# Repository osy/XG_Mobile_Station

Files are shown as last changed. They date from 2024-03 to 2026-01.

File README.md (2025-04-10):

XG Mobile Dock
==============
This open source hardware allows you to connect any PCIe card to an ASUS ROG device with the XG Mobile connector.

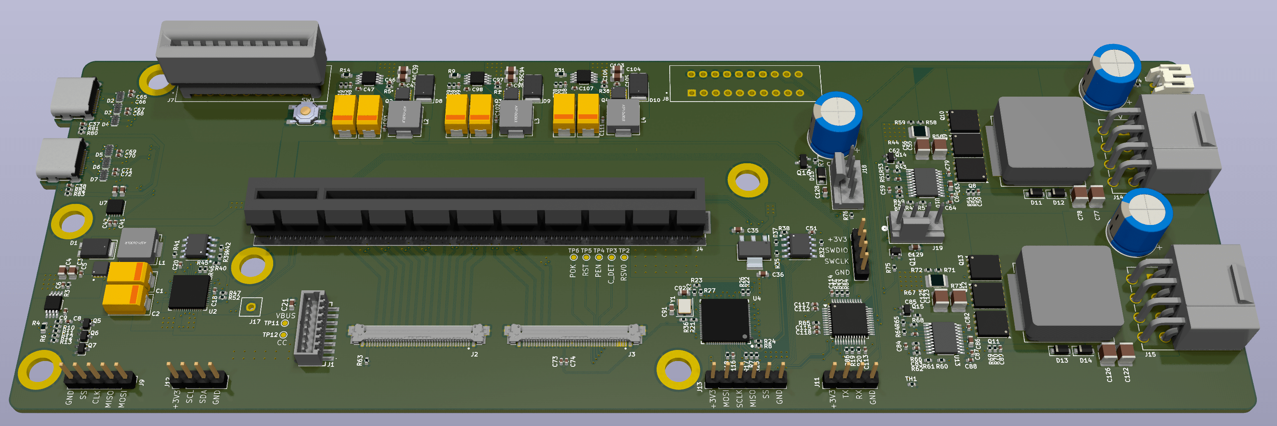
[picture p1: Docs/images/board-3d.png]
Board 3D model


The standard variant is a drop-in replacement PCB for the [XG Station Pro Thunderbolt 3 eGPU dock][1]. It contains a built in USB 3.1 Gen 2 hub and a USB PD charger.

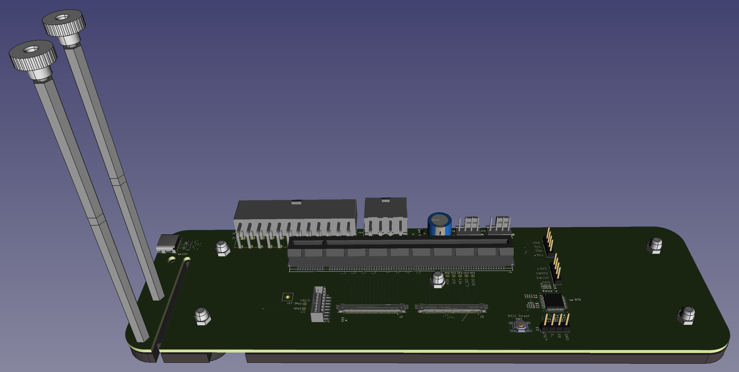
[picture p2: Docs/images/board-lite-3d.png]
Board 3D model


The lite variant is a standalone board that is compatible in dimensions with the [ADT-UT3G][6]. It requires a standard ATX power supply and passes through the USB to an external port.

## Features
* Up to PCIe 4.0 x8 support for 2021/2022/2023 ROG Flow
* Up to PCIe 4.0 x4 support for 2023 ROG Ally
* MCU handling cable detection and LEDs
* 65W USB PD charger (standard variant)
* 2 USB-C ports connected to a USB 3.1 Gen 2 hub (standard variant)
* 300W DC-DC power supply (standard variant)

## Getting Started
1. [Build the PCB](Docs/Build_Guide.md)
2. [Flash the board](#flashing-firmware)
3. [Install the software](#install-xgmactivator)

### Flashing Firmware
Lite boards only need to flash STM32 while the standard board requires writing two SPI flash as well.

#### STM32 MCU
1. Download `XG_Mobile_Dock_MCU.bin` from the latest release or [build your own](Docs/Build_Guide.md#mcu).
2. Download and install [ST32CubeProgrammer][2].
3. Connect your ST-LINK v2 to your computer. Note if you are using a cheap clone from Amazon or Aliexpress, the pin numbers printed on the device may be incorrect.
4. Connect the SWDIO, SWCLK, and GND pins to J10 on the board to the ST-LINK v2. Do not connect +3V3. If you are using an official ST-LINK, you will need a jumper wire from VAPP (pin 1) to VDD (pin 19).
5. Ensure the board is powered on so it can be programmed.
6. Open ST32CubeProgrammer and go to the "Erasing & programming" page (second icon on the left sidebar).
7. Browse and select the firmware file.
8. Check "Run after programming"
9. Click "Connect" on the right sidebar and then "Start Programming" on the left.

#### SPI Flash for TI USB PD
We will be using a Raspberry Pi, although most other SBC can also work as well as dedicated SPI flashers.

1. [Enable the SPI interface on the Raspberry Pi.][3]
2. Connect GND (Ground), SS (SPI0 CE0), CLK (SPI0 SCLK), MISO (SPI0 MISO), and MOSI (SPI0 MOSI) on J9 [to the Raspberry Pi][4].
3. Open a shell to the Raspberry Pi and install Flashrom: `sudo apt-get install flashrom`
4. Download `XG_Mobile_Dock_Charger.bin` from the latest release or [build your own](Docs/Build_Guide.md#ti-pd-controller).
5. Flash the firmware: `sudo flashrom -p linux_spi:dev=/dev/spidev0.0,spispeed=1000 -w XG_Mobile_Dock_Charger.bin`

#### SPI Flash for VIA USB Hub
We will be using a Raspberry Pi, although most other SBC can also work as well as dedicated SPI flashers.

1. [Enable the SPI interface on the Raspberry Pi.][3]
2. Connect GND (Ground), SS (SPI0 CE0), CLK (SPI0 SCLK), MISO (SPI0 MISO), and MOSI (SPI0 MOSI) on J13 [to the Raspberry Pi][4]. Note the order of the pins is different from J9.
3. Open a shell to the Raspberry Pi and install Flashrom if it is not already installed: `sudo apt-get install flashrom`
4. Download `VL822_Q7_9043_Phantom_20220616.bin` from the latest release.
5. Flash the firmware: `sudo flashrom -p linux_spi:dev=/dev/spidev0.0,spispeed=1000 -w VL822_Q7_9043_Phantom_20220616.bin`

### Install XGMDriver
XGMDriver tricks ARMORY CRATE software into identifying the custom dock as an official XG Mobile device. Once installed, it should work even if ARMORY CRATE software is updated. You can check out the [source code here](XGMDriver).

1. Download `XGMDriverSetup.exe` from the latest release.
2. Run the installer making sure to correctly select AMD or NVIDIA depending on the vendor of the GPU you are installing.
3. If you need to swap between AMD and NVIDIA, uninstall from Control Panel or by running the installer again. Then you can re-install and select the right option.

## Troubleshooting

### Error 43 or no video output on NVIDIA GPUs
This is a well known issue with NVIDIA eGPUs. Once the eGPU is installed along with the correct drivers, you will need to install [this script][5].

### PCIe is only getting 3.0 speeds after hot plugging
You need to restart your device. For some reason, hot plugging results in 3.0 speeds.

### Unable to get 4.0 speeds
If you observe any of the following:
* GPU-Z changes between 4.0 and lower versions *when under load*
* You observe a lot of stuttering or < 10 FPS in 1% lows
* Windows behaves extremely slowly (moving the mouse cursor will take > 1 sec to respond)
* Event viewer for System shows multiple times: "WHEA-Logger Event ID:17 - A corrected hardware error has occurred"

Then the device is having trouble sustaining PCIe 4.0 speeds. This can be caused by any combination of the following issues:

1. The board was not manufactured properly with impedance matching or the high speed connectors were not properly soldered. Verify that the boards were manufactured with the correct specifications and test multiple boards.
2. The GPU is malfunctioning or is not mounted correctly. Make sure you can obtain PCIe 4.0 speeds on a desktop PC.
3. The XGM cable is not connected to the board correctly. Make sure the two 40P connectors are tight and the metal bar is locked over the connector to prevent unintentional loosening. Make sure the shielding screw is tightly screwed to the screw terminal next to the connector. Make sure the cable isn't twisted or bent any more than it needs to be. If the XGM cable came coiled up, try to carefully straighten it.
4. The XGM cable is not manufactured correctly. The official XGM device only supports PCIe 3.0 speeds so the cable is only rated for PCIe 3.0. We found that some cables are easier to get 4.0 speeds working than other cables so there is some manufacturing variance.

You can run FurMark for a long duration and observe the GPU load to check that it is able to maintain 4.0 speeds. If the GPU is constantly trying to switch speeds, you will observe large FPS drops and large dips in the GPU usage percentage. You can also use CUDA-Z to check the access speeds while under load.

If you cannot maintain PCIe 4.0 speeds, you can always do a hot-unplug and hot-plug to force it to run in PCIe 3.0 mode.

### No popup when XGM is connected
Sometimes, the device will not be detected and you can flip the lock switch off and on again to force the software to re-detect the device.

### "It appears that your XG Mobile is not properly connected..."
If you get a pop-up saying XG Mobile is not properly connected, make sure [XGMDriver](#install-xgmdriver) is installed. If this is still an issue with XGMDriver installed, there is likely a connection issue with the cable.

### ASUS Driver install popup on reboot
Re-install XGMDriver to inhibit the ASUS driver popup.

### Lite: USB is not detected
The lite board does not have USB orientation detection. Try flipping the USB-C cable upside down and try again.

## References
Knowledge base for all things XGM gathered from reverse engineering the hardware and software.

* [XGM connector information](Docs/Connector.md)
* [XGM software interfaces](Docs/Software.md)
* [MCU command interface](Docs/MCU.md)
* [PCB design diary](Docs/Diary.md)
* [Reversed ACPI tables](Docs/ACPI_Annotated.asl)
* [Reversed BIOS detection](Docs/BIOS_Detect.c)

## Related Projects

* [Modified Lite design with redrivers for improved performance (not yet working)](https://github.com/Alecu100/XG_Mobile_Station/tree/flow_v2)

[1]: https://www.asus.com/motherboards-components/external-graphics-docks/all-series/xg-station-pro/
[2]: https://www.st.com/en/development-tools/stm32cubeprog.html
[3]: https://www.raspberrypi-spy.co.uk/2014/08/enabling-the-spi-interface-on-the-raspberry-pi/
[4]: https://pinout.xyz
[5]: https://egpu.io/nvidia-error43-fixer
[6]: https://www.adt.link/product/UT3G.html

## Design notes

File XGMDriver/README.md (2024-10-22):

XGM Driver
==========
This UMDF driver provides a virtual HID device that will interface with ARMORY CRATE SE to trigger the activation pop-up.

See [Software.md](../Docs/Software.md) for more details.

## Building

1. Install [Visual Studio 2022 Community Edition and WDK][1].
2. Install [NSIS][2].
3. Run `build.bat`. If prompted to enter a password to protect the generated private key, press "None".

[1]: https://learn.microsoft.com/en-us/windows-hardware/drivers/download-the-wdk
[2]: https://nsis.sourceforge.io/Download

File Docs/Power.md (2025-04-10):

The XG Mobile Station adopts the 20P slot which mates with a daughter card that hosts a special connector that is found on the XG Station Pro's power supply. You may want to replace this card in order to use a higher wattage or smaller sized power supply or to build a custom enclosure for the XG Mobile Station without needing to source the special power supply and daughter card.

## XG Mobile Power

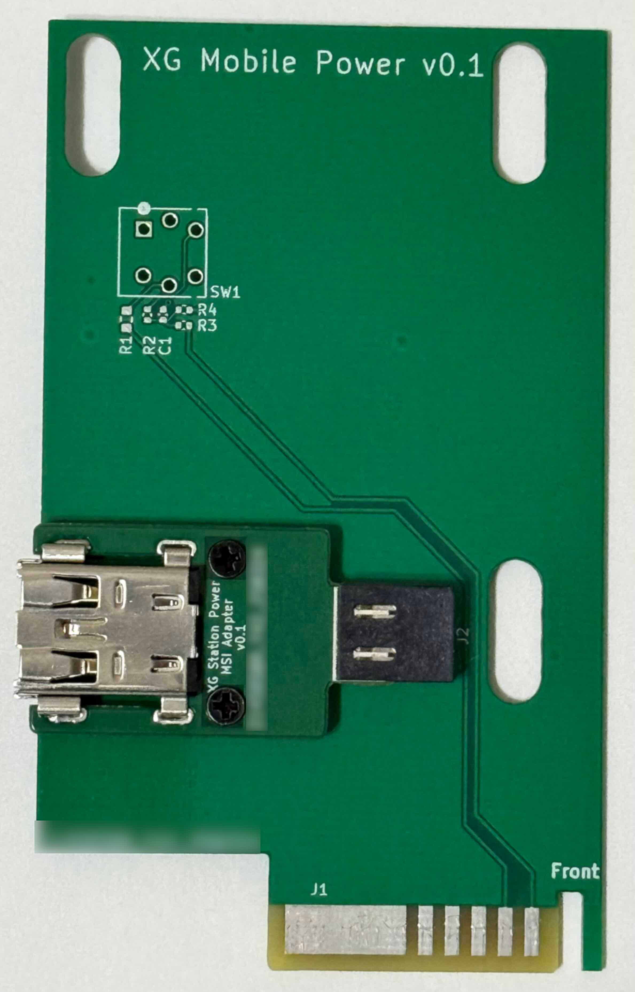
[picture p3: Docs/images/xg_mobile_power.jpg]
XG Mobile Power


The custom power adapter card is built to support the MSI 8P connector, which is used on some high-end MSI laptops. Why choose another proprietary port? The first reason is that there are no "standard" DC power connector that supports 20V at > 16A. The closest is the 7.4mmx5mm barrel jack, but standard parts for this port (PJ-096H) cannot handle more than 8A. Laptop manufactures that uses this port for higher wattages use a proprietary part that does not solder directly to the PCB but instead adapts it to a custom connector. The second reason is that at the time of writing, the highest wattage AC-DC 20V power supply you can easily buy at online retailers is 400W and it uses the MSI 8P connector.

### Parts Needed

* XG Mobile Power board: go to [releases](https://github.com/osy/XG_Mobile_Station/releases) and download `GERBER-XG_Station_Power.zip`. Upload it to a JLCPCB or another manufacturer and purchase it with the default settings.
* XG Mobile Power MSI addon board: go to [releases](https://github.com/osy/XG_Mobile_Station/releases) and download `GERBER-XG_Station_Power_MSI.zip`. Upload it to a JLCPCB or another manufacturer and purchase it with the default settings.
* MSI 8P port: You can find this part on AliExpress with a title such as "MSI GP76 GP66 Charging Port USB Square Connector" for about $1 USD a piece ([example listing](https://www.aliexpress.us/item/3256806058519484.html))
* M2x8 screws
* M2 spacers: They should be 2.3mm thickness or you can stack two 1mm thick spacers ([example listing](https://www.aliexpress.us/item/2251832835568550.html)) with one 0.3mm spacer ([example listing](https://www.aliexpress.us/item/2255799988145316.html))
* M2 brass nut: The length should be at least 2mm ([example listing](https://www.aliexpress.us/item/3256804349544912.html)) 
* [TE 2351970-1 power assembly](https://www.te.com/en/product-2351970-1.html)

### Assembly

Once you have the boards, first solder the MSI 8P connector to the smaller board and the TE 2351970-1 connector to the larger board. Then place the spacer between the two boards and run the screw into the assembly. Thread it into the brass nut on underside of the board.

For XG Mobile Station, you do not need the power button (SW1) and can leave it unpopulated. If you want to use this in the original Thunderbolt 3 enclosure, you need to transfer the switch and the passives under it over from the original board to the custom board.

### 7.4mm Adapter

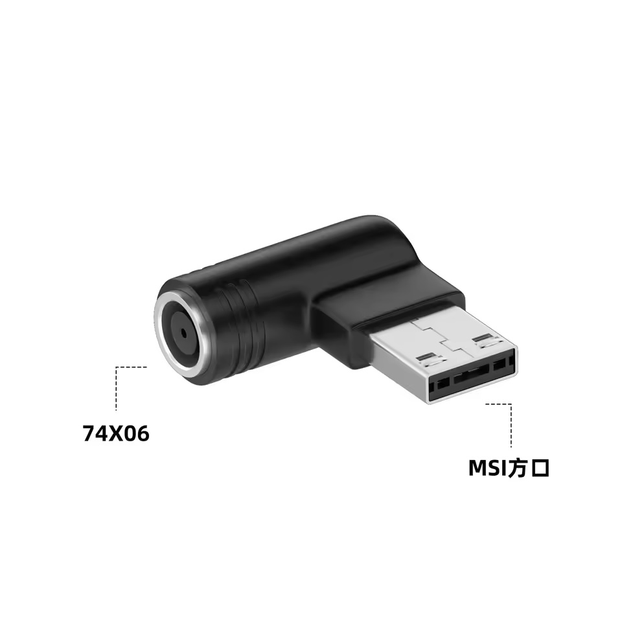
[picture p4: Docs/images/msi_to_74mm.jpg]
7.4mm adapter


You can also purchase a MSI 8P to 7.4mm barrel jack adapter on AliExpress for around $5 USD ([example listing](https://www.aliexpress.us/item/3256807588959754.html)) and this will allow you to use the more common 7.4mm barrel connector. Note that you should avoid the variant which has a cable with two ends because there is no guarantee that the adapter will be able to handle the high current load.

## USB Charging

If you use a higher wattage power supply, you may wish to flash the 100W charging profile found in [releases](https://github.com/osy/XG_Mobile_Station/releases) (titled `XG_Mobile_Dock_Charger_100W.bin`). The default profile will be limited to 65W.

## Example Supplies

Here is a sample selection of high wattage supplies that you can buy on online retailers which are compatible with the XG Mobile Station. Note that any 20V supply will work but a graphics card with 2x 8-pin connectors can draw up to 300W and the USB charger can draw up to 65/100W (depending on the firmware) so you must pick a supply that can handle the load.

| Vendor | Model | Wattage | Connector | Adapter | Notes |
|---|---|---|---|---|---|
| ASUS | ADP-330AB  | 330W | XG Station Pro | Stock | |
| MSI | ADP-400CB  | 400W | MSI 8P | Custom | |
| MSI | ADP-330GB  | 330W | MSI 8P | Custom | |
| Dell | ADP-330AB  | 330W | 7.4mmx5mm Barrel | Custom + MSI-7.4mm Adapter | Same supply as stock, but different connector |
| Dell | LA360PM230 | 360W | 7.4mmx5mm Barrel | Custom + MSI-7.4mm Adapter | GaN based, small size |

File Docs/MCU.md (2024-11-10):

On the real XG Mobile, the MCU is an ITE chip which is a similar design to the Embedded Controller on the Ally. It is responsible for the following:

1. Toggling the [connector signals](Connector.md).
2. Communicating with the host's EC over I2C.
3. Communicating with the [Windows](Software.md#externalgpuconfighelper2dll) over USB HID.

In order to save costs and reduce complexity, our MCU is a STM32 which implements 1 and 2 but not 3. Since the main reason to communicate with Windows is to control fans (not available here) and to pass in serial and model information (can be done with software), we do not implement 3 which requires a USB PHY on the MCU.

## I2C
The I2C/SMBus pins from the connector is hooked up to the host's EC. The MCU communicates with the EC through this I2C bus (in addition to the status pins). The importance of the I2C bus is that upon reboot, a successful handshake must take place or the host will throw a splash image indicating the XG Mobile has been disconnected (see [the code](BIOS_Detect.c) for more details).

These are the commands supported by the real XG Mobile MCU:

| Command (Byte 0) | Byte 1 | Byte 2 | Remaining | Direction | Description |
|---|---|---|---|---|---|
| 0xA0 | Register Number | Length | Data | Host to Device | Write Register  |
| 0xA1 | - | - | 0xD2, 0xDA, 0xDB, or 0xDC | Device to Host | Get event? |
| 0xA2 | - | - | 0x01 or 0x02 | Device to Host | Session status? |
| 0xA3 | - | - | 0x01 | Device to Host | Heartbeat? |

These are the registers:

### Connect Sequence (Boot)

1. Host send: `A0 07 01 01`
2. Host send: `A0 01 01 00`
3. Host send: `A0 0A 01 04`
4. MCU asserts IRQ
5. Host send: `A1`, MCU respond: `DC`, deasserts IRQ
6. Host send: `A2`, MCU respond: `02`
7. Host send: `A0 08 01 01`
8. Host send: `A0 08 01 01`
9. Host send: `A0 09 01 00`
10. Host send: `A0 09 01 01`
11. Host send: `A0 09 01 01`
12. Host send: `A3`, MCU respond: `01` (repeat ad infinitum every second)

### Connect Sequence (XGM Disconnected on Boot)

1. Host send: `A0 07 01 01`
2. Host send: `A0 01 01 00`
3. Host send: `A0 0A 01 01`
4. MCU asserts IRQ
5. Host send: `A1`, MCU respond: `DC`, deasserts IRQ
6. Host send: `A2`, MCU respond: `02`

Press A to continue

1. Host send: `A0 08 01 01`
2. MCU asserts PWROK
3. Host de-asserts RST
4. Host send: `A0 09 01 00`
5. Host send: `A0 09 01 01`
6. Host send: `A0 09 01 01`
7. Host send: `A0 0A 01 02` (only sometimes?)
8. Host send: `A3`, MCU respond: `01` (repeat ad infinitum every second)

### Connect Sequence (Windows)

1. Host send: `A0 07 01 01`
2. Host send: `A0 01 01 00`
3. MCU asserts IRQ
4. Host send: `A1`, MCU respond: `DC`, deasserts IRQ
5. Host send: `A2`, MCU respond: `02`
6. Host send: `A0 0A 01 04`

XGM connect popup appears, user must click connect

1. Host send: `A0 08 01 01`
2. MCU asserts PWROK
3. Host de-asserts RST
4. Host send: `A0 09 01 01`
5. Host send: `A3`, MCU respond: `01` (repeat ad infinitum every second)

### Disconnect Sequence (Windows)

1. Host send: `A0 08 01 00`
2. Host stops sending `A3` after 2 more seconds

### Reconnect Sequence (Windows)

1. Host send: `A0 08 01 01`
2. Host send: `A3`, MCU respond: `01` (repeat ad infinitum every second)

### Shutdown Sequence (Windows)

1. Host send: `A0 0D 01 01`
2. Host send: `A0 09 01 00`
3. Host send: `A0 09 01 00`
4. Host send: `A0 01 01 05`
5. MCU asserts IRQ
6. Host send: `A1`, MCU respond: `DC`, deasserts IRQ
7. Host send: `A2`, MCU respond: `01`

## Embedded Controller
This information was gained by sniffing the I2C bus with a logic analyzer and also by reverse engineering the EC firmware. The EC for the ROG Ally can be found [here][1] and the MCU firmware for the 2021 XG Mobile can be found [here][2]. The ROG Ally has two chips a main controller and a secondary controller. Along with the XG Mobile's MCU, all three chips are different variants of ITE's embedded controller.

For reverse engineering the firmware, Google's [Chromebook EC firmware][3] is a good source of reference because it contains support code for a different model of ITE chip that uses the same ISA and has a similar memory layout. For disassembly, you need to build Ghidra with [NDS32 support][4].

[1]: https://dlcdnets.asus.com/pub/ASUS/GamingNB/RC71L/ROGMCUFWUpdateTool_OneKey_v3.8.0.011.zip
[2]: https://dlcdnets.asus.com/pub/ASUS/GamingNB/GC31S/ROGGC31FWUpdateTool_OneKey_V1.1.0.2.exe.zip
[3]: https://chromium.googlesource.com/chromiumos/platform/ec/+/HEAD/chip/it83xx/
[4]: https://github.com/NationalSecurityAgency/ghidra/pull/1778

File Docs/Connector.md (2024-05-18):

These are notes written up about the XG Mobile connector which is found on the Asus ROG Ally as well as some ROG Flow models. The goal is to build a custom eGPU enclosure that is compatible with the XG Mobile connector.

## XG Mobile Cable
The XG Mobile Cable comes with ROG XG Mobile and can be purchased from a [parts store][2] for $129 USD. It has a male XG Mobile Connector on one end and three cables on the other end: two 40-pin FPC cables and a 8-pin connector. The cable carries a USB-C connection, PCIe x8 signal pairs, PCIe clock, an SMBus/I2C connection, and some sideband signals for power detection and hot-plug support.

### XG Mobile Connector
The pinout can be obtained from the [GV301QC schematic][1] (page 69).
| Pin | Name | Pin | Name |
|-----|---|-----|---|
| C1  | PCIENB_TXP0_C  | D1  | PCIENB_TXP5_C |
| C2  | PCIENB_TXN0_C  | D2  | PCIENB_TXN5_C |
| C3  | GND12 | D3  | GND21 |
| C4  | PCIENB_RXP0_C  | D4  | PCIENB_RXP5_C |
| C5  | PCIENB_RXN0_C  | D5  | PCIENB_RXN5_C |
| C6  | GND11 | D6  | GND20 |
| C7  | PCIENB_TXP1_C  | D7  | PCIENB_TXP6_C |
| C8  | PCIENB_TXN1_C  | D8  | PCIENB_TXN6_C |
| C9  | GND10 | D9  | GND19 |
| C10 | PCIENB_RXP1_C  | D10 | PCIENB_RXP6_C |
| C11 | PCIENB_RXN1_C  | D11 | PCIENB_RXN6_C |
| C12 | GND9 | D12 | GND18 |
| C13 | PCIENB_TXP2_C  | D13 | PCIENB_TXP7_C |
| C14 | PCIENB_TXN2_C  | D14 | PCIENB_TXN7_C |
| C15 | GND8 | D15 | GND17 |
| C16 | PCIENB_RXP2_C  | D16 | PCIENB_RXP7_C |
| C17 | PCIENB_RXN2_C  | D17 | PCIENB_RXN7_C |
| C18 | GND7 | D18 | GND16 |
| C19 | PCIENB_TXP3_C  | D19 | GPU_PCIE_CLKP |
| C20 | PCIENB_TXN3_C  | D20 | GPU_PCIE_CLKN |
| C21 | GND6 | D21 | GND15 |
| C22 | PCIENB_RXP3_C  | D22 | Reserve_NB |
| C23 | PCIENB_RXN3_C  | D23 | CON_SW1_DET_NB |
| C24 | GND5 | D24 | AGPU_SMB1_CLK |
| C25 | PCIENB_TXP4_C  | D25 | AGPU_SMB1_DAT |
| C26 | PCIENB_TXN4_C  | D26 | EC_ACGPU_MCU_IRQ# |
| C27 | GND4 | D27 | P_AC_LOSS_10 |
| C28 | PCIENB_RXP4_C  | D28 | DGPU_PWROK |
| C29 | PCIENB_RXN4_C  | D29 | GPU_RST# |
| C30 | GND3 | D30 | DGPU_PWR_EN# |
| C31 | CON_DET_TOWER# | D31 | CON_DET_NB |
| A1  | GND2 | B12 | GND14 |
| A2  | TX1+ | B11 | RX1+ |
| A3  | TX1- | B10 | RX1- |
| A4  | VBUS2 | B9  | VBUS4 |
| A5  | CC1 | B8  | SBU2 |
| A6  | D+1 | B7  | D-2 |
| A7  | D-1 | B6  | D+2 |
| A8  | SBU1 | B5  | CC2 |
| A9  | VBUS1 | B4  | VBUS3 |
| A10 | RX2- | B3  | TX2- |
| A11 | RX2+ | B2  | TX2+ |
| A12 | GND1 | B1  | GND13 |

### 40-pin connectors
Each 40-pin cable is terminated into a [CABLINE-VS connector][6]. The official Asus part number for this connector is 12017-00180600 and can be purchased from the parts store (usually with a mislabeled part number) such as [here][3].

Note that signal names are with respect to the host meaning that TX means host transmitter and RX means host receiver. In order of the longer cable first, the pinout for the two connectors are as follows:

| Pin | Connector | Description |
|-----|---|---|
| 1 | D8 | PCIENB_TXN6_C  |
| 2 | D7 | PCIENB_TXP6_C  |
| 3 | GND | |
| 4 | D5 | PCIENB_RXN5_C  |
| 5 | D4 | PCIENB_RXP5_C  |
| 6 | GND | |
| 7 | D2 | PCIENB_TXN5_C  |
| 8 | D1 | PCIENB_TXP5_C  |
| 9 | GND | |
| 10  | C29 | PCIENB_RXN4_C  |
| 11  | C28 | PCIENB_RXP4_C  |
| 12  | GND | |
| 13  | C26 | PCIENB_TXN4_C  |
| 14  | C25 | PCIENB_TXP4_C  |
| 15  | GND | |
| 16  | C23 | PCIENB_RXN3_C  |
| 17  | C22 | PCIENB_RXP3_C  |
| 18  | GND | |
| 19  | C20 | PCIENB_TXN3_C  |
| 20  | C19 | PCIENB_TXP3_C  |
| 21  | GND | |
| 22  | C17 | PCIENB_RXN2_C  |
| 23  | C16 | PCIENB_RXP2_C  |
| 24  | GND | |
| 25  | C14 | PCIENB_TXN2_C  |
| 26  | C13 | PCIENB_TXP2_C  |
| 27  | GND | |
| 28  | C11 | PCIENB_RXN1_C  |
| 29  | C10 | PCIENB_RXP1_C  |
| 30  | GND | |
| 31  | C8 | PCIENB_TXN1_C  |
| 32  | C7 | PCIENB_TXP1_C  |
| 33  | GND | |
| 34  | C5 | PCIENB_RXN0_C  |
| 35  | C4 | PCIENB_RXP0_C  |
| 36  | GND | |
| 37  | C2 | PCIENB_TXN0_C  |
| 38  | C1 | PCIENB_TXP0_C  |
| 39  | GND | |
| 40  | C31 | CON_DET_TOWER# |

| Pin | Connector | Description |
|-----|---|---|
| 1 | N/C | 3.3V to cable |
| 2 | N/C | 3.3V to cable |
| 3 | N/C | 3.3V to cable |
| 4 | N/C | 3.3V to cable |
| 5 | N/C | Lock switch |
| 6 | N/C | White LED switch (GND = on) |
| 7 | N/C | Red LED switch (GND = on) |
| 8 | N/C | Hidden switch on side of connector |
| 9 | D23 | CON_SW1_DET_NB |
| 10  | D22 | Reserve_NB |
| 11  | D31 | CON_DET_NB |
| 12  | D30 | DGPU_PWR_EN# |
| 13  | D29 | GPU_RST# |
| 14  | D28 | DGPU_PWROK |
| 15  | D27 | P_AC_LOSS_10 |
| 16  | D26 | EC_ACGPU_MCU_IRQ# |
| 17  | GND | |
| 18  | D25 | AGPU_SMB1_DAT |
| 19  | D24 | AGPU_SMB1_CLK |
| 20  | GND | |
| 21  | A7 | USB D- |
| 22  | A6 | USB D+ |
| 23  | GND | |
| 24  | B10 | USB RX- |
| 25  | B11 | USB RX+ |
| 26  | GND | |
| 27  | A3 | USB TX- |
| 28  | A2 | USB TX+ |
| 29  | GND | |
| 30  | D20 | GPU_PCIE_CLKN |
| 31  | D19 | GPU_PCIE_CLKP |
| 32  | GND | |
| 33  | D17 | PCIENB_RXN7_C |
| 34  | D16 | PCIENB_RXP7_C |
| 35  | GND | |
| 36  | D14 | PCIENB_TXN7_C |
| 37  | D13 | PCIENB_TXP7_C |
| 38  | GND | |
| 39  | D11 | PCIENB_RXN6_C |
| 40  | D10 | PCIENB_RXP6_C |

### 8-pin connector
This seems like a standard pin connector. The pitch is 1.50mm. Part number is [5-1775443-8][7].

| Pin | Connector | Description |
|-----|---|---|
| 1 | GND | |
| 2 | GND | |
| 3 | GND | |
| 4 | A5 | USB CC |
| 5 | ? | Shorted to VBUS |
| 6 | VBUS | USB VBUS |
| 7 | VBUS | USB VBUS |
| 8 | VBUS | USB VBUS |

## Signals
Here's what can be learned from looking at the [GV301QC schematic][1]. The PCIe pairs are connected to a series of muxes which can be controlled by the APU to switch between the dGPU and eGPU. The USB-C is connected directly to the system's USB circuits and does not seem to be re-purposed for any alternative usage.

`CON_DET_TOWER#`, `EC_ACGPU_MCU_IRQ#`, `P_AC_LOSS_10`, and the SMBus goes to a IT5125VG-192 which is the EC (embedded controller) that usually handles system tasks and power management (no datasheet is available for this model).

`CON_DET_TOWER#` and `P_AC_LOSS_10` are fed into a MOSFET circuit for some kind of power detection.

`CON_SW1_DET_NB` is passed to both the APU and the EC as GPIO and is likely the way that the BIOS detects a connection. `CON_DET_NB` is shorted to GND and indicates to the eGPU of a connection.

`DGPU_PWROK`, `GPU_RST#`, `DGPU_PWR_EN#` are connected to the APU as GPIOs.

### Connection handshake

1. When connector is plugged in, `CON_DET_TOWER#` is asserted (active low) by the eGPU and the host EC detects the connection. The eGPU detects `CON_DET_NB` shorted to GND and knows that the host is connected. The eGPU also de-asserts `P_AC_LOSS_10` (pull down) to indicate AC power is connected.
2. When the connector lock is switched on, pin 5 on the 40P connector is shorted to GND and the eGPU detects this and asserts `CON_SW1_DET_NB`.
3. The host requests the eGPU to be powered on by asserting `DGPU_PWR_EN#` (active low) and `GPU_RST#` (active low).
4. The eGPU powers on the GPU and asserts `DGPU_PWROK`.
5. The host de-asserts `GPU_RST#`.
6. At this point, the connection is established and the host beings PCIe RX detection and link training.

## References

* [ASUS GV301QC Schematics & Board][1]
* [XG Mobile Cable][2], [40-pin connector][3], [8-pin connector][4], [XG Mobile connector][5]

[1]: https://www.badcaps.net/forum/troubleshooting-hardware-devices-and-electronics-theory/troubleshooting-laptops-tablets-and-mobile-devices/schematic-requests-only/1039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
[2]: https://www.a-accessories.com/asus-connection-cable-62505-79153.htm
[3]: https://www.a-accessories.com/asus-attach-system-40-pins-87588-67468.htm
[4]: https://www.a-accessories.com/asus-rog-flow-8-pin-connector-88837-78465.htm
[5]: https://www.a-accessories.com/rog-ally-accessories/ally-spare-parts/asus-rog-flow-dock-connector-92127-88896.htm
[6]: https://www.i-pex.com/product/cabline-vs
[7]: https://www.te.com/en/product-5-1775443-8.html

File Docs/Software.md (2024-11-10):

Software support for XG Mobile is implemented in Armoury Crate and ASUS Hotkeys driver. This document notes some of the findings from reverse engineering key pieces of the software found in `C:\Program Files\ASUS\ARMOURY CRATE SE Service\GPUSwitchPlugin`.

## GPUSwitchPlugin.dll
This is the main executable loaded by Armoury Crate to handle eGPU events. ASUS Hotkeys is typically used in ASUS systems to handle special keyboard keys and function keys. You can read the [Linux driver][1] to see examples of the kinds of events that are handled by AKS. On the ROG Ally, some special keys are used to handle eGPU events. These are purely virtual key codes that do not correspond to a physical key event.

| Key Code | Name | Description |
|---|---|---|
| 0xB9 | Connect Change | eGPU connector is plugged/unplugged |
| 0xBA | Switch-Lock Change  | Connector lock is engaged (and ACKed by MCU) |
| 0xBB | External Power Loss | AC power is lost on the eGPU |
| 0xBC | ? | Seen when GPU eject request timed out |
| 0xC2 | Restart Required | Prompt the user to restart to enable eGPU |

These key events are emitted from ACPI handlers for the EC ([reverse engineered details can be found here](ACPI_Annotated.asl)). When `0xB9` is received, `ExternalGPUConfigHelper2.dll` is used to get the EGPUID which is parsed to the following registry entries (all this information is hard coded based on the EGPUID):

| Key | Value | Data Type | Data |
|---|---|---|---|
| HKLM\SOFTWARE\ASUS\eGPU | Current4Part  | String | `10de-249d-218b-1043`, `10de-249c-217b-1043`, `1002-73DF-21CB-1043`, `10de-2717-21fb-1043`, `10de-27a0-220b-1043` |
| HKLM\SOFTWARE\ASUS\eGPU | XGMobileModel | String | `GC31R`, `GC31S`, `GC32L`, `GC33Y`, `GC33Z` |
| HKLM\SOFTWARE\ASUS\eGPU | EVendor | DWORD | `0x0` = NVIDIA, `0x100` = AMD, `0x200` = Intel |
| HKLM\SOFTWARE\ASUS\eGPU | DockingGen | DWORD | PCIe generation: `3` or `4` |
| HKLM\SOFTWARE\ASUS\eGPU | SkipRLS | DWORD | `0` or `1` if VBIOS update is needed |
| HKLM\SOFTWARE\ASUS\ARMOURY CRATE Service\GPU Switch | ErrorReason | String | `NoPower` = any error trying to read EGPUID, `OldVBIOS` = eGPU is PCIe Gen 4 and host is Gen 4, `UpgradingVBIOS` = eGPU is PCIe Gen 4 and host is Gen 3, `OldBIOS` = if ACPI returns no support for this GPU vendor, `` = No error |

Note that if the XG Mobile is `GC31R`, `GC31S`, or `GC32L` and the host model is NOT `GV301Q`, then both the VBIOS and BIOS must be updated to force PCIe Gen 3 (according to the comment, PCIe Gen 4 is not stable).

The result of `HKLM\SOFTWARE\ASUS\ARMOURY CRATE Service\GPU Switch\ErrorReason` is written to `C:\ProgramData\ASUS\ARMOURY CRATE Service\GPUSwitch\settings.ini` under `Notify`.

When `0xBA` is received and both the connect status and lock status are 1, then `GPUTrayIcon.exe` is sent a message which writes `Notify=Verify` to `settings.ini`.

`GPUSwitchDialog.exe` is launched and depending on the value of `Notify` in `settings.ini`, will show a GUI alert. When in Verify and the user starts the connection process, a file `action.ini` is written with `GPUStatus=1` and in `settings.ini`, it writes `Notify=SwitchGPU` and `GPUSwitchPlugin.dll` will handle it.

Upon receipt of `SwitchGPU`, it opens a handle to `\\.\ATKACPI` which is used to call the `WMNB` [ACPI method](ACPI_Annotated.asl). Using the `DEVS` command with argument `0x00090019`, it will activate the eGPU. The ACPI method can return 0 for error, 1 for success, or 2 for reboot required. If no PCIe device is detected (VID/PID read returns 0xFFFFFFFF), then 2 is returned and the user is prompted to restart.

After restarting, if no PCIe device is found still, an error message is displayed indicating that the eGPU was improperly disconnected.

## ExternalGPUConfigHelper2.dll
This is managed C# code that implements a userland HID driver for communicating with the XG Mobile's eGPU. A HID device with usage page `0xFF31` and usage `0x80` is enumerated and if found will set a feature report with the data: `^ASUS Tech.Inc.\0`. If the report was set successfully, the device is valid and the driver can be used to do various things including reading the EGPUID, setting fan curves, setting other config, etc. Each command is implemented by setting a feature report followed by getting a feature report.

### GetEGPUID
#### Request
`5E CE 03`

### Response
| Offset | Size | Data |
|---|---|---|
| 0 | 3 | `5E CE 03` |
| 3 | 2 | ntohs(VID) |
| 5 | 2 | ntohs(PID) |
| 7 | 4 | ntohl(subsystem id) |
| 11 | 8 | ? |
| 19 | 3 | `GEN` |
| 22 | 1 | `\x01` |
| 23 | 1 | '1', '2', '3', '4', or '5' |
| 24 | 11 | Padding |
| 35 | 18 | Version |
| 53 | 207  | Padding |

Example: `5E CE 03 10 DE 24 9C 21 7B 10 43 00 FF FF FF FF FF FF FF 47 45 4E 01 33 FF FF FF FF FF FF FF FF FF FF FF 56 45 52 0E 39 34 2E 30 34 2E 34 33 2E 30 30 2E 65 66 FF FF FF FF FF FF FF FF FF FF FF FF FF FF FF FF FF FF FF FF FF FF FF FF FF FF FF FF FF FF FF FF FF FF FF FF FF FF FF FF FF FF FF FF FF FF FF FF FF FF FF FF FF FF FF FF FF FF FF FF FF FF FF FF FF FF FF FF FF FF FF FF FF FF FF FF FF FF FF FF FF FF FF FF FF FF FF FF FF FF FF FF FF FF FF FF FF FF FF FF FF FF FF FF FF FF FF FF FF FF FF FF FF FF FF FF FF FF FF FF FF FF FF FF FF FF FF FF FF FF FF FF FF FF FF FF FF FF FF FF FF FF FF FF FF FF FF FF FF FF FF FF FF FF FF FF FF FF FF FF FF FF FF FF FF FF FF FF FF FF FF FF FF FF FF FF FF FF FF FF FF FF FF FF FF FF FF FF FF FF FF FF FF FF FF FF FF FF FF FF FF FF FF FF FF FF 00`

### GetDockingSN
#### Request
`5E CE 01`

### Response
| Offset | Size | Data |
|---|---|---|
| 0 | 3 | `5E CE 01` |
| 3 | 51 | Serial number |

Example: `MB:ANF28MC0035;SN:XXXXXXYYYYYYYYY;PRO:GC31S;PNUM:;`

### DisableFanCurve
#### Request
`5E D1 02`

### GetEGPUConfig
#### Request
`5E CE 02`

#### Response
Example: `5E CE 02 11 00 EE FF 01 00 50 00 01 00 00 01 7E 0B 00 00 DE 10 9C 24 43 10 7B 21 01 01 03 00 00 00 00 00 00 00 00 00 00 00 00 00 A0 86 01 00 A0 86 01 00 40 0D 03 00 00 00 00 00 00 00 00 00 00 00 00 00 F0 49 02 00 F0 49 02 00 E0 93 04 00 00 00 00 00`

### GetFanCurveLowerLimit
#### Request
`5E D0 04`

#### Response
Example: `5E D0 04 00 00 00 00 20 32 40 4E`

### GetFanCurveTable
#### Request
`5E D0 XX`
XX = `00`, `01`, `02`, or `03`

#### Response
Example: `5E D0 01 3C 41 44 48 4B 4F 5C 5C 08 16 1D 24 2E 36 39 39`

### GetFanSpeed
#### Request
`5E C0 01 01 00 00 00 00 00 00 00 00 00 00 00 00`

### SetDockingLED
#### Request
Enable: `5E C5 80`
Disable: `5E C5 00`
???: `5E C5 50`

### SetEGPUConfig
#### Request
`5E CF 02 XX XX ...`

### SetFanCurve
#### Request
`5E D1 01 XX XX XX XX XX XX XX XX XX XX XX XX XX XX XX XX`

[1]: https://github.com/torvalds/linux/blob/master/drivers/platform/x86/acer-wmi.c

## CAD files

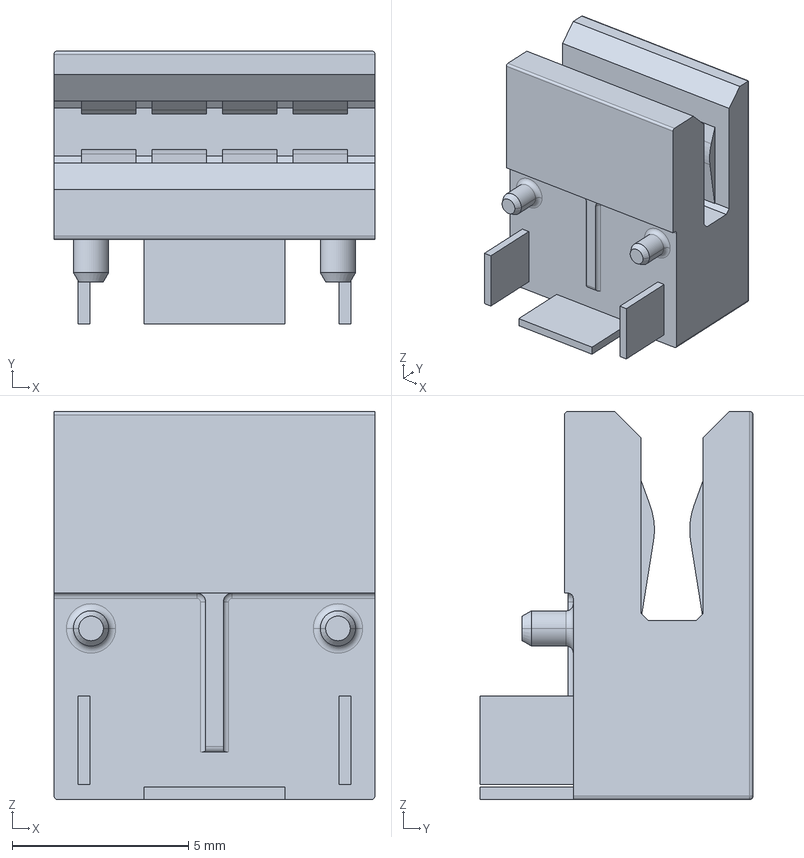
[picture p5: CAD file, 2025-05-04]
Models/c-2351970-1-5-3d.stp
9.10 x 7.75 x 11.0 mm

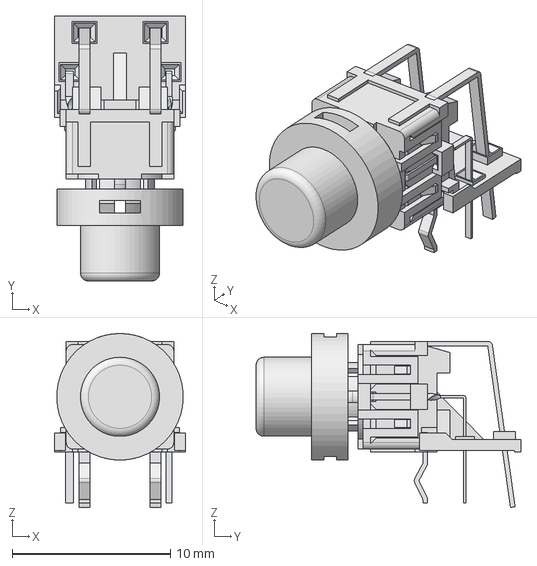
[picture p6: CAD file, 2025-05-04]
Models/TL1250FxxxxxRCLR.stp
8.30 x 16.8 x 11.0 mm

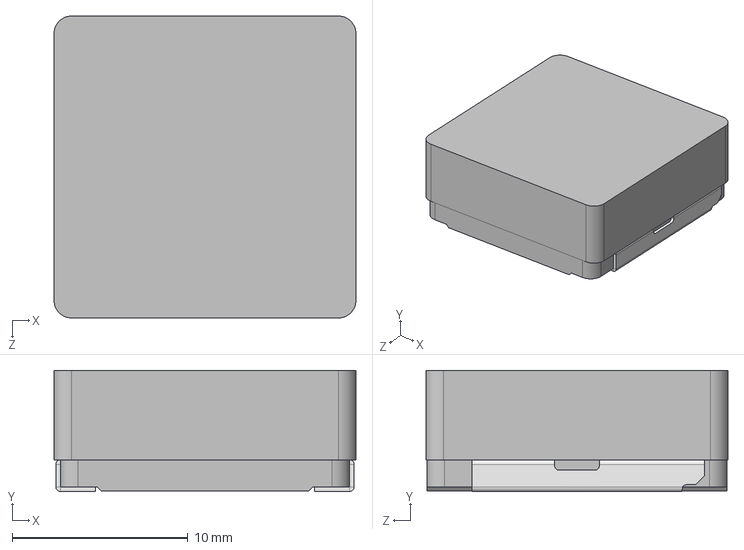
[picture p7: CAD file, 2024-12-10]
Models/IHLP6767GZ.step
17.2 x 6.88 x 17.2 mm

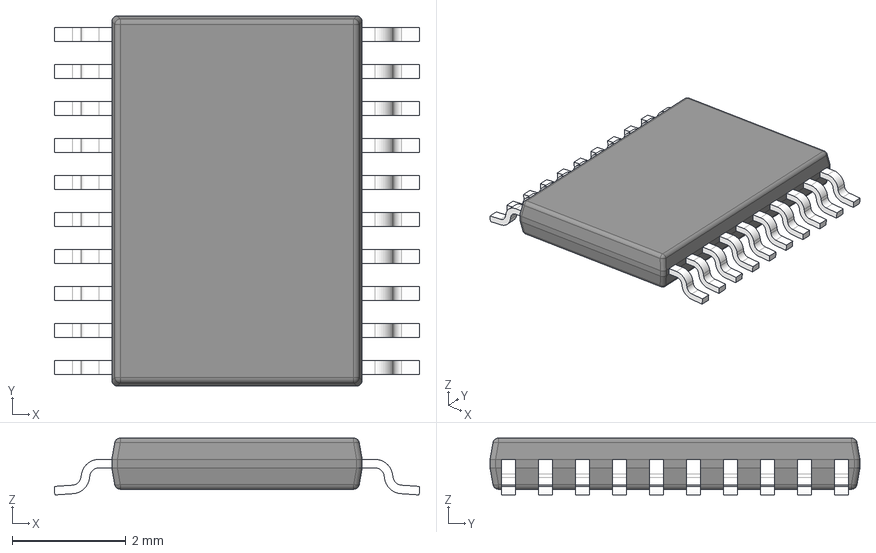
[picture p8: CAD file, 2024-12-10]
Models/LM5117PMH.stp
6.42 x 6.50 x 1.00 mm
BODY-SO
LEAD-SO x 20
THERMALPAD-SO
PIN1-ID

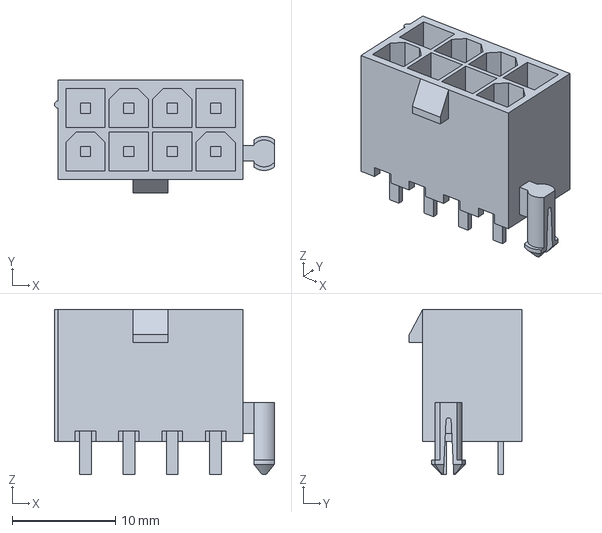
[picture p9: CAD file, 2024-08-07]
Models/3-1775099-2.stp
21.3 x 10.9 x 16.0 mm

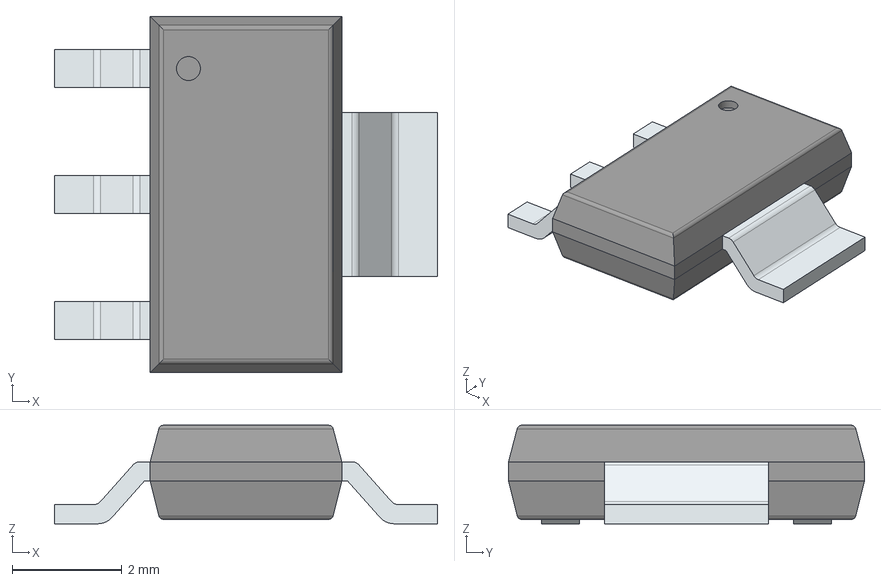
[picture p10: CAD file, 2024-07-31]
Models/AP7361-10ER-13.stp
7.00 x 6.50 x 1.80 mm
PinsArrayL
FilletPinR

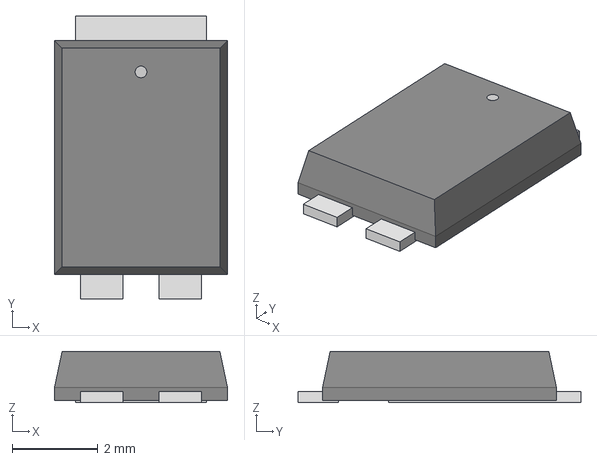
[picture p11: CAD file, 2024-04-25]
Models/POWERDI5_DIO.step
4.04 x 6.60 x 1.20 mm

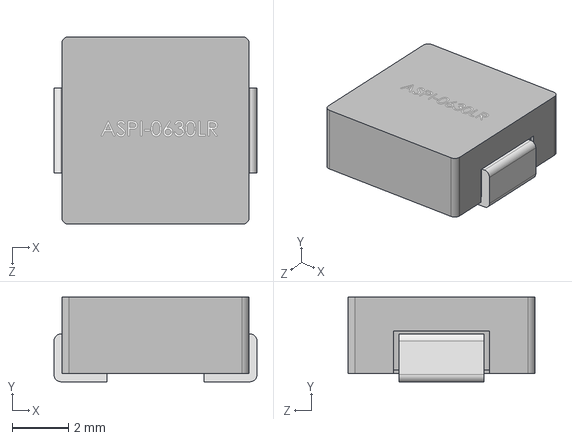
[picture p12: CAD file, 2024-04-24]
Models/ASPI-0630LR-100M-T15.STEP
7.20 x 3.00 x 6.65 mm

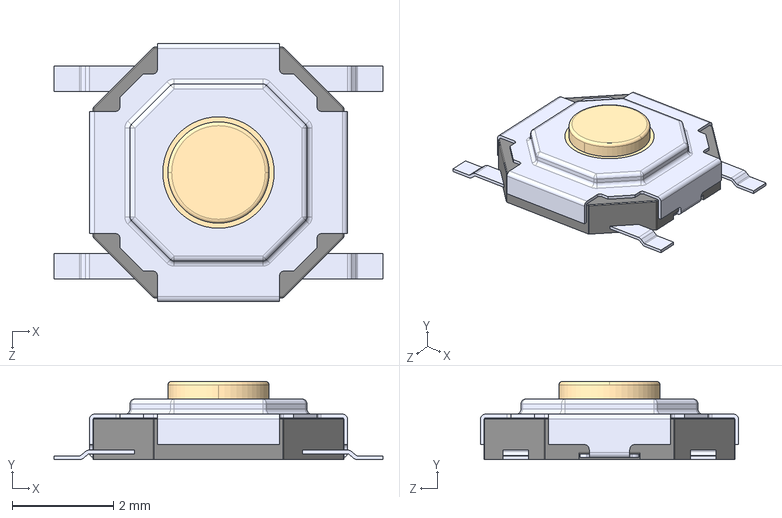
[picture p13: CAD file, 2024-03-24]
Models/TS-1187A-B-A-B.STEP
6.50 x 1.55 x 5.10 mm

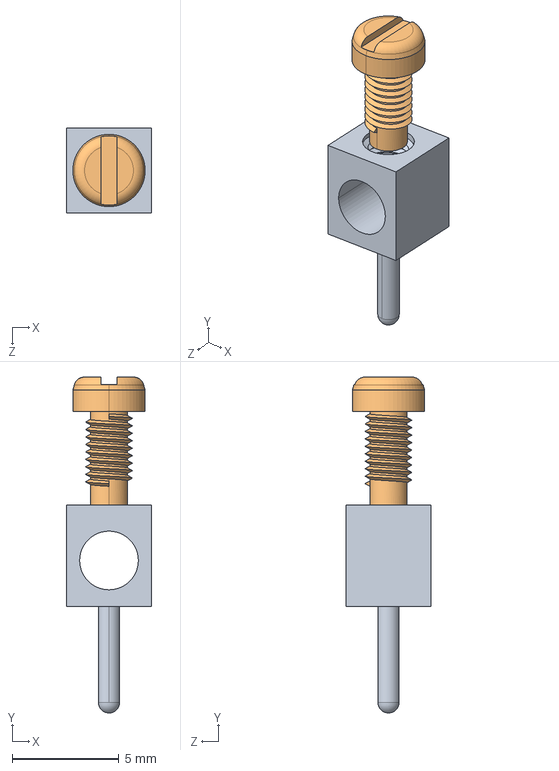
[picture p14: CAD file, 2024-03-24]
Models/KEYSTONE_8730.step
4.00 x 15.8 x 4.00 mm

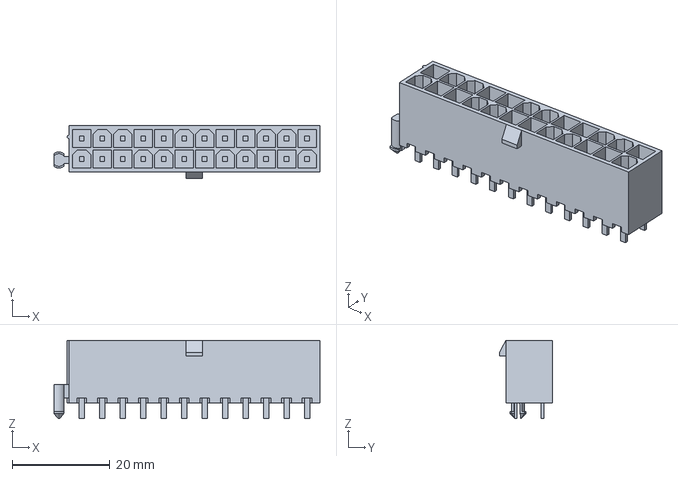
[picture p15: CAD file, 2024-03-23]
Models/1-1775099-3.step
54.6 x 10.9 x 16.0 mm

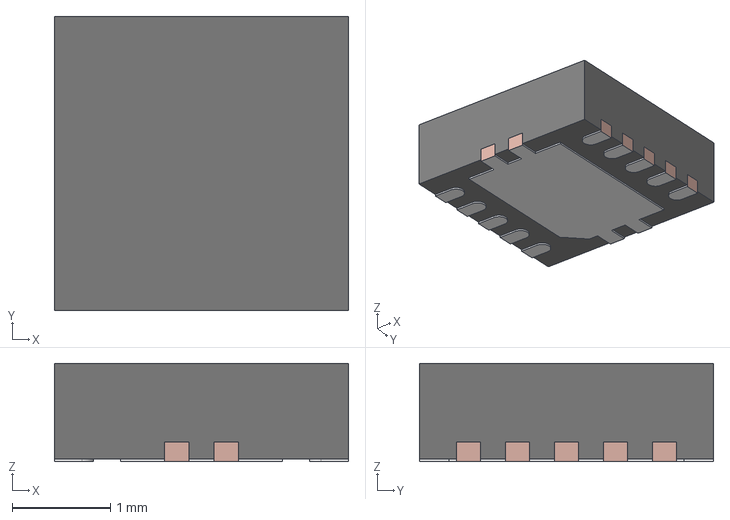
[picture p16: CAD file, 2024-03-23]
Models/TPS2003CDRCR.stp
3.00 x 3.00 x 1.00 mm
BODY-SON
FRAME-DRC0010J

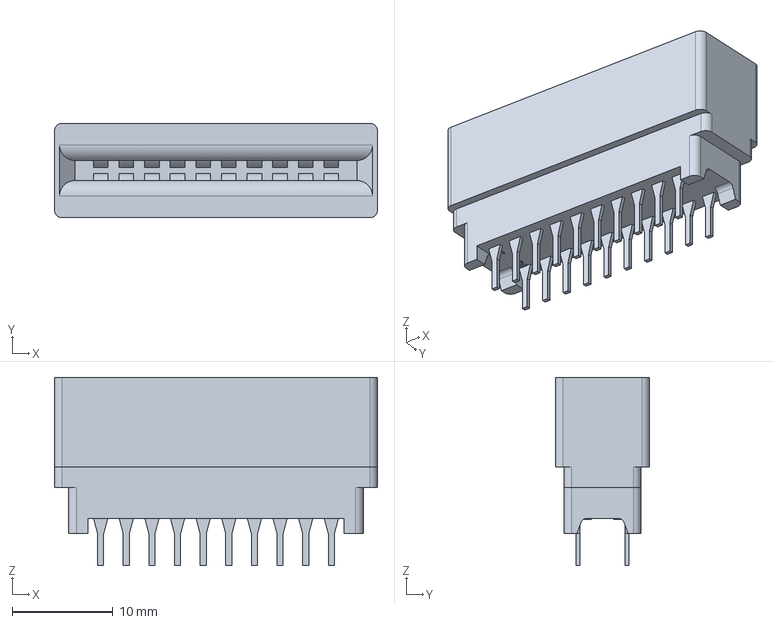
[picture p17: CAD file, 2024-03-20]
Models/5-5530843-0.step
32.0 x 9.35 x 18.7 mm

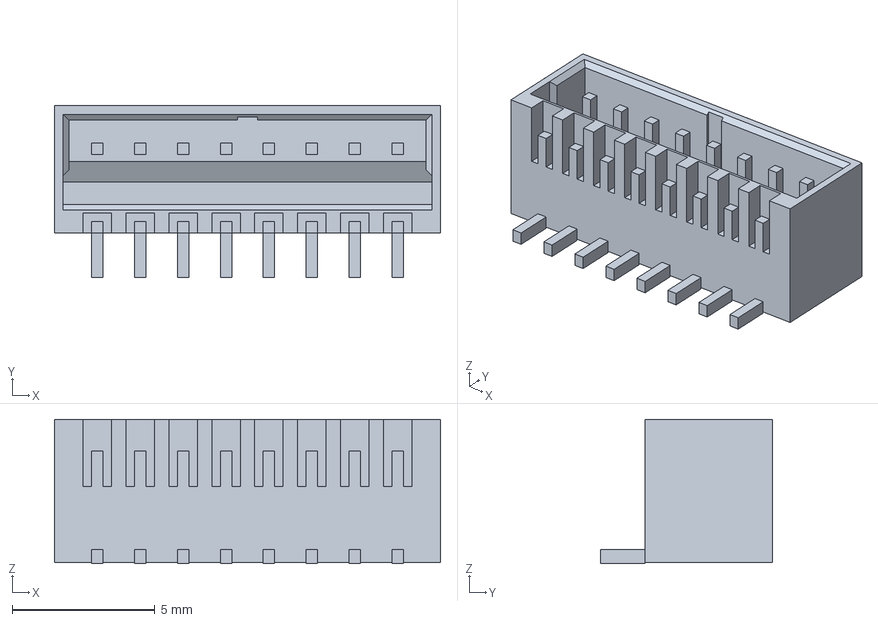
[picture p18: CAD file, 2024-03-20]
Models/5-1775443-8.stp
13.5 x 6.00 x 5.05 mm

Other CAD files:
Models/MX25L8006EM1I-12G.step
Models/SN75LVPE4410RNQR.stp
Models/LM3489QMM-NOPB.stp
Models/AON7403.step
Models/039300240.stp
Models/0455860005.stp
Models/10061913-103TLF--3DModel-STEP-56544.STEP
Models/469911008.stp
Models/470531000.stp
Models/LM3478MA-NOPB.stp
Models/TPS62177DQCR.stp
Models/TPS65987DDHRSHR.stp

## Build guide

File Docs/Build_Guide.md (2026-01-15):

The dock was designed from the beginning to be assembled at JLCPCB because of their low cost PCB assembly option. If you have not ordered from JLCPCB before, this guide will help you get started. There are two configurations you can build and some minor differences between them. The regular configuration is designed to be a complete replacement for the XG Station Pro main board and requires its proprietary power connector. It also supports USB charging and a 2-port USB hub. The lite version requires a standard ATX power supply and passes through the USB port to an external connection.

> Hint: You should visit https://jlcpcb.com/coupon-center and clip the coupons to save on your order.

## Board Guide

1. Download `GERBER-XG_Mobile_Dock[_Lite].zip`, `CPL-XG_Mobile_Dock[_Lite].csv`, and `BOM-XG_Mobile_Dock[_Lite].csv` from the [latest release on GitHub](https://github.com/osy/XG_Mobile_Station/releases). Choose the regular or lite variant depending on the build you want. Do not mix and match files.
2. Visit https://cart.jlcpcb.com/quote and upload `GERBER-XG_Mobile_Dock[_Lite].zip`
3. Fill the PCB options as follows (for each design)

    | Option                     | Standard                    | Lite                | Notes                                                           |
    |----------------------------|-----------------------------|---------------------|-----------------------------------------------------------------|
    | Base Material              | FR-4                        | FR-4                |                                                                 |
    | Layers                     | 6                           | 4                   |                                                                 |
    | Dimensions                 |                             |                     | Should be auto filled                                           |
    | PCB Qty                    | Any                         | Any                 |                                                                 |
    | Product Type               | Industrial/Consumer         | Industrial/Consumer |                                                                 |
    | Different Design           | 1                           | 1                   |                                                                 |
    | Delivery Format            | Single PCB                  | Single PCB          |                                                                 |
    | PCB Thickness              | 1.6                         | 1.6                 |                                                                 |
    | PCB Color                  | Any                         | Any                 | Green is cheapest                                               |
    | Silkscreen                 | White                       | White               |                                                                 |
    | Material Type              | **FR4-Standard TG 135-140** | **FR-4 TG155**      |                                                                 |
    | Surface Finish             | ENIG                        | **ENIG**            | HASL (with lead) can be used in low volume runs for cost saving |
    | Outer Copper Weight        | 1 oz                        | 1 oz                |                                                                 |
    | Inner Copper Weight        | 0.5 oz                      | 0.5 oz              |                                                                 |
    | Specify Layer Sequence     | No                          | No                  |                                                                 |
    | Specify Stackup            | **Yes**                     | **Yes**             |                                                                 |
    | Layer Stackup              | **JLC06161H-3313**          | **JLC04161H-7628**  |                                                                 |
    | Impedance Control          | No                          | No                  |                                                                 |
    | Via Covering               | Epoxy Filled & Capped       | Plugged             |                                                                 |
    | Via Plating Method         | Not Specified               | Not Specified       |                                                                 |
    | Min via hole size/diameter | 0.3mm/(0.4/0.45mm)          | 0.3mm/(0.4/0.45mm)  |                                                                 |
    | Board Outline Tolerance    | ±0.2mm(Regular)             | ±0.2mm(Regular)     |                                                                 |
    | Confirm Production file    | No                          | No                  |                                                                 |
    | Mark on PCB                | Remove Mark                 | Remove Mark         |                                                                 |
    | Electrical Test            | Fully Test                  | Fully Test          |                                                                 |
    | Gold Fingers               | No                          | No                  |                                                                 |
    | Castellated Holes          | No                          | No                  |                                                                 |
    | Press-Fit Hole             | No                          | No                  |                                                                 |
    | Edge Plating               | No                          | No                  |                                                                 |
    | Blind Slots                | No                          | No                  |                                                                 |
    | UL Marking                 | No                          | No                  |                                                                 |
    | Backdrill                  | No                          | No                  |                                                                 |

4. Check PCB Assembly and fill the following options

    | Option                  | Low Volume      | High Volume     | Notes                                  |
    |-------------------------|-----------------|-----------------|----------------------------------------|
    | PCBA Type               | Economic        | **Standard**    | Economic saves on per-component cost   |
    | Assembly Side           | Both Sides      | Both Sides      | Lite only needs top side               |
    | PCBA Qty                | >= 2            | >= 100          |                                        |
    | Tooling holes           | Added by JLCPCB | Added by JLCPCB |                                        |
    | Confirm Parts Placement | No              | No              |                                        |
    | Stencil Storage         | No              | No              |                                        |
    | Fixture Storage         | No              | No              |                                        |
    | Parts Selection         | By Customer     | By Customer     |                                        |
    | Advanced Options        | Do not change   | Do not change   |                                        |

5. Press Continue or Next
6. Accept the board preview and press Next
7. Click "Add BOM File" and select your `BOM-XG_Mobile_Dock[_Lite].csv`
8. Click "Add CPL File" and select your `CPL-XG_Mobile_Dock[_Lite].csv`
9. Press "Process BOM & CPL" to continue (ignore any error about missing data)
10. Select the parts to pick by following the [Parts Guide](#parts-guide) section below.
11. Press Next. If you chose to skip some parts you will get a confirmation pop-up where you can press "Do Not Place".
12. In the Component Placements screen, you can confirm the parts orientation. If there are any mis-rotated parts, click them and rotate it to the correct orientation. (e.g. the pin headers.) Press Next to continue.
13. Confirm the order details and for "Product Description" select "Reserch\Education\DIY\Entertainment -> DIY - HS Code 902300"
14. Press "Save to Cart".

## Parts Guide

### Ordering Parts
Some parts may not be currently available in JLCPCB. This will be indicated with a red "xxx shortfall" text under the select column or they may appear on the bottom under unmatched parts. For each unavailable, part you need to manually order the part before you can order the assembled boards. It will typically take a few days to two weeks for the parts to arrive at JLCPCB.

1. Locate the part number. If this is a shortfall part, click the row and then select "Part Info". Copy the "MFR.Part #". Also note the number required in the "Qty" column. This is the minimum number you need to buy. It may not always be possible to buy the exact number, so you may end up with extra parts. If this is an expensive part and you are cost conscious, consider buying some number of PCBs to get the number of missing parts to be an exact amount you can buy for all the missing parts. This will increase your total cost but decrease your per-unit cost.
2. Order the Order Parts page: https://jlcpcb.com/user-center/smtPrivateLibrary/orderParts
3. You have a choice between JLCPCB Parts or Global Sourcing Parts. JLCPCB Parts is recommended for cost and ease but not all parts will be available.
4. First, try to search in JLCPCB Parts: paste the part number and search. If there are multiple results, click the one with the exact match on the part number. You will either see a box to type in the quantity or "Unavailable".
5. If the part is available, type in the Qty from step 1 or the minimum shown above the box depending on which number is larger. Then click "Add to My Part Lib" and you can stop here and proceed with the next part. Once you have all the parts added, you can skip to part 8.
6. If the part is unavailable, you will need to visit [Global Sourcing Parts](https://jlcpcb.com/user-center/smtPrivateLibrary/orderParts). Search for the part number found in step 1.
7. You will be presented with a list of distributors. Some of these will be mismatches, check the number in bold above each table of distributors. This must be an exact match with your part number. Note the "Distributor Part #" may not match but that is okay. Each distributor has a minimum order quantity and a unit price breakdown. The easiest way to find the cheapest distributor is to enter your desired Qty from step 1 into each text box and look at the "Ext. Price" which is automatically calculated. Once you select a distributor, add the component to your cart. You can now repeat these steps for other missing parts.
8. Once you have all the missing parts added, visit the [Parts Cart](https://jlcpcb.com/user-center/smtPrivateLibrary/orderParts) and checkout your "JLCPCB Parts" and/or your "Global Sourcing Parts".

### Cost Reduction
If you are ordering a low quantity (2-5 units) of PCBA boards and don't mind doing a bit of manual soldering with a heat gun or reflow oven, here's some tips you can follow.

* Choose Economic PCBA with Top Side for the lowest cost
* You can manually solder the capacitors on the bottom side
* Some "Extended" components incur a $3/component fee. For certain parts, this fee exceeds the cost of the components and so it may be cheaper to purchase these parts yourself and manually solder them. Some of these "Extended" components are actually "Preferred" and do not incur this cost.
* Some parts are unavailable at JLCPCB and will require pre-ordering or purchasing from Global Sourcing Parts which usually come with a handling fee and a minimum order quantity. It may make sense to purchase these yourself and manually solder them. This makes sense especially for the more expensive ICs where you can buy it cheaper from AliExpress than Global Sourcing Parts.
* If you do not need the USB hub, you can exclude much of the components supporting those and significantly reduce costs.
* If you do not need PWM fan support, you can exclude all of the Extended and Global Sourcing components for that.

## Additional Parts
* [XG Mobile connector cable](https://www.a-accessories.com/asus-connection-cable-62505-79153.htm)
* (Standard build only) SPI flasher is needed to program the firmware for the TI PD charger. You can also use a RaspberryPi with [Flashrom](https://wiki.flashrom.org/RaspberryPi) for this purpose.
* ST-LINK v2 is needed to program the STM32 MCU. You can buy a cheap clone from AliExpress for under $10 but note that the pinout listing printed on the dongle may be incorrect.

## Building Firmware
Check the [readme](../README.md) for directions on flashing.

### MCU
To build the MCU, you need an GCC ARM toolchain. The easiest way is to install [Homebrew](https://formulae.brew.sh) and run `brew install --cask gcc-arm-embedded`. Then you can run `make` in the `XG_Mobile_Dock_MCU` directory to build the MCU firmware.

Alternatively, if you want to build and develop the firmware, the easiest way is to install Visual Studio Code and the [STM32 extension](https://marketplace.visualstudio.com/items?itemName=bmd.stm32-for-vscode). Then you can open the project directory and run build and debug commands from the IDE.

### TI PD Controller (standard build)
1. Download the [TPS65982 Configuration Tool](https://www.ti.com/tool/TPS6598X-CONFIG) and install it.
2. Project -> Load Project and select "xg_mobile_dock_charger.pjt". This will load the settings for this board.
3. Binary -> Save Binary and check "Full Binary Image"
4. Click "Change File" and save it as "XG_Mobile_Dock_Charger.bin".
5. Press Ok and Ok to save the firmware image.
6. Some flashers like Flashrom requires the image to be the same size as the flash device. You can run `dd if=/dev/zero of=XG_Mobile_Dock_Charger.bin bs=1 seek=1048575 count=1 conv=notrunc` to ensure this.

## Building XG Mobile Station
The standard build is designed to fit inside the XG Station Pro enclosure and replace the original board.

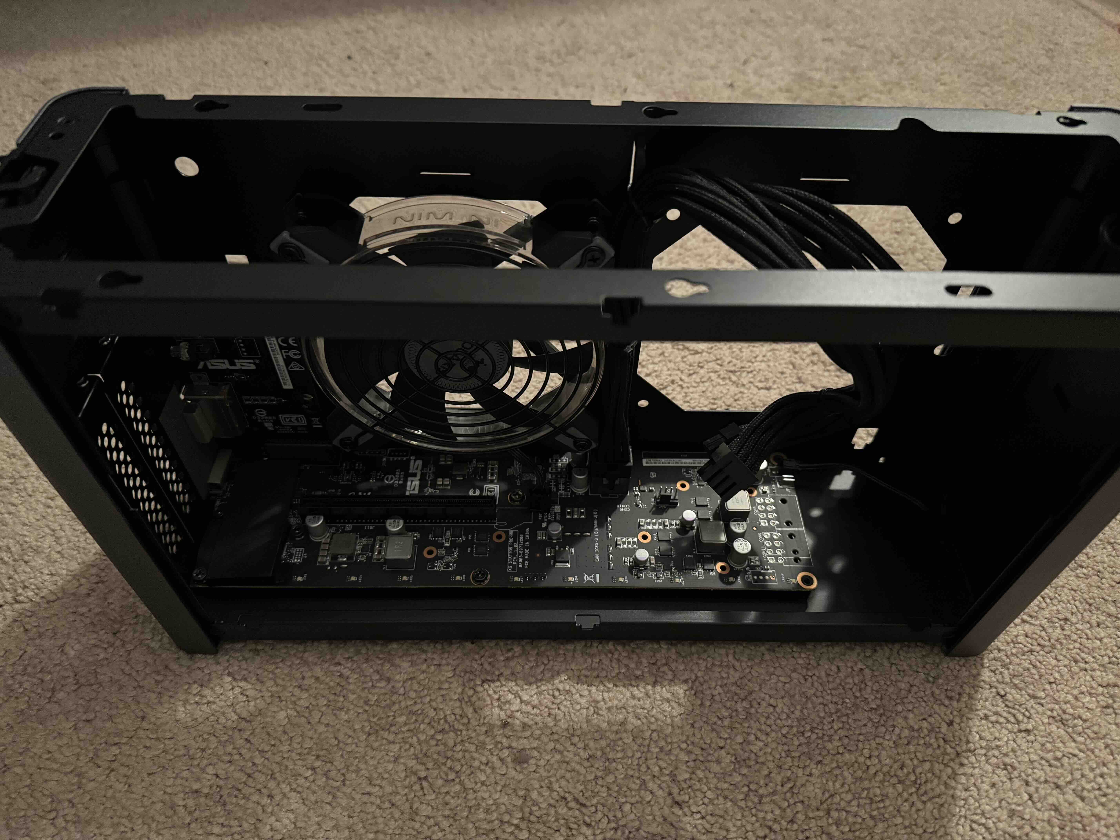
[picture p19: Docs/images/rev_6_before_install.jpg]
Before installation


1. Start by completely disassembling the XG Station Pro. Remove the top and side covers. Unscrew the right fan (the left fan does not block any other screws and does not have to be removed).
2. Remove the GPU if connected.
3. Unscrew the power adapter (3 screws) and lift the power adapter up and out. The connector may get caught on the fabric on the case so you might have to tilt it as you try to remove the board.
4. Remove both fan connectors and the LED connector.
5. Remove both PCIe power cables. Cut the zip ties which attaches the cable to the case.
5. Unscrew the main board (8 screws) and lift the board out of the case. The USB connector is inset to the case and may require tilting the board 45 degrees before lifting it out of the case.
6. Move the EMFI shielding from the original board's USB connectors and attach it to the new board.
7. Insert the new board into the case (tilting it so the USB connectors go into the inset first) and makes sure it sits flush on top of the screw holes.
8. Screw in the new board (6 screws, the 2 extra can be screwed in empty to prevent losing it).
9. Connect the PCIe power cables, the fan connectors, the LED cable, and the power adapter.
10. Connect the power adapter and screw it in (3 screws).
11. Connect the XG Mobile cable (3 connectors) and then carefully fold the cable 180 degrees so the XGM connector is pointing towards the PCIe slot. You should fold the cable towards you as to not impede the PCIe slot with the cable. Do not attempt to force bend the cable as it may be damaged. The XGM connector can be threaded through the PCIe slot closest to the outside edge.
12. Attach the ground pin to the board with the screw on the terminal.
13. Insert the GPU to the board and connect the PCIe power cable(s). You may need to cut the mounting bracket of the GPU in order to make space for the XGM cable.

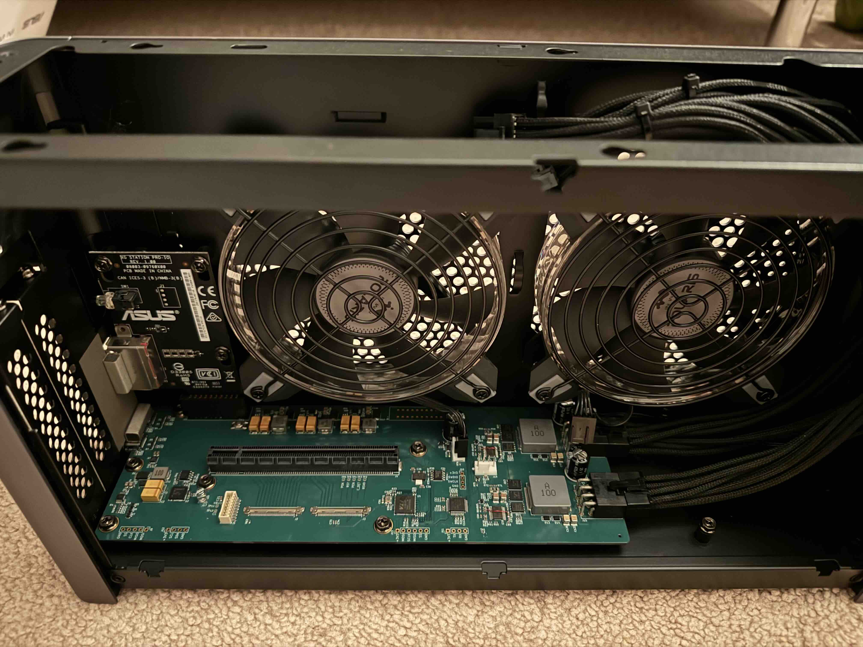
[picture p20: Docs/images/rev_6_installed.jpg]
After installation


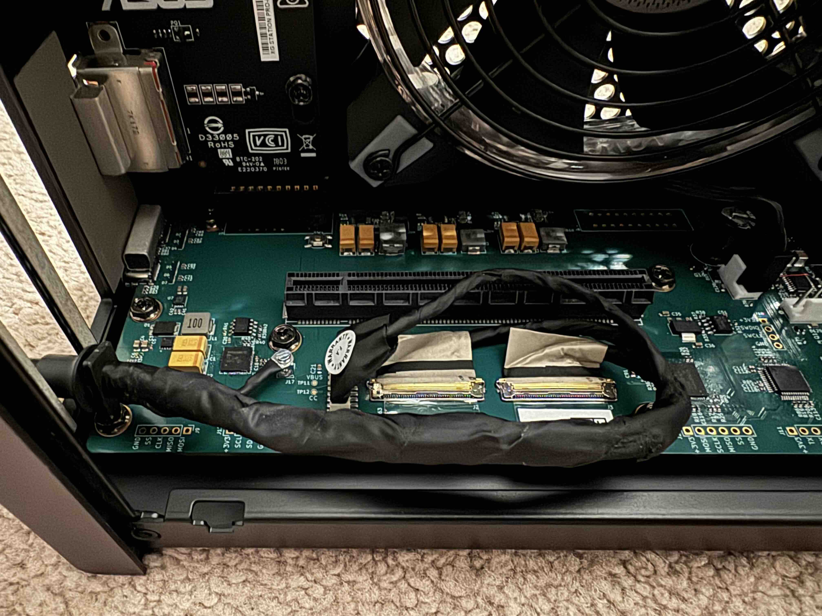
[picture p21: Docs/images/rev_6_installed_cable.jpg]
After installation with cable


Important Note: The DC-DC power supply is capable of supplying 180W to each PCIe 8-pin connector, 65W to the USB-C port, and 72W to the PCIe slot + the PWM fans. However, the AC-DC power supply input is rated for a maximum of 330W. This means that if you max out every possible power source, you may cause the system to shut down or in an unlikely worst case scenario start a fire. On our device, we found that the power supply is capable of 360W (measured from the wall) for long durations without overheating however this may vary with each unit. It is recommended that you limit the GPU power consumption to a maximum of 285W or lower (undervolting it if needed) to be absolutely safe.

[Check out the power guide for custom power supply replacements.](Power.md)

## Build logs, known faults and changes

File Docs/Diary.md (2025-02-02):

This project was the culmination of many months of work reverse engineering hardware, reverse engineering software, designing hardware, designing software, and lots of debugging on all parts of the stack. By documenting the journey and all the mistakes made and dead ends, hopefully it can save someone else some time in the future.

## Origins
The inception of this project came from the discovery of the [ROG Flow X13 schematics](https://www.badcaps.net/forum/troubleshooting-hardware-devices-and-electronics-theory/troubleshooting-laptops-tablets-and-mobile-devices/schematic-requests-only/1039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) which contains the pinout listing of the XG Mobile connector and the [ASUS parts store](https://www.a-accessories.com/asus-connection-cable-62505-79153.htm) which sells the XG Mobile cable individually. We can build a custom board to connect the XGM port to a standard PCIe slot or an OCuLink connector.

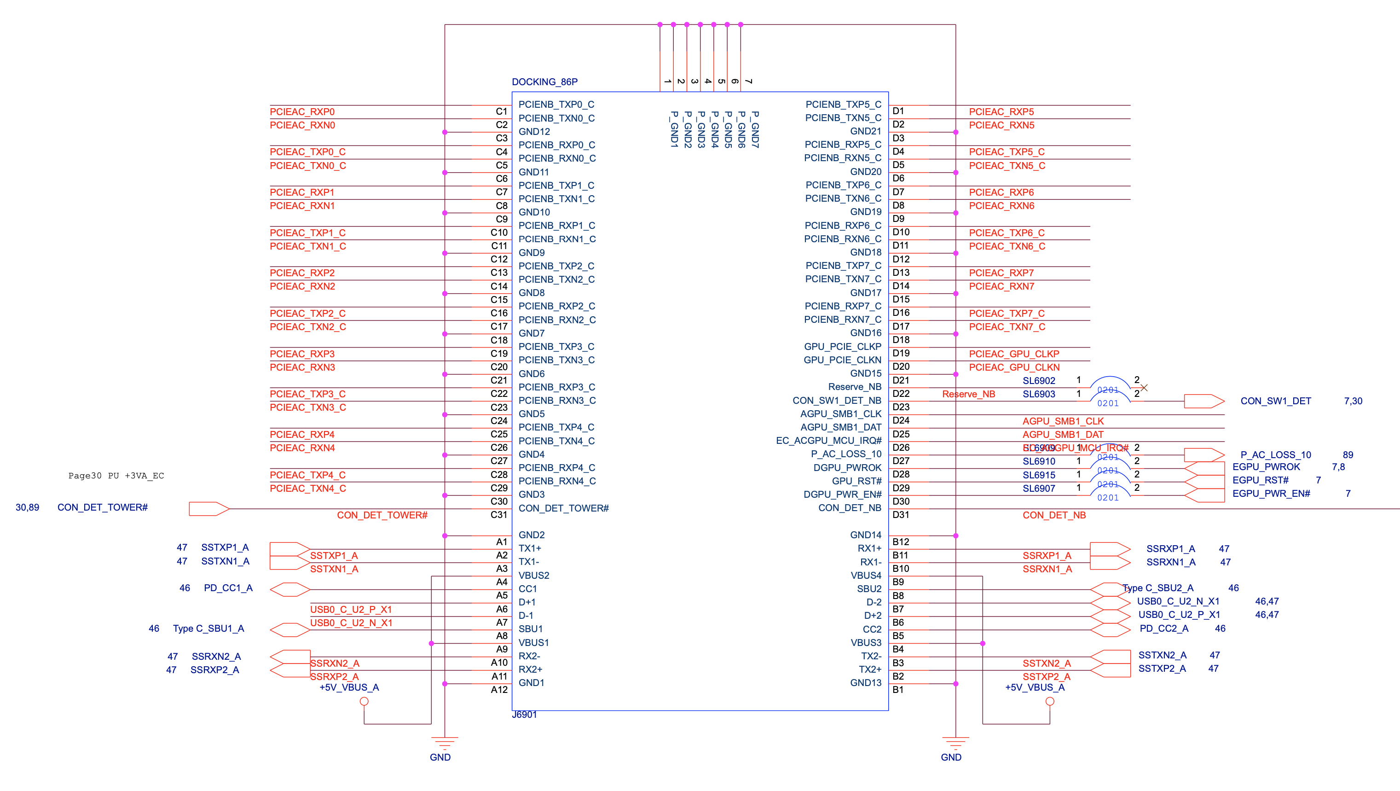
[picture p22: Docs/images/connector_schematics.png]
Connector schematics


However, there is a problem: the other end of the XGM cable are three proprietary board connectors (an 8-pin and two 40-pin). 

XGM cable other end (https://images.anandtech.com/galleries/7883/Connector%20(3).jpg)

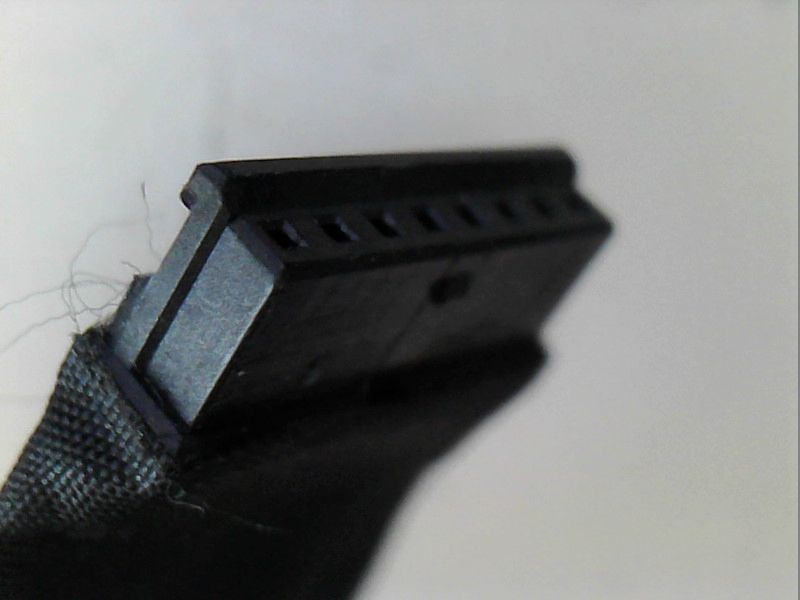
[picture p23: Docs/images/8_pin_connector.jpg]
8-pin connector


The 8-pin was easy enough to find. It was a rectangular pin connector with a specific pitch width and pin size. After some searching on Digikey and Mouser as well as popular connector brands' sites, we found it was a match for [5-1775443-8](https://www.te.com/en/product-5-1775443-8.html).

Finding the part number for the 40-pin took a bit of internet sleuthing. The first lead with from the [parts site listing for the 40-pin connector](https://www.a-accessories.com/asus-attach-system-40-pins-87588-67468.htm) which had the part number "12017-00181600". Searching for that on Google led to schematics for another ASUS product "ASUS X505BP REV2.0.pdf". Inside that schematics, we found the reference to that part number for something called "WTOB_CON_40P" and it carried eDP signals. That gave us the idea that this connector is repurposed from a high-speed display panel connector and we started searching Aliexpress for replacement display connectors with 40-pins. This led us to the [I-PEX CABLINE-VS](https://www.i-pex.com/product/cabline-vs) which precisely matches the photo.

Once it was confirmed that all the parts are standard and are easily available for purchase, the project to build a eGPU dock became tenable.

### Pin mapping
Before we can design the dock, we had to map the pins from the 86-pin XGM connector (which we have the schematics for) to the 2x 40-pin I-PEX connectors (which would mate with our custom board). This would require purchasing the cable and manually mapping the pins with a multimeter's connectivity mode.

After carefully taking the cable housing apart, we were met with a PCB which routed the 86-pin XGM connector to the cable's wires.

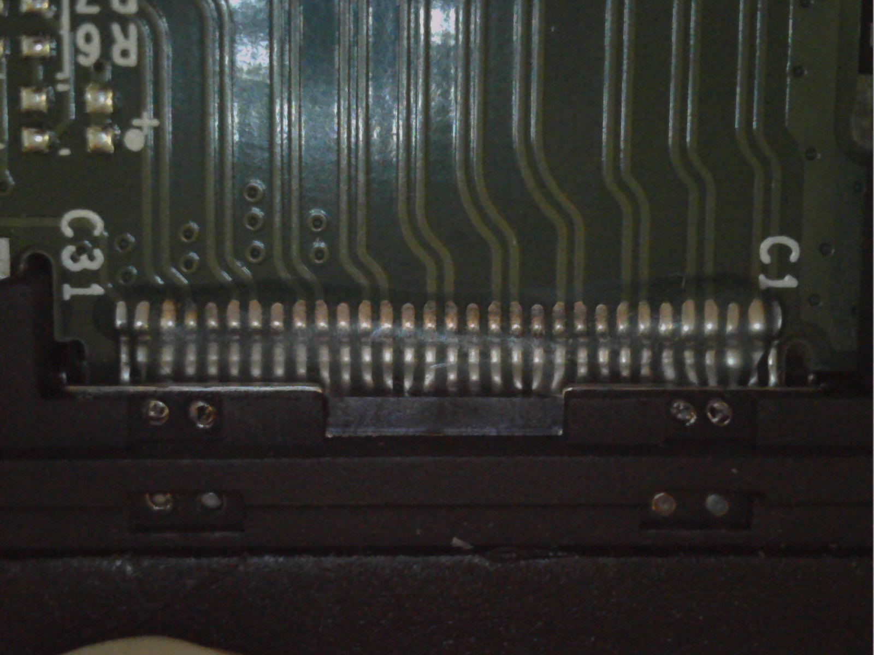
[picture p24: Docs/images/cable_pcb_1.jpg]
Cable housing 1

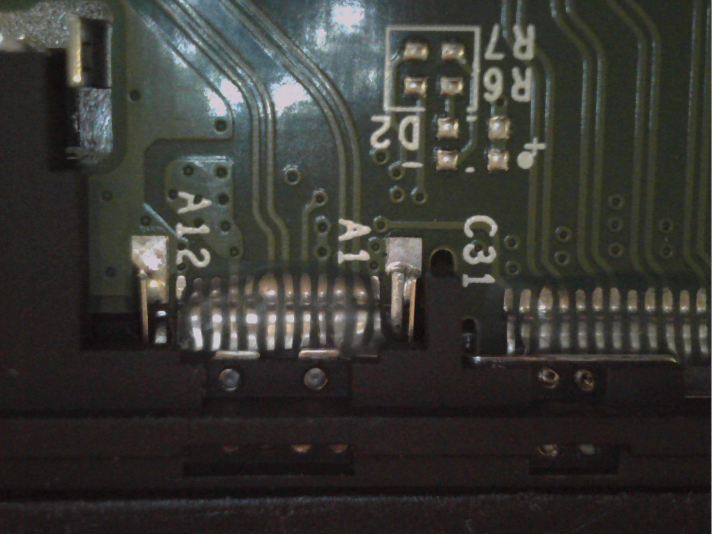
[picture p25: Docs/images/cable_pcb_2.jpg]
Cable housing 2

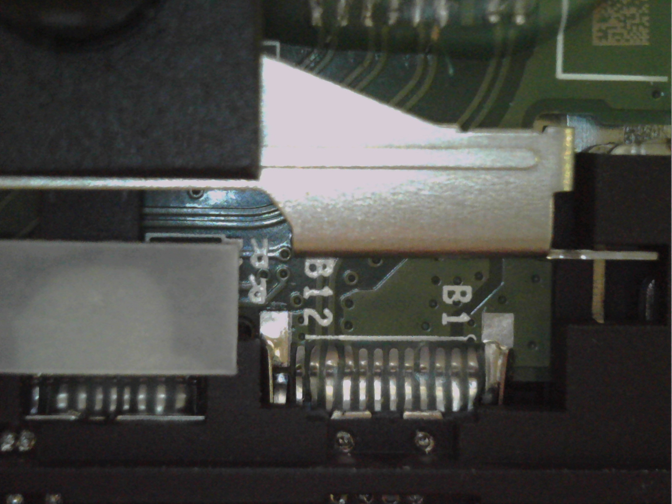
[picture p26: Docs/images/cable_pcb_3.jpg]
Cable housing 3

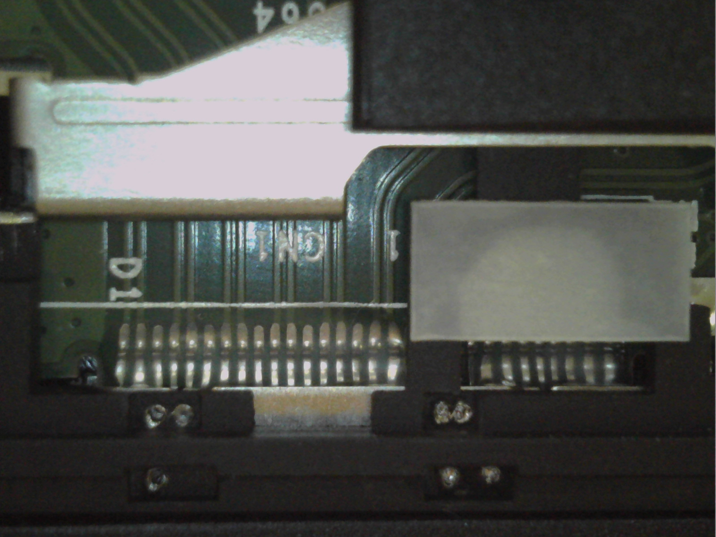
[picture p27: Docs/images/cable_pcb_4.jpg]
Cable housing 4

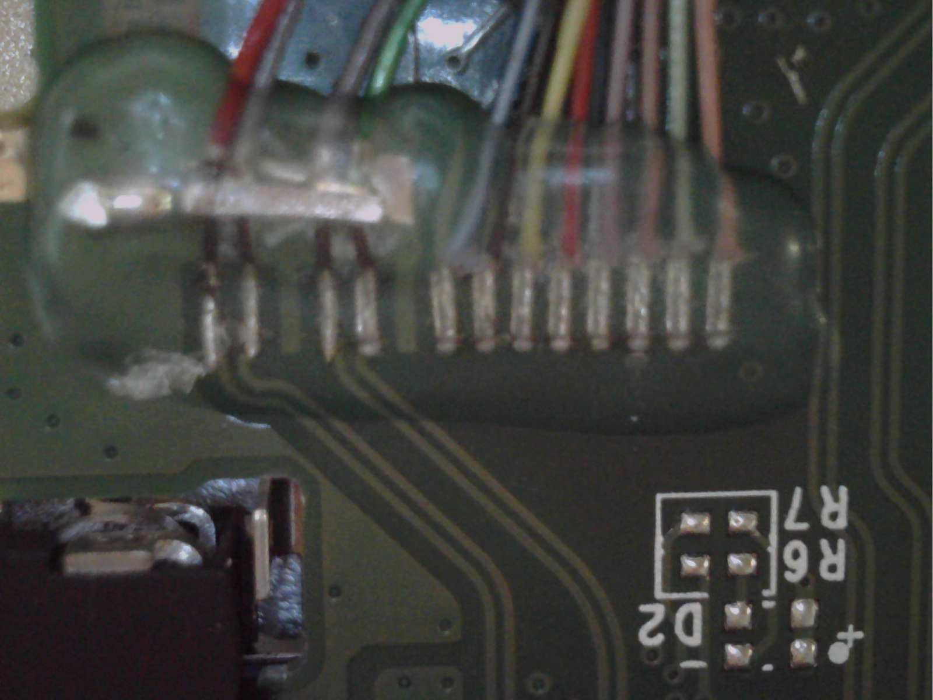
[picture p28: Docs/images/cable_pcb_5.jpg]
Cable housing 5

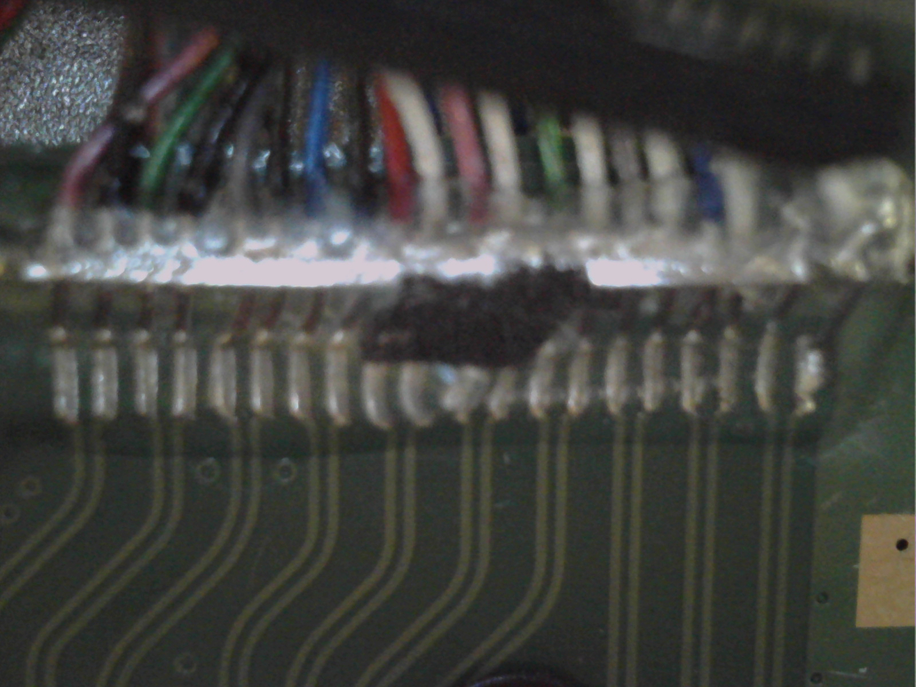
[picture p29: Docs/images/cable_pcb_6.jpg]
Cable housing 6

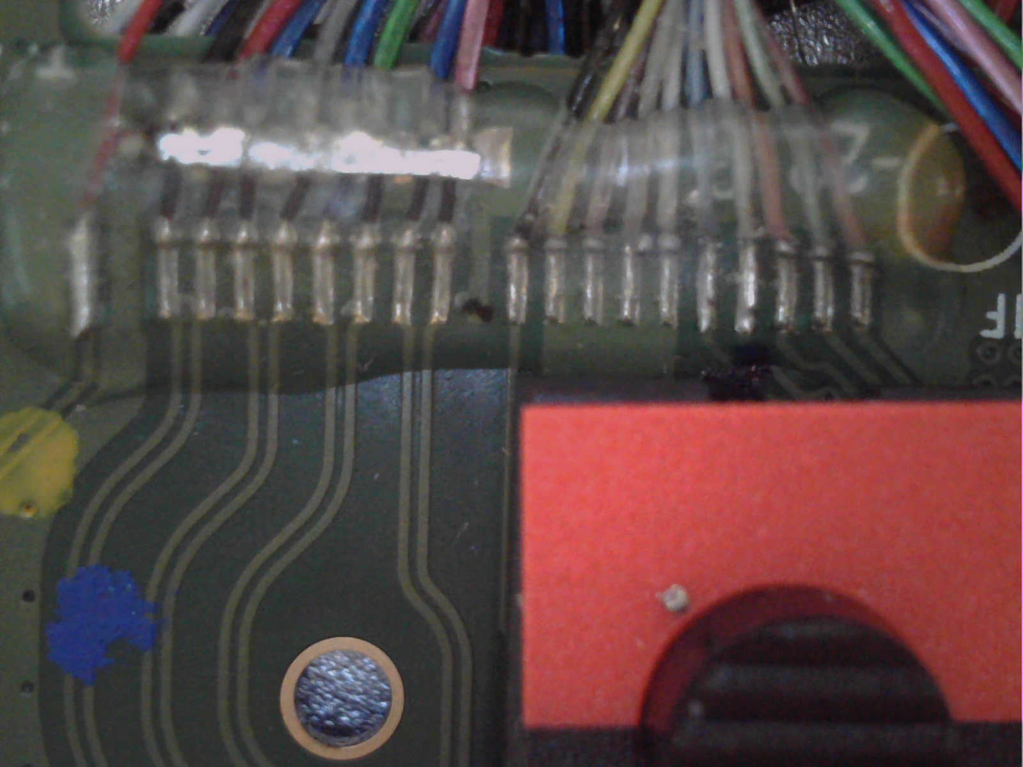
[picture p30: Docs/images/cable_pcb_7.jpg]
Cable housing 7

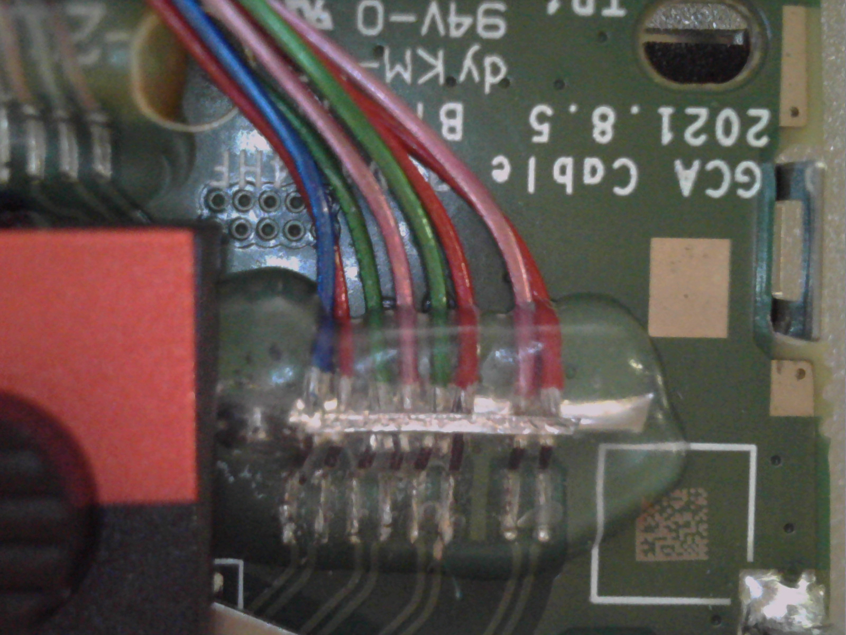
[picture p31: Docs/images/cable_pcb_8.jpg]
Cable housing 8


The glue which fortified the fragile wire connections had to be removed with some heat and then each pin can be traced to the wire and from the wire to the 40-pin connector. The pins on the 40-pin connector was extremely tiny, but a sewing needle taped to the probe of the multi-meter did the trick. The result was documented [here](Connector.md).

## XG Station Pro
In 2018, ASUS released the [XG Station Pro](https://www.asus.com/motherboards-components/external-graphics-docks/all-series/xg-station-pro/), a Thunderbolt 3 eGPU enclosure with a beautiful In Win designed case in a slim profile. 

XG Station Pro (https://www.asus.com/media/global/gallery/b8ohmdrISwndXZJZ_setting_xxx_0_90_end_800.png)

For no reason other than because we want to repurpose this obsolete piece of hardware, we decided to design a replacement PCB that can interface with the XGM port. The idea is that we can take advantage of the included 330W power supply to power our board and also pass-through power to the original PCB as well. The original PCB will plug in at a right angle and drive the FETs which will power the PCIe graphics card as well as the fans and RGB lights.

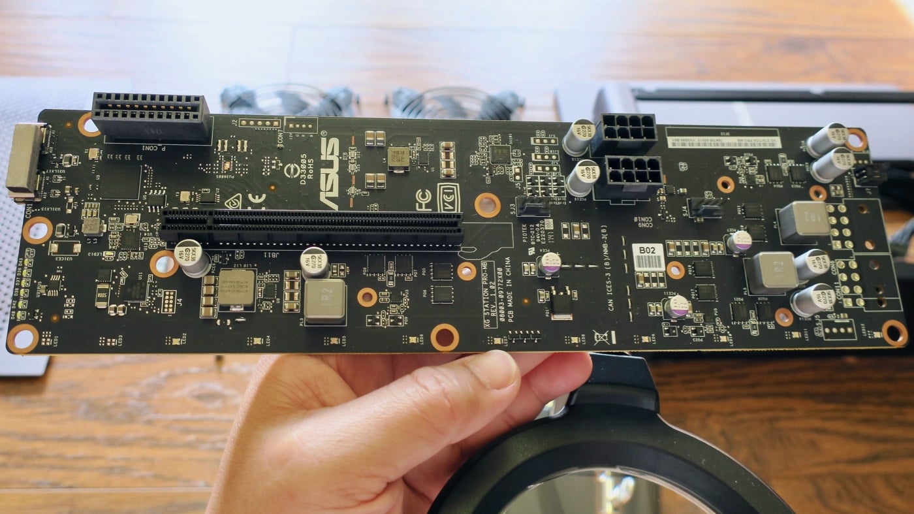
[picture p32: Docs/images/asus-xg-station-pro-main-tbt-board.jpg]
XG Station PCB

(Photo credits: [itsage](https://egpu.io/asus-xg-station-pro-review-cool-calm-collected/#comment-2453))

To get the positions of the screw holes correct, we used a digital caliper to get a rough measurement of the relative position of all the holes. Next, with trial and error, we printed out the PCB layout, compared the screw holes with a pencil outline, and made fine adjustments until all the holes lined up perfectly.

## Board Design
From the beginning, the goal is to make the board as cost effective as possible. We designed the board with intention of fabbing it at [JLCPCB](https://jlcpcb.com/help/article/98-PCB-Assembly-FAQs) because of their insanely low assembly costs. However, to take full advantage of the low costs, you are encouraged to use "Basic Components" from their parts library. These are parts which has already been loaded into their picker machines. Otherwise, you are charged an additional $3/part. For most resistors and capacitors, this is simple enough. For other components such as transistors, diodes, and the MCU, we try to find parts which are in their list of basic components. If no basic component are available, we looked for the cheapest part in their parts library.

### Rev. 1
We planned to design three circuits: the PCIe port with retimers, a USB 3.1 Gen 2 hub, and a 100W USB-PD charger. The reason for the hub and charger is because the XGM port takes away the only USB-C port on the ROG Ally. We chose the SN75LVPE4410 PCIe retimer because it was used on the ROG Flow X13 and therefore is "tested". For the USB hub, we chose the VL822-QFN76 because it is cheap and is in stock at JLCPCB. The USB-PD charger uses the TPS65987 because no other port controller on the market supports charger mode with data-role-swap (which allows the power-source to act as a data-sink). Since the retimer and USB-PD controller were TI chips, there is extensive amount of resources including sample designs and layout guidelines. That made designing those parts relatively easy. The VIA USB hub had no publicly available resources aside from a leaked early datasheet so we learned how to design with it by looking at [other projects online](https://oshwhub.com/lovetombseries/LoveTomb2).

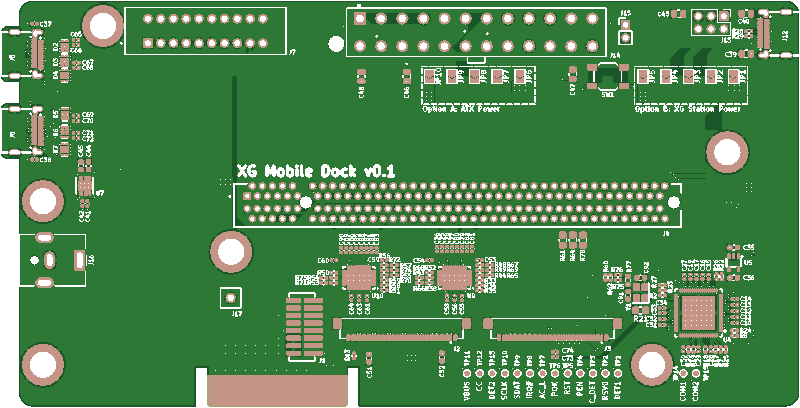
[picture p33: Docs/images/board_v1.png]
Board rev 1
 PCI leech board

The power delivery story for this board is rather complicated (for such a simple design). We needed to pass through 20V from the top connector to the bottom to power the external board, 12V and 3.3V for the PCIe connector, and 5V for the USB. In the first revision, to keep things simple, we decided to externally power everything. An ATX 20-pin connector was used for this purpose. We also tested an option that did not require an ATX power supply by attaching a "PCI leech" board for stealing 12V and 3.3V from the external board's PCIe connector and 5V from a USB port.

Unfortunately, this first revision was broken in many ways. First, the ATX 20-pin was wired up mirrored due to incorrect data in the footprint we downloaded. The retimer was wired up to the wrong pair (RX instead of TX) because of confusing naming in the schematics. We also didn't fully understand the purpose of the sideband signals in the XGM connector and so to be safe, we had pull-ups and pull-downs (unpopulated) for many signals. Finally, the PCI leech idea ended up not working so we were only able to use the ATX power supply (after manually wiring each pin mirrored).

When attached to the ROG Ally, it kept throwing "No Power" errors. After some reverse engineering [of the software](Software.md), we found that it needed to communicate with a USB HID device from the dock. Since that was unavailable, we had to trick the software into thinking there was power. However, that was still not enough as the "lock" status coming from one of the pins of the XGM connector was not being updated on the ROG Ally. We reverse engineered the [ACPI table](ACPI_Annotated.asl) to figure out how the "lock" status was being sent to the Armory Crate software and found there was a bug in the ACPI code which does not recognize when both the "connected" and "locked" pins are both asserted at the same time (in the real XG Mobile, it is always "connected" first, and then "locked" when the user engages the lock switch). This means that we cannot use simple pull-ups and pull-downs for the sideband signals and instead must implement a simple MCU which can control the sideband signals.

### Rev. 2-3
In rev 2, we removed the external power sources and implemented some proper buck converters for 12V, 5V, and 3.3V. We also implemented the USB PD charger circuit and to simplify the BOM (and picker costs), we used the same basic buck design for all four power circuits. We removed the PCIe retimers because they were expensive and because the ROG Ally did not include them on its motherboard and so having only retimers on one end is pointless (yes, the ROG Flow does use them and so having retimers would be useful for them). Finally, we added the STM32F030C8T6 MCU, which exists as a basic part on JLCPCB. The MCU required some pin headers for SWD programming and UART logging and the USB PD needs a SPI flash which also needs to be programmed. Slowly, this simple board got more complex...

There was still some big mistakes in this board. First of all, a mistake in the schematic drawing that was uncaught until now meant that the USB hub had its 1.2V and 3.3V shorted together (not good). Somehow, we *still* managed to mess up the PCIe TX and RX lanes by swapping them. What we thought was a clever shortcut in the resistor network (more on that later) to switch charging voltage for the USB PD charger did not work as expected. Finally, a last minute decision to silence DRC errors on the un-populated PCIe retimer circuit meant that we accidentally wired a 3.3V trace that was too thin to carry the current load. This thin trace just happened to be routed under the VBUS net and when an inrush current on 3.3V occurred during MCU programming, that trace burned up and shorted 12V to VBUS and in an instant destroyed an attached USB hub, a flash drive, and a keyboard. Luckily, the ROG Ally was fine because its USB circuit was properly designed to handle such a situation.

However, the bright side was that the MCU was working and the ROG Ally can show the XG Mobile pop-up after the right sideband signals was sent. A lot of trial and error led to [discovering the handshake sequence](Connector.md#connection-handshake). The USB hub was working as well. The PCIe still did not work because of the swapped lanes.

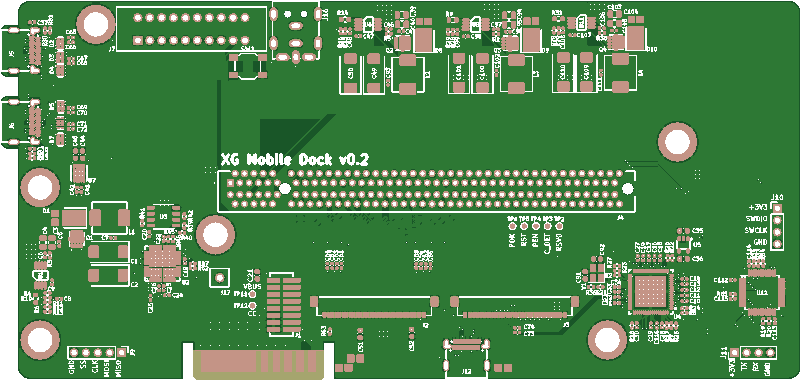
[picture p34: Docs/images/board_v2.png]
Board rev 2


Rev 3 fixed the big mistakes and also removed the test pads that might have caused signal integrity issues. Additional sideband signals to control the external XG Station Pro board was wired to the MCU as well. Another mistake was made in wiring up the MOSFETs which replaced the resistor network for controlling the buck converter in rev 2 and so the USB PD charger could not be tested.

A side-note on the USB charger: To control the output voltage of the buck, a voltage divider is placed in a feedback network that is fed into the buck controller. In order to get variable voltages as required by the USB PD specifications, we program the TI PD controller to output a different GPIO signal for each selected PDO profile. Each GPIO controls a MOSFET which is connected to a resistor and affects the voltage divider value on it is turned on. In order to save costs, we wanted to only use resistor values that are in JLCPCB's basic component library. So, a Python script [was written](../resistor_finder.py) to brute force all possible sets of resistor values and return a set of resistors that had the least error on the output voltage. Miraculously, this worked.

Once the software workarounds was applied, the ROG Ally finally was able to recognize the PCIe graphics card! The RTX 3060 Ti was recognized but it threw an error 43 and no display was detected. Fortunately, this is a well known issue in eGPU world and the [workaround](https://egpu.io/nvidia-error43-fixer) is easy to use. With the workaround, we were able to get the display to work. But, fixing device detection on reboot took [another week of effort](MCU.md#embedded-controller).

### Rev. 4
This revision fixed the MOSFET issue and also switched the PCIe connector from through-hole to SMD which is both better for signal integrity and also makes the assembly cost much lower. An unexpected side-effect of the better signal integrity is that, without any additional changes, we are able to get PCIe 4.0 speeds!

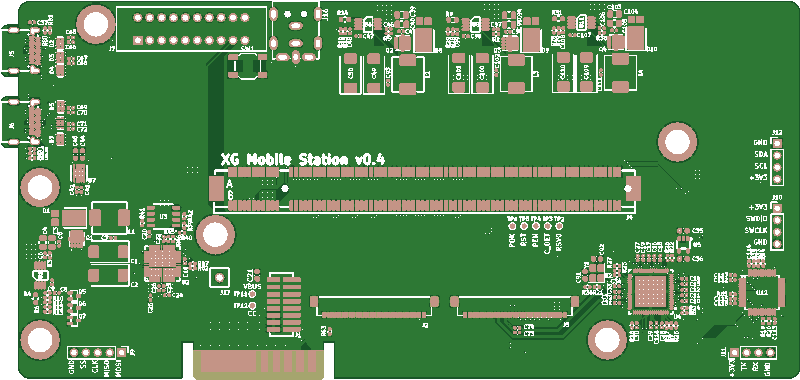
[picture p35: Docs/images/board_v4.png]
Board rev 4


Through extensive testing, we found an issue with the USB PD circuit. If the external power is disconnected while the XGM connector is engaged, the +3V3 rail loses power and therefore the SPI flash loses power. The TI PD chip resets and draws power from the Ally. Since it is not able to read the firmware settings from SPI, it falls back to the default which is to negotiate a power sink role and now the Ally is powering the board. This is undesirable because it could drain the battery. The recommended layout from TI is that the SPI flash is powered by LDO_3V3 output from the TI chip and so we changed the design follow this recommendation.

Another issue discovered was that devices plugged into the USB hub would be disconnected after a few seconds and proceed to go into a detection and disconnect loop. When debugging this issue we found that the cause for this disconnect loop was the +1V0 rail was falling and then coming back up. This was an issue with the LDO and upon close reading of the data sheet we learned that it was overheating and going through thermal shutdown. Once the device cooled down, it reset, then overheats again, and so on. To confirm that overheating was the issue, we used some compressed air to cool the LDO during operation and found the disconnect issue no longer occurs spontaneously. However, when plugging in two devices, disconnection shows up again. We suspect that the LDO was also going into overcurrent protection as well. Since there was no public datasheet available for the VIA USB hub IC, we looked at schematics of other designs online and used a 300mA LDO because that is what others have used. However, upon measuring the current with an ammeter, we found that it can hit above 500mA at peaks. The final solution is to select a 1A LDO to handle the maximum current and we also chose a physically larger component which should have better heat dissipation. Finally, we increased the copper contact area under the LDO as well.

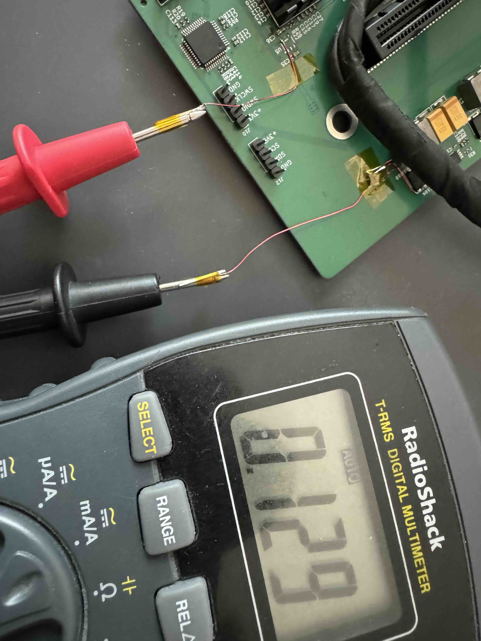
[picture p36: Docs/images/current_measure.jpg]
Board current measurement


### Rev. 5
In addition to using a beefier LDO, we also connected a SPI flash to the VIA USB hub. Although the SPI flash was listed as optional in the datasheet, we found that USB 3.0 often caused errors in Windows and we hypothesized that the issue was due to outdated microcode that could be updated by a firmware stored in the SPI flash. We tested this by building a separate board with just the USB hub and confirmed this was indeed the fix.

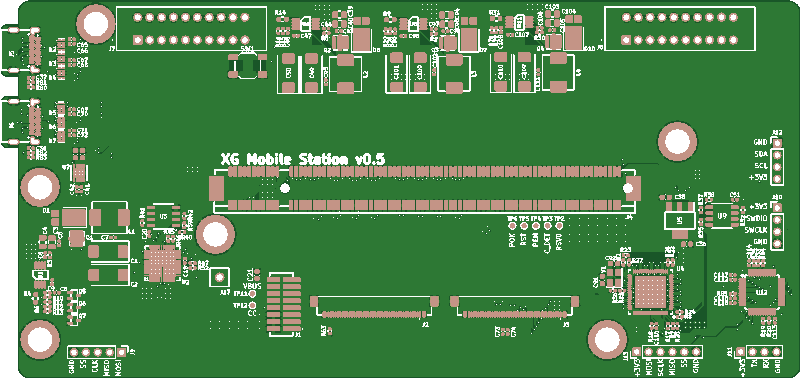
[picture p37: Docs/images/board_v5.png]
Board rev 5


We also took the opportunity to reorganize the board layout. First, we moved the decoupling capacitors for the two USB ICs to the bottom layer. Previously, we avoided any components on the bottom layer for cost reasons but after observing the current consumption of the USB hub, we decided it would be safer to properly follow design recommendations and place the caps directly underneath the IC for better handling of sudden current spikes. This also means we have more space on top to follow other best practice guidelines such as putting Rbias and the crystal closer to the pads. Ultimately, the number of components on the bottom is quite small and can be manually soldered in small runs.

Since we no longer need to stuff all these components close to each other, we also were able to increase the minimum drill size from 0.15mm to 0.3mm. This introduces significant cost savings in manufacturing.

Finally, we moved the power passthrough from the bottom edge to a second connector on the top. Originally, we wanted to plug the original board directly into our board in a 90 degree orientation. This was awkward to manage and did not work with larger GPUs. Instead, a better way is to introduce a second 20-pin connector along with a custom passthrough cable.

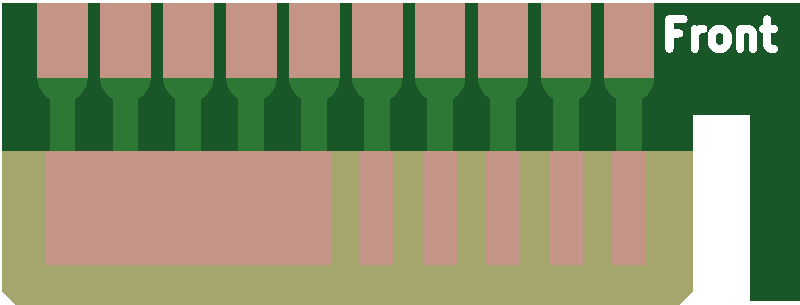
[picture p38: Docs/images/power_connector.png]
Power connector


### Lite
By popular demand, we also introduced a "lite" variant of the board which is cost-optimized to work with the minimal number of components. We removed the USB ICs and associated power controllers and added an ATX-24 connector.

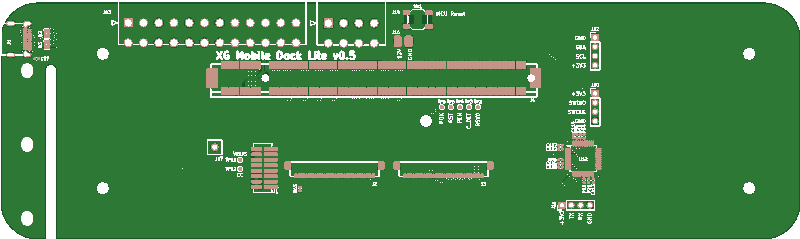
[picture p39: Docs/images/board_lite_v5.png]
Board lite rev 5


We chose to match the form factor to the ADT-UT3G in order to be compatible with third party case designs.

### Rev. 6
Originally, we didn't design a 300W DC-DC power supply because of the increased complexity and opted to build a passthrough cable for the 20V connector in order to use the power circuit from the original board. While this had worked, we were not happy with the thermal performance because we had to remove the case fans to make room for the board. To avoid the need to test multiple iterations of a high wattage power supply, we took a shortcut once again and stole a [TI reference design](https://www.ti.com/tool/PMP10852). By using the same BOM and layout we avoided the need to do extensive testing on the design.

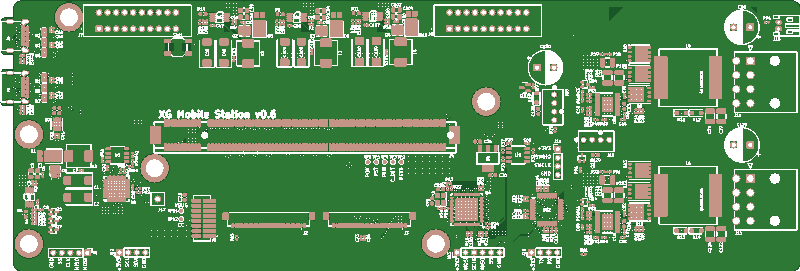
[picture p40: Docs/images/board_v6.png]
Board rev 6


In addition to the power supply, we also added fan connectors and wrote a PWM driver in the microcontroller and support for the case LED. This means the board is now a complete replacement for the original and we no longer need the original board.

After testing the boards, there was some minor issues including hiccup mode in the over-current protection of the power supply. The controller disables the FETs until a timer expires during an over-current condition but because the GPU is using two supplies in parallel, it is acceptable for short periods of over-current on one supply (it should drop the voltage and the other supply will then ramp up).

## Final Build (rev. 4)
Originally, we wanted to fit a 2 slot GPU into the case, which meant we could have daisy chained the PCIe power PCB on the side. However, after getting a NVIDIA RTX 4070 Ti SUPER (a 2.7 slot card), we had to adapt the power connector. The solution was to make a [riser cable](../Power_Riser) for the power connector which allowed us to mount (tape) the power PCB to the top of the enclosure.

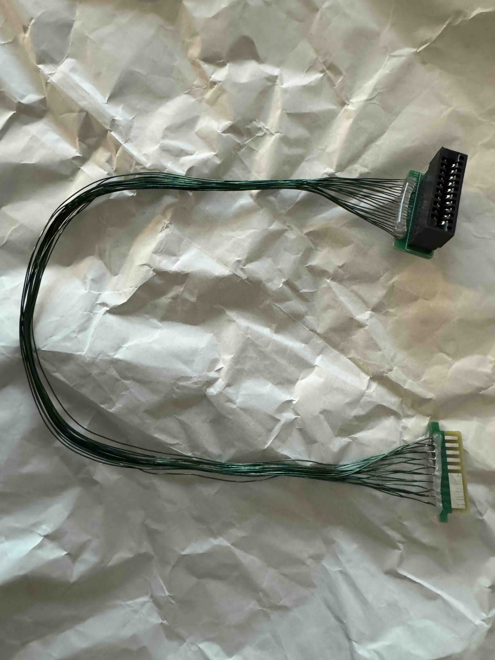
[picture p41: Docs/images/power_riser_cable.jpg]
Power riser cable


Next, we tested the complete setup for stability before stuffing it into the enclosure.

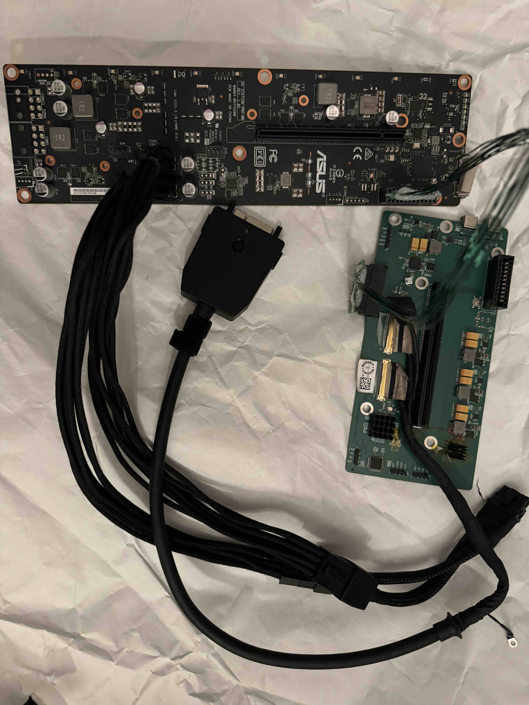
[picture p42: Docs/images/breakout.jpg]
Breakout setup


On the top is the original XG Station Pro PCB which we use to drive the two 8-pin PCIe power connectors that goes into a single 12-pin adapter for the GPU. On the right is the XG Mobile Station rev. 4 board with some modded fixes for the USB overheating issue (we re-wired a larger LDO and stuck on a heat sink for both the LDO and the USB IC). These two are connected by the power riser cable so the 20V power supply can be passed from the custom board to the original board.

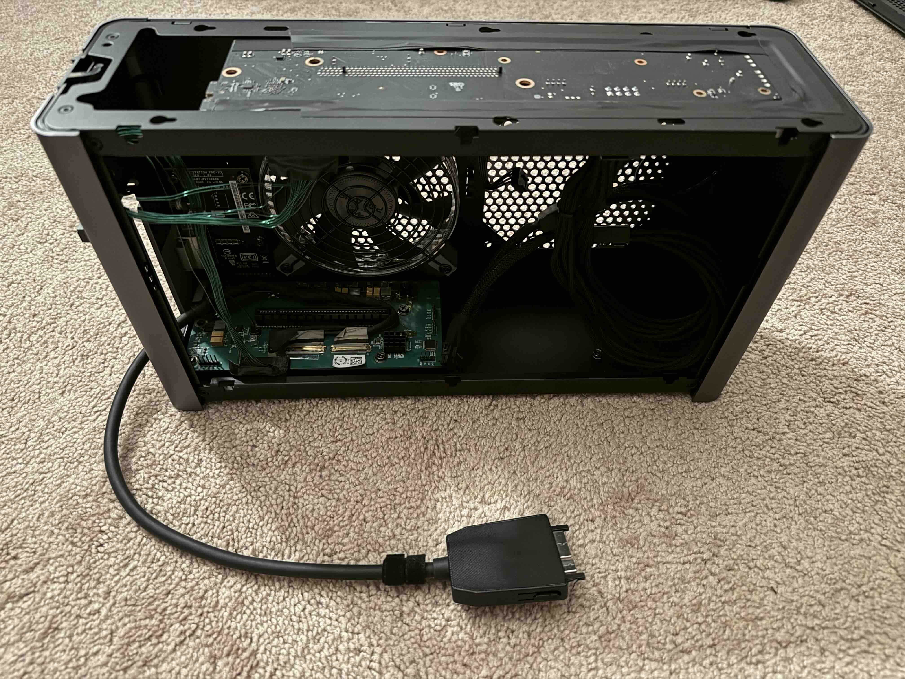
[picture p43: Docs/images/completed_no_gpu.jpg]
Completed (no GPU)


After doing some stability testing with FurMark and making sure we didn't start any fires with the custom riser cable that can carry 16.5A of current, we fitted the custom board to where the original board used to sit and then with electrical tape, we moved the original board to the top of the case and connected the two with the riser cable.

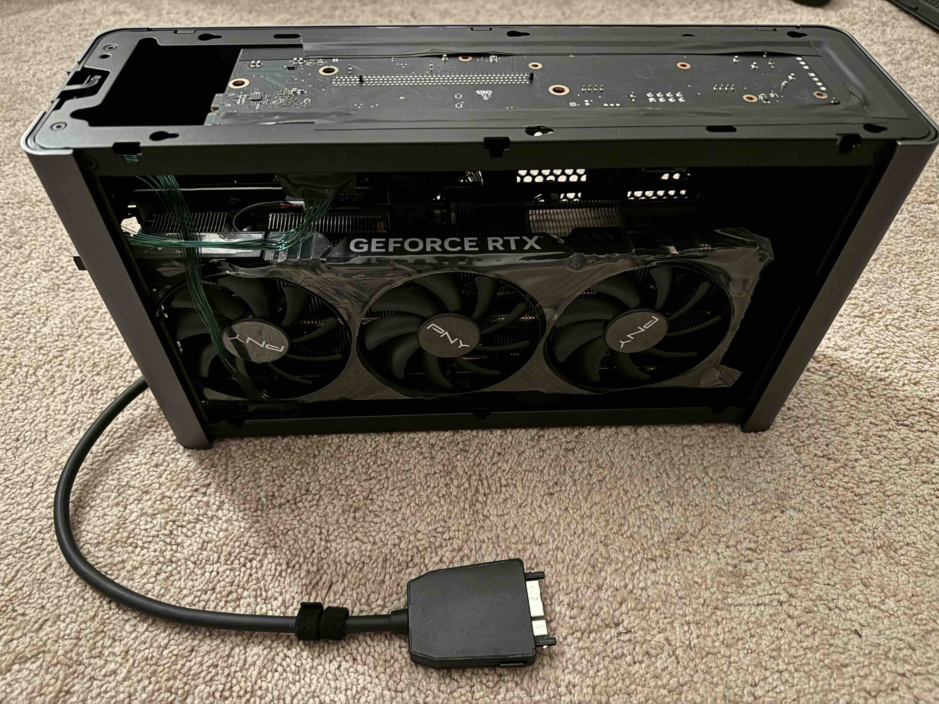
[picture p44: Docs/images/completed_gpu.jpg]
Completed (with GPU)


The GPU sits snugly inside the enclosure. Due to a design limitation of the XG Station Pro case, it does not fit a 2.7 slot bracket even though it fits a 2.7 slot card. That means the mounting bracket had to be removed which unfortunately means that the card is sitting loose on the PCIe slot and can cause damage if it was ever tipped over.

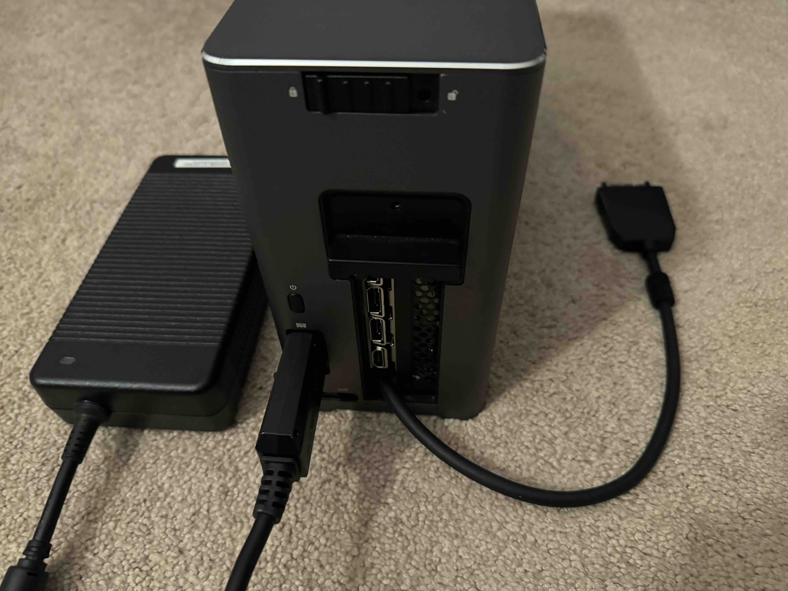
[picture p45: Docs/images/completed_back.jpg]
Completed (back)

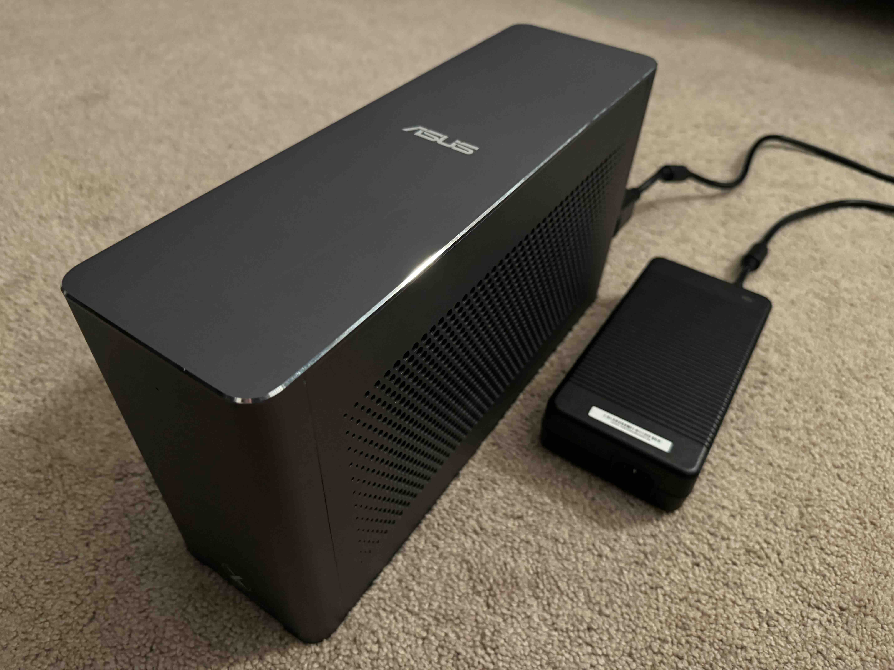
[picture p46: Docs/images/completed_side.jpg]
Completed (side)

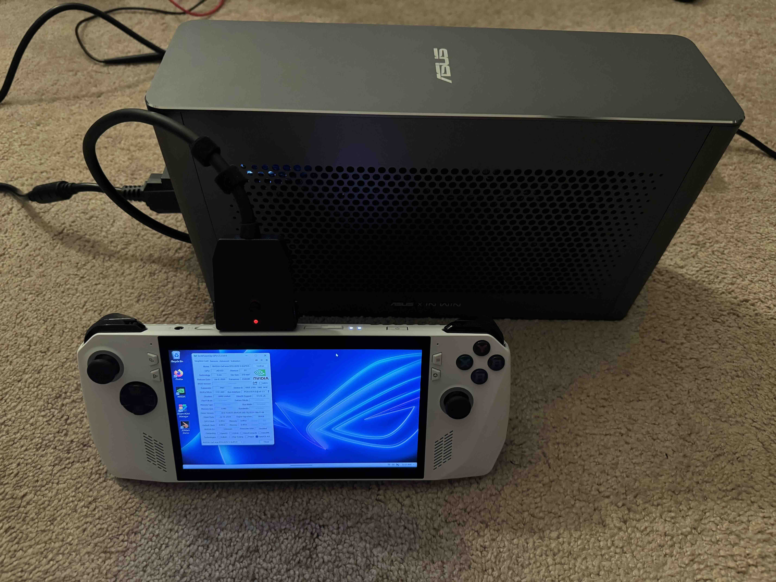
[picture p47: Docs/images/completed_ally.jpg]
Completed (Ally)


The last part of this build was to find a replacement mounting bracket which can accommodate the case as well as the XGM cable.

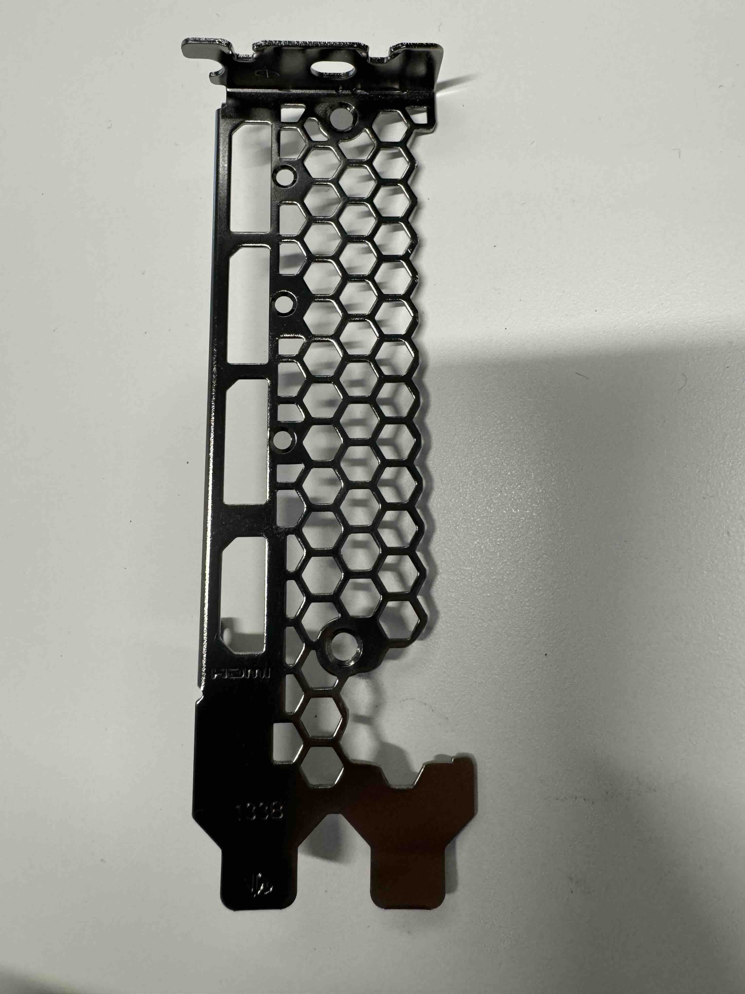
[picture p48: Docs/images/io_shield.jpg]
IO shield modded


We removed the bracket from a PNY 3050 because it had the same mounting screws as the 4070 Ti SUPER. Next, we used pliers to remove the right side (which protruded a little) and create a hole large enough to fit the XGM cable.

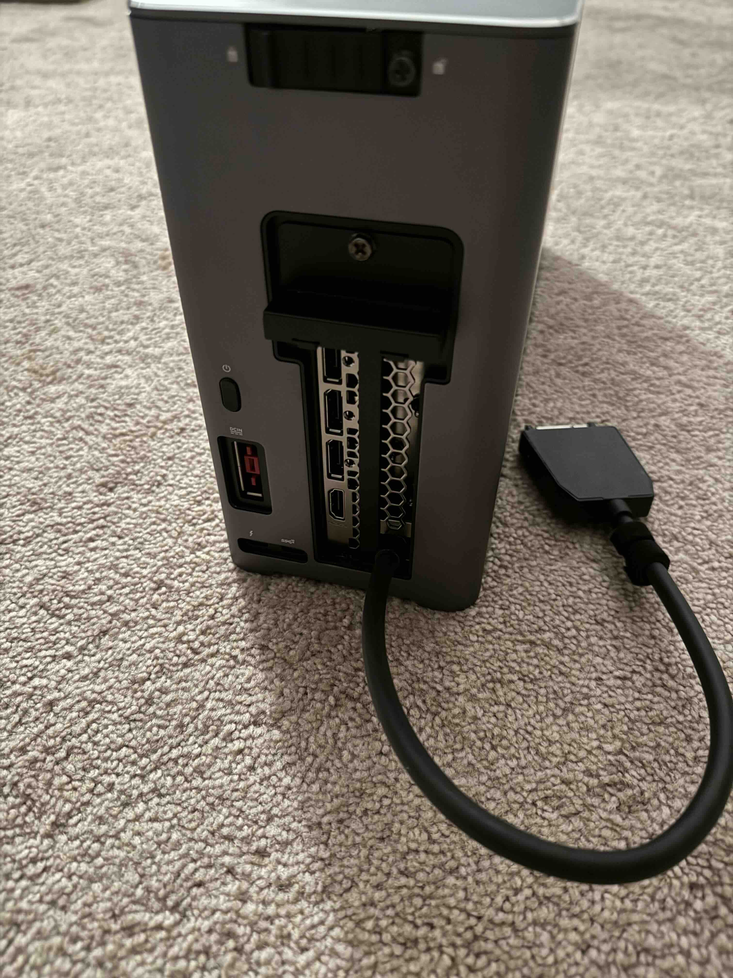
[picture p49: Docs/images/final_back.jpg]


With the mounting bracket installed, the GPU fits securely inside the enclosure and the cable is also protected against accidental pulls.

## Final Build (rev. 6)
We weren't happy with the solution in rev. 4 which required mounting the original logic board in order to steal the 12V DC-DC converter and not have to design our own. The heat output from the GPU made it hard for the board to stick to the top of the case with electrical tape. Additionally, there was no room to mount the case fans and the top mounted board impeded airflow even more. As a result, we decided to bite the bullet and add our own 2x 150W @ 12V DC-DC power supply along and a PWM fan controller as well. The final design of rev. 6 is now a complete logic board replacement.

After installation

After installation with cable

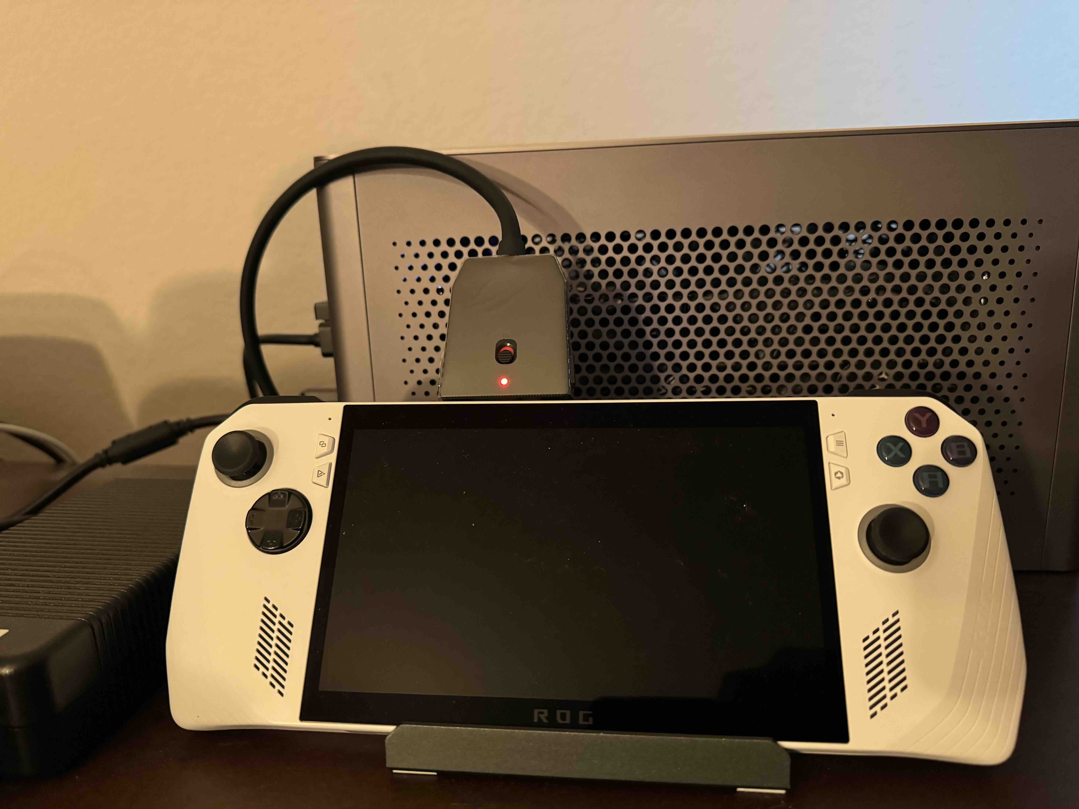
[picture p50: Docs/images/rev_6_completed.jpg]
ROG Ally connected with completed build


Here is a box of all the various revisions that we tested:

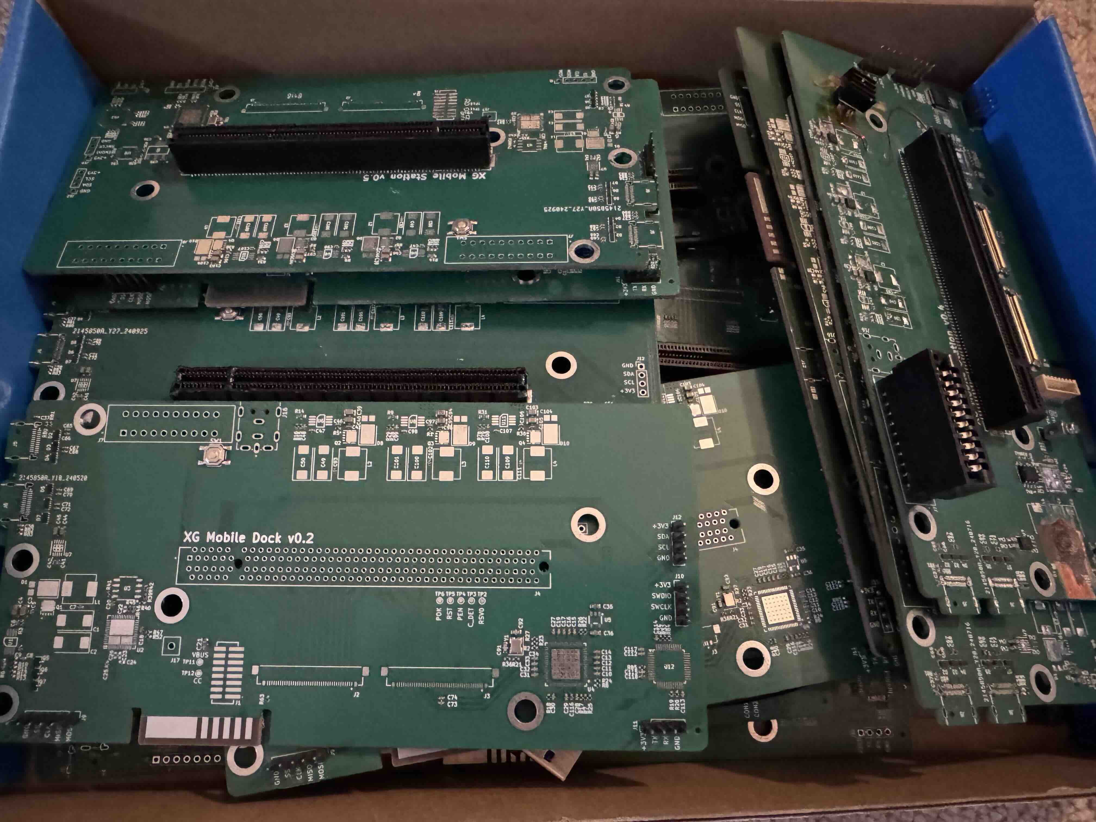
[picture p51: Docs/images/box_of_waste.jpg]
Box of waste boards


### Performance
We are able to get PCIe 4.0 x4 speeds meaning that it will perform similar to an OCuLink x4 setup.

GPU-Z
Timespy
CUDA-Z

Some context for the Timespy graphics score (note that real world performance will often differ from benchmarks):

* It is 4% lower than the average score for 4070 Ti SUPER
* It is 15% higher than the score for the XG Mobile 4090
* It is 26% higher than the same GPU connected to an Ally X through Thunderbolt

### Thermals
The XG Station Pro's power supply is rated for 330W and the Ally charging maxes out at 60W so realistically we have 270W for the GPU (or less if USB devices are connected). Although for short bursts, it seems that the power supply was able to drive upwards of 380W without issue, that may be dangerous for long term use. We decided to undervolt the 4070 Ti SUPER to 265W which reduced performance by about 1.5%.

The XG Station Pro has two case fans but we removed one of them for space issues and we kept the other one disconnected in order to reduce power consumption (and because the fan sit behind the GPU's backplate). As a result, the case fans were not used.

At 265W, we ran FurMark for 45 minutes and there was no thermal throttling. The GPU temperatures stabilized at 70C while the outside of the case got to 47C. The power supply was around 38C. Ambient temperature was 25C.

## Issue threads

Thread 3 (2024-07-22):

[Feature Request] Basic open enclosure

storm1er, 2024-07-22:
Hello

Explicit title: even if we can use/mod the original xg mobile enclosure, it would be nice to have a basic open enclosure provided as a STL/step/other format so we could 3d print or order it from somewhere else by providing the enclosure file.

I don't think people would expect specific enclosure for their GPU, that's why I'm talking about an open one.

1/ Are you planning on providing one in here?

2/ Can someone else could create a PR with it? _(not me, I'll take months if I do)_

osy, 2024-07-22:
I have no plans to do anything beyond what you see here and any bugs that may come up.

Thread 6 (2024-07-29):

VL822-QFN76 discontinued

cjb-eng, 2024-07-29:
Tried to source parts for this design but JLCPCB has informed me that my order for the VL822-QFN76 was cancelled because the part is discontinued. Is there a suitable replacement, perhaps a more expensive alternative so I can complete the BOM and get this built?

osy, 2024-07-29:
First of all, fyi there's been fixes to the board since v4 so make sure you're using the latest design. How many boards are you building? Last I saw there was still parts in stock.

cjb-eng, 2024-07-30:
I'm only looking to produce a couple of units for bench testing. I believe I've downloaded the v0.4 posted as the latest but maybe that's where I've gone wrong - does that BOM not contain this obsolete component?

osy, 2024-07-30:
There is no v0.4.1 which is not yet released. I've attached the files below.
[BOM-XG_Mobile_Dock.csv](https://github.com/user-attachments/files/16421498/BOM-XG_Mobile_Dock.csv)
[CPL-XG_Mobile_Dock.csv](https://github.com/user-attachments/files/16421499/CPL-XG_Mobile_Dock.csv)
[GERBER-XG_Mobile_Dock.zip](https://github.com/user-attachments/files/16421500/GERBER-XG_Mobile_Dock.zip)

I don't know why JLCPCB says it's discontinued. How are you buying it? I see there's 18 in stock right now.
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

cjb-eng, 2024-07-30:
I'm just trying to order via JLCPCB parts. Posted a screen capture of my
order history below in case that's helpful. You can see my order for
VL822-QFN76 was cancelled - the other bom parts appear to have processed
fine. Where do you see there are 18 in stock? My view of the parts status
shows 0 in stock.

I'm wondering if this is a regional issue. I'm trying to place this order
from the US. Do you happen to be ordering from a different country?

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

osy, 2024-07-30:
I don't see your screenshot but here's what I see in the bill of materials screen when ordering
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
I clicked the search button then clicked on the only part and I see "People are selling their idle parts:"

cjb-eng, 2024-07-30:
This is very strange. I attached a couple of PNGs hopefully those come
through. I definitely do not see any stock of that same part on their page.

I guess I'll follow-up with support and include your screen shot to
demonstrate others do find them in stock. If they won't sell the parts to
me, the least they can do is refund me the other parts as they're useless
to me if I can't source the VL822. And it showed stock when I placed the
order...

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

osy, 2024-07-30:
FWIW, the dock still works without the USB hub. It's just that on the Ally, there's only one USB port so you can't connect anything without a hub.

cjb-eng, 2024-07-30:
Ahh, good to know. In that case, I'll priced to have the board produced.
I'll come back here when support gets back to me.

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

cjb-eng, 2024-07-30:
So JLCPCB support confirms the part status has become unavailable. And
looking at your screen grab now with fresh eyes, I  see you're looking at
the idle inventory of another JLCPCB customer that's trying to sell off the
excess inventory they bought on the website. I'd completely blew through
that detail and went straight to order direct from JLCPCB at the BOM
process stage. Adding to the confusion, if you perform a direct search of
that part outside of the BOM process using the part manager, it isn't
immediately obvious that there is idle stock. You need to click on the
listed component to right of the displayed part's link (don't click on the
part's link as that will navigate you away from the page) in the white
non-obvious area. Only then does a drop down appear showing idle parts
availability. Maybe others (unfamiliar with JLCPCB as I am) looking to do
their own build will find this info helpful. Anyhow, I went back and
secured those idle components to fulfill my BOM so I'm looking forward to
testing this out with a RTX2060 I have sitting on the shelf.

But once those remaining (now 16) idle components are sold off I gather the
only option is to have the assemblies built without the USB functionality
as you mention. Do you know if there is a drop-in replacement from a
different manufacturer (e.g. Realtek)?

On Mon, Jul 29, 2024, 11:46 PM Christopher Beaudoin <
***@***.***> wrote:

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

osy, 2024-07-30:
There's no drop in replacement, but I see a couple of options

1. You can [consign parts](https://jlcpcb.com/help/article/245-How-to-consign-parts-to-JLCPCB) and order it outside of JLCPCB.
2. You can design a new board around RTS5423 or USB7216C or similar ICs. They combine USB PD controller and USB hub so you can get rid of the TI PD controller as well. Maybe the combined cost will be cheaper.
3. You can remove both the PD and hub controller and pass through the USB-C directly to a USB-C port. You will only get a single USB-C port and you can attach an external hub.

cjb-eng, 2024-07-30:
Great thanks for the thoughts. Good reason for me to pickup KiCAD

Closed 2024-07-30.

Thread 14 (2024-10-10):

Designator J15 missing from BOM-XG_Mobile_Dock_Lite.csv

chemmech, 2024-10-10:
Designator J15 is listed in CPL-XG_Mobile_Dock_Lite.csv but absent from BOM-XG_Mobile_Dock_Lite.csv, causing an error when processing the BOM and CPL on JLCPCB.

osy, 2024-10-10:
That's fine

Closed 2024-11-03.

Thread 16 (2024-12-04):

USB CTYPE power supply value for Rog Z13

mckim0306, 2024-12-04:
Hello, I'm currently waiting to place an order for JLCPCB and I'd like to ask you because I have a question.
It has been changed from v0.5.1 to 100W -> 65W based on the latest release,
Is Turbo Mode supported on the Rog Flow series?
If not, should I proceed with the change in the hardware?
Or is it a software-controlled part?

osy, 2024-12-04:
if you're building the lite version that change doesn't apply because the lite version doesn't have any active usb component, it just passes through the usb port. If you're building the full board, you can still configure the TI PD to 100W (20V 5A) and it will work. However, the reason why I lowered it to 65W is because the XG Station Pro power supply is 330W so if you allocate 100W to the charger, you only have 230W left for the GPU meaning you can't use some of the higher end cards. On the Ally, 65W is all that's needed for turbo mode and therefore I lowered it to that.

Closed 2024-12-04.

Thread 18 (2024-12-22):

Can the ROG Ally be equipped with two USB-C ports like the Ally X?

gaowanliang, 2024-12-22:
To be honest, I think most people aren't very interested in using an eGPU with handheld devices, including myself. However, if it were possible to reverse-engineer the XG Mobile interface to provide USB-C functionality, I believe many people would be quite interested. Unfortunately, I have no knowledge of hardware. Is this feasible?

moni11811, 2024-12-22:
Cost to build is around $200/5 + $100 for the cable + GPU and according to my testing it loses around 3% performance (when using a RTX 3070 Ti) vs desktop.

vs 2k, lower performance, and non-upgradeability makes this project (and OSY's work) the most valuable and high quality Ive seen on Github recently.

If you have any other (non-constructive) criticisms an open issue is not the place - a reddit post or discussion thread is...

gaowanliang, 2024-12-22:
我将将其转移到discussions

moni11811, 2024-12-22:
Hey - I want to apologize I didn't mean to go off on you like that earlier - I skimmed through your description and missed your title.

For the Ally X you're better off purchasing ADT-UT3G or TH3P4G3 than trying to build your own... also the loss in performance/bandwidth is much higher than this protocol/Oculink (32GBPS vs 63GBPS).

gaowanliang, 2024-12-22:
> Hey - I want to apologize I didn't mean to go off on you like that earlier - I skimmed through your description and missed your title.
>
> For the Ally X you're better off purchasing ADT-UT3G or TH3P4G3 than trying to build your own... also the loss in performance/bandwidth is much higher than this protocol/Oculink (32GBPS vs 63GBPS).

No problem, my friend. I think I wasn't clear enough in my description. What I'm thinking is to convert the XMG interface on the first-generation Ally into a Type-C interface, just like the Ally X, which has two Type-C ports, as [discussed in this post](https://www.reddit.com/r/ROGAlly/comments/1d7xzga/xg_mobile_usb_c_adapter/). After all, using a graphics card docking station with a handheld device does seem a bit impractical, as it requires us to sit at a desk. So why not just use my desktop? However, if we could convert this interface into a Type-C port, I believe it could be more useful.

moni11811, 2024-12-22:
Too much loss for one USB-C and not feasible for dual USB-C implementation...

Wait for TB5

Closed 2024-12-22.

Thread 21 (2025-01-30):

[Question] Oculink Adapter

Black-Seraph, 2025-01-30:
How feasible would it be to produce a minimal board that maps the XGM port to Oculink?

Such an adapter would allow the ROG Ally to share the same eGPU dock with other handhelds.

Furthermore I can't help but notice that your development diary mentioned this very same potential in the first few paragraphs, so it must have crossed your mind as well at some point.

I figure there must have been some roadblock along the way that made you decide against it, and I figured I'd go ahead and ask to get some clarification.

osy, 2025-01-30:
The main issue is that you have twice the cable length and thus need redrivers.

Closed 2025-01-30.

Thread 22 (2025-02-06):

Linux support

Quoteme, 2025-02-06:
I just skimmed over your project and noticed that some drivers are required. These are specifically written for windows (it seems?).
I would like to use this mod with my asus rog flow x13 running linux though. Is this possible?

osy, 2025-02-06:
No drivers are required except your GPU drivers. Windows need a mod to recognize hot plug.

Closed 2025-02-06.

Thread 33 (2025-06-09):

Lite board connection guide

TimmyOl, 2025-06-09:
Hello, i have just assembled some Lite boards, but its a little unclear what to connect, or is all the extra connections for the xg mobile station?

The question is really, for the Lite board standalone, do i only need to connect the xg cable, an ATX PSU, GPU and a usb-c hub with the charger and keyboard etc. or do i need something more in the other connectors not seemingly used if we dont have a xg mobile station?

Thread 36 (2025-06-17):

Xg connecting but no GPU is added in Windows

TimmyOl, 2025-06-17:
Hello again.

**My setup:**

- Lite board with x-ray images and all the settings and impedance testing from JLCPCB as described in the guide with successful ST flash.
- 650w ATX PSU brand new
- XFX RX 7800 XT Swift 319 Core (new)
- 100w charger (Gives 30w turbo)
- 100w usb dock (Gives 30w turbo with mouse and keyboard connected)
- Asus rog 32" curved 1080p monitor connected to GPU with Displayport (Also tested with hdmi)

**What works:**
When i connect everything except the xg mobile connector and turn the PSU on, the fans on the GPU starts.
Now i connect the xg mobile connector to the Ally and the white light comes on, all the USB passthrough works as intended. a pop-up says XG mobile connected.
now i switch the lock on the xg mobile cable.
The led turns red and the ally asks if i want to switch to the xg mobile, i press yes (first it wanted me to restart and updated, but i reinstalled the amd version of the XGM Driver so now it connects and then says connected again.
If i connect by restarting the PSU entirelly and the Ally aswell when i drag the lock the fans on the GPU goes up to what i think is max so the GPU is also reacting to the connection.

**What does not work:**
When i have done all the steps above, nothing more happens, i dont have a GPU in device manager or anywhere.
And (This is where you probably can get a hint if something is wrong in software or hardware?) if i follow these steps the GPU just like before reacts but not nearly as much and then the red light is red sometimes 10 seconds, and sometimes 20 seconds before the fans goes down to a stop just to start again and the light turns red again for the same interval again.

**These are the steps to reproduce this:**
I dont do a reboot on the Ally just click the xg mobile icon and select disconnect and then unlock the cable and disconnect the cable.
now reboot the PSU and reconnect it and switch the lock
the loop is now active for about 5-10 runs then stays white until i reboot the ally (then it goes in to the same loop until its white).
or until i remove the xg mobile, restart the ally and the PSU, then i can choose to either have full speed fans or the interval of turning the gpu and red light on and off.

**What have i tried:**

- I have used DDU to uninstall GPU drivers and testing both amd official drivers and the ones installed from armory crate.
- I have tried G-Helper (This shows no errors and the red light is constant and it says connected like it works perfectly but there is no GPU in windows.).
- I have tried reseating the cable to be sure the cable is seated correctly in the connectors.
- i have updated all drivers and windows so no updates are available in myasus, windows or armory crate.
- I have GPU-Z to check if i can see the GPU in there even though its not showing in the Device Manager.
- I have checked the settings.ini and it looks correct from your diary changing the status in the file.
- I have tried with only usb power and no usb hub
- i have tried with no cables (except power ofcourse) to the GPU
- i have tried both HDMI and DP to the GPU

**Info**
so i have 2 different things i can do (Because it does not seem to disconnect since it does not connect completely so one loop is without rebooting and forcing the disconnect, and the other is when it is connecting) and i have tried all i can think of so i am not sure what could cause this (I know this is probably impossible for you to answer but cannot figure more testing out so better to ask than not to ask), can it be something with me using an RX 7800 XT with the XGMDriver or can it be some hardware (soldering or something gone bad?). i have soldered the ATX connector myself, all other is soldered by JLCPCB.

osy, 2025-06-17:
Many people reported issues trying to get AMD gpus to recognize. Do you have access to an NVIDIA gpu to try? Also please join our Discord if you want to troubleshoot with more people https://discord.gg/2kyggvEtfJ

TimmyOl, 2025-06-18:
i picked up an asus nvidia rtx 5070 to see if that works, all the issues with the connection is gone, it turns red and the connection is made every time.
the GPU fans spin alittle when i turn the power on the board. but then nothing. device manager is not showing anything even though it says connected everywhere.

i have tried soldering a new card and i have the exact same issue on both of them, so probably not the card.

The 5070 becomes hot but the fans never start (after the initial spins when i turn the PSU on. this is also a difference from the rx 7800 xt that had the fans seemingly running correctly but the same issue with windows not showing anything when connected.

TimmyOl, 2025-06-18:
ok so i actually got it to work.

i had to do this though:
1. install the xgmdriver
2. plug in the gpu and click the activate gpu prompt
3. restart when update is complete
4. Now when i restarted a generic device was hidden in device manager
5. Install geforce drivers (it now works since the hidden device is a geforce even though it says generic display device)
6. had to restart then run the installation of geforce again
7. run the error 43 script
8. now i got it to work (have not dared to test to disconnect it again)

Closed 2025-06-18.

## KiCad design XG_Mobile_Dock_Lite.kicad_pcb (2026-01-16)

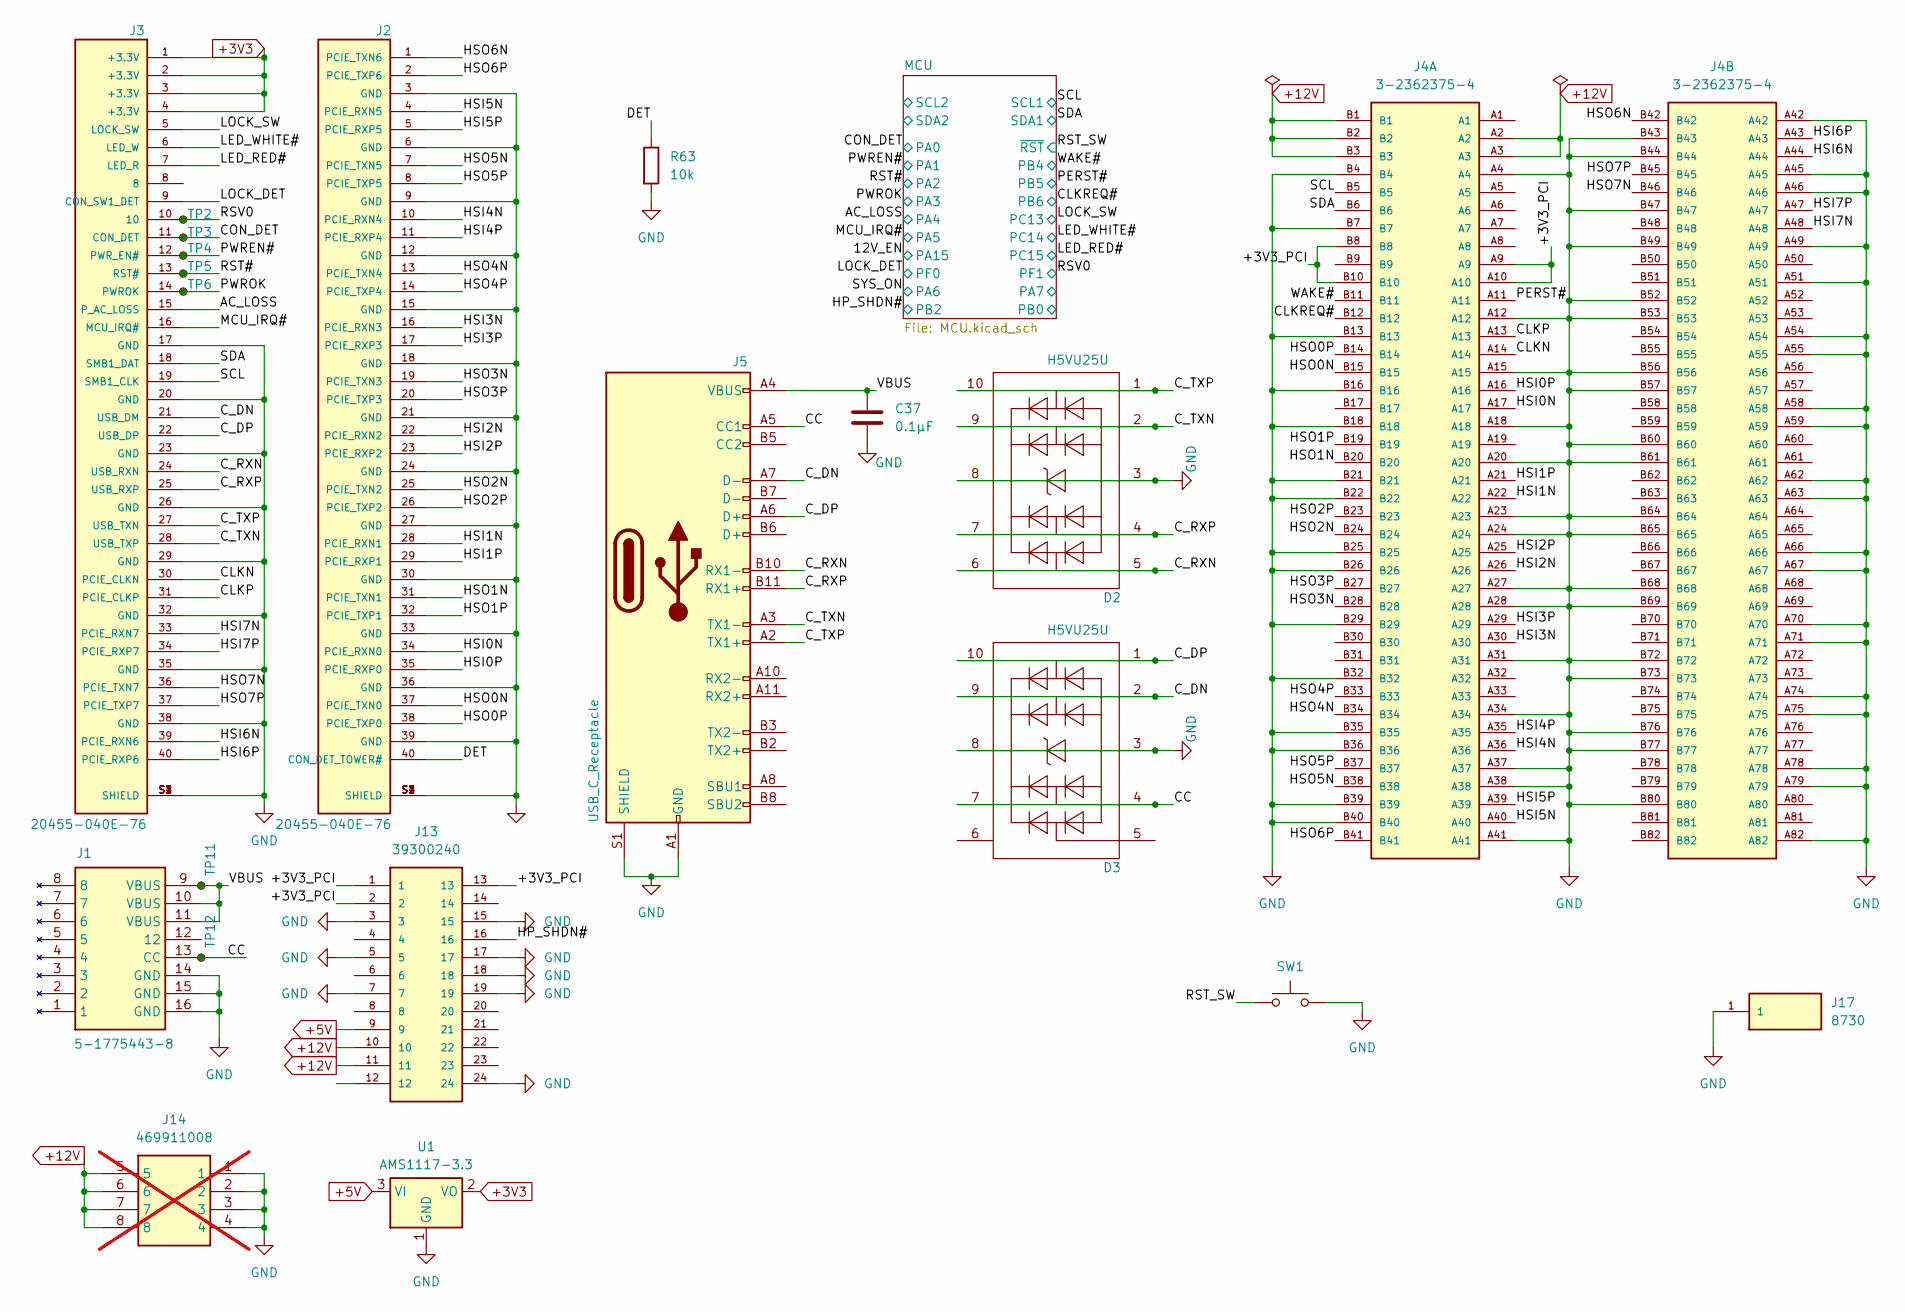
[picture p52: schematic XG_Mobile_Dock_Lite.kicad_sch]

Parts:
C37: 0.1μF; C_0402_1005Metric; Part_Number CL05B104KO5NNNC; LCSC C1525
D2, D3: H5VU25U; AZ1045-04F; Part_Number H5VU25U; LCSC C7420374
J1: 5-1775443-8; Manufacturer_Part_Number 5-1775443-8
J2, J3: 20455-040E-76; Part_Number 20455-040E-76; LCSC C5160883
J4: 3-2362375-4; CONN-SMD_164P-P1.00-V_3133; Part_Number 3113-113T; LCSC C404104
J5: USB_C_Receptacle; USB-C-SMD_TYPE-C-24P-QT; Part_Number TYPE-C 24P QT; LCSC C2681555
J13: 39300240; CON_39300240; Part_Number ZX-5557-4.2-2-12PWZ; LCSC C7541574
J14: 469911008; CON_469911008; Part_Number 469911008; LCSC C17470577; not fitted
J17: 8730; KEYSTONE_8730; PARTREV C
R63: 10k; R_0402_1005Metric; Part_Number 0402WGF1002TCE; LCSC C25744
SW1: SW_Push; SW_SPST_SKQG_WithStem; Part_Number TS-1187A-B-A-B; LCSC C318884
TP2, TP3, TP4, TP5, TP6, TP11, TP12: TestPoint_Small; TestPoint_Pad_D1.0mm
U1: AMS1117-3.3; SOT-223-3_TabPin2; Part_Number AMS1117-3.3; LCSC C6186

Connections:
+3V3: J3.1 (+3.3V), J3.2 (+3.3V), J3.3 (+3.3V), J3.4 (+3.3V), U1.2 (VO); also elsewhere on the board
+5V: J13.9, U1.3 (VI); also elsewhere on the board
+12V: J4.A2, J4.A3, J4.B1, J4.B2, J4.B3, J13.10, J13.11, J14.5, J14.6, J14.7, J14.8; also elsewhere on the board
/+3V3_PCI: J4.A9, J4.A10, J4.B8, J4.B10, J13.1, J13.2, J13.13
/AC_LOSS: J3.15 (P_AC_LOSS); also elsewhere on the board
/CC: D3.4 (I/O_3), D3.7 (NC), J1.13 (CC), J5.A5 (CC1), TP12.1
/CLKN: J3.30 (PCIE_CLKN), J4.A14
/CLKP: J3.31 (PCIE_CLKP), J4.A13
/CLKREQ#: J4.B12; also elsewhere on the board
/CON_DET: J3.11 (CON_DET), TP3.1; also elsewhere on the board
/C_DN: D3.2 (I/O_2), D3.9 (NC), J3.21 (USB_DM), J5.A7 (D-)
/C_DP: D3.1 (I/O_1), D3.10 (NC), J3.22 (USB_DP), J5.A6 (D+)
/C_RXN: D2.5 (I/O_4), D2.6 (NC), J3.24 (USB_RXN), J5.B10 (RX1-)
/C_RXP: D2.4 (I/O_3), D2.7 (NC), J3.25 (USB_RXP), J5.B11 (RX1+)
/C_TXN: D2.2 (I/O_2), D2.9 (NC), J3.28 (USB_TXP), J5.A3 (TX1-)
/C_TXP: D2.1 (I/O_1), D2.10 (NC), J3.27 (USB_TXN), J5.A2 (TX1+)
/DET: J2.40 (CON_DET_TOWER#), R63.1
/HP_SHDN#: J13.16; also elsewhere on the board
/HSI0N: J2.34 (PCIE_RXN0), J4.A17
/HSI0P: J2.35 (PCIE_RXP0), J4.A16
/HSI1N: J2.28 (PCIE_RXN1), J4.A22
/HSI1P: J2.29 (PCIE_RXP1), J4.A21
/HSI2N: J2.22 (PCIE_RXN2), J4.A26
/HSI2P: J2.23 (PCIE_RXP2), J4.A25
/HSI3N: J2.16 (PCIE_RXN3), J4.A30
/HSI3P: J2.17 (PCIE_RXP3), J4.A29
/HSI4N: J2.10 (PCIE_RXN4), J4.A36
/HSI4P: J2.11 (PCIE_RXP4), J4.A35
/HSI5N: J2.4 (PCIE_RXN5), J4.A40
/HSI5P: J2.5 (PCIE_RXP5), J4.A39
/HSI6N: J3.39 (PCIE_RXN6), J4.A44
/HSI6P: J3.40 (PCIE_RXP6), J4.A43
/HSI7N: J3.33 (PCIE_RXN7), J4.A48
/HSI7P: J3.34 (PCIE_RXP7), J4.A47
/HSO0N: J2.37 (PCIE_TXN0), J4.B15
/HSO0P: J2.38 (PCIE_TXP0), J4.B14
/HSO1N: J2.31 (PCIE_TXN1), J4.B20
/HSO1P: J2.32 (PCIE_TXP1), J4.B19
/HSO2N: J2.25 (PCIE_TXN2), J4.B24
/HSO2P: J2.26 (PCIE_TXP2), J4.B23
/HSO3N: J2.19 (PCIE_TXN3), J4.B28
/HSO3P: J2.20 (PCIE_TXP3), J4.B27
/HSO4N: J2.13 (PCIE_TXN4), J4.B34
/HSO4P: J2.14 (PCIE_TXP4), J4.B33
/HSO5N: J2.7 (PCIE_TXN5), J4.B38
/HSO5P: J2.8 (PCIE_TXP5), J4.B37
/HSO6N: J2.1 (PCIE_TXN6), J4.B42
/HSO6P: J2.2 (PCIE_TXP6), J4.B41
/HSO7N: J3.36 (PCIE_TXN7), J4.B46
/HSO7P: J3.37 (PCIE_TXP7), J4.B45
/LED_RED#: J3.7 (LED_R); also elsewhere on the board
/LED_WHITE#: J3.6 (LED_W); also elsewhere on the board
/LOCK_DET: J3.9 (CON_SW1_DET); also elsewhere on the board
/LOCK_SW: J3.5 (LOCK_SW); also elsewhere on the board
/MCU_IRQ#: J3.16 (MCU_IRQ#); also elsewhere on the board
/PERST#: J4.A11; also elsewhere on the board
/PWREN#: J3.12 (PWR_EN#), TP4.1; also elsewhere on the board
/PWROK: J3.14 (PWROK), TP6.1; also elsewhere on the board
/RST#: J3.13 (RST#), TP5.1; also elsewhere on the board
/RST_SW: SW1.1; also elsewhere on the board
/RSV0: J3.10, TP2.1; also elsewhere on the board
/SCL: J3.19 (SMB1_CLK), J4.B5; also elsewhere on the board
/SDA: J3.18 (SMB1_DAT), J4.B6; also elsewhere on the board
/VBUS: C37.1, J1.9 (VBUS), J1.10 (VBUS), J1.11 (VBUS), J5.A4 (VBUS), J5.A9 (VBUS), J5.B4 (VBUS), J5.B9 (VBUS), TP11.1
/WAKE#: J4.B11; also elsewhere on the board
GND: C37.2, D2.3 (GND), D2.8 (GND), D3.3 (GND), D3.8 (GND), J1.14 (GND), J1.15 (GND), J1.16 (GND), J2.3 (GND), J2.6 (GND), J2.9 (GND), J2.12 (GND), J2.15 (GND), J2.18 (GND), J2.21 (GND), J2.24 (GND), J2.27 (GND), J2.30 (GND), J2.33 (GND), J2.36 (GND), J2.39 (GND), J2.S1 (SHIELD), J2.S2 (SHIELD), J2.S3 (SHIELD), J2.S4 (SHIELD), J3.17 (GND), J3.20 (GND), J3.23 (GND), J3.26 (GND), J3.29 (GND), J3.32 (GND), J3.35 (GND), J3.38 (GND), J3.S1 (SHIELD), J3.S2 (SHIELD), J3.S3 (SHIELD), J3.S4 (SHIELD), J4.A4, J4.A12, J4.A15, J4.A18, J4.A20, J4.A23, J4.A24, J4.A27, J4.A28, J4.A31, J4.A34, J4.A37, J4.A38, J4.A41, J4.A42, J4.A45, J4.A46, J4.A49, J4.A51, J4.A54, J4.A55, J4.A58, J4.A59, J4.A62, J4.A63, J4.A66, J4.A67, J4.A70, J4.A71, J4.A74, J4.A75, J4.A78, J4.A79, J4.A82, J4.B4, J4.B7, J4.B13, J4.B16, J4.B18, J4.B21, J4.B22, J4.B25, J4.B26, J4.B29, J4.B32, J4.B35, J4.B36, J4.B39, J4.B40, J4.B43, J4.B44, J4.B47, J4.B49, J4.B52, J4.B53, J4.B56, J4.B57, J4.B60, J4.B61, J4.B64, J4.B65, J4.B68, J4.B69, J4.B72, J4.B73, J4.B76, J4.B77, J4.B80, J5.A1 (GND), J5.A12 (GND), J5.B1 (GND), J5.B12 (GND), J5.S1 (SHIELD), J13.3, J13.5, J13.7, J13.15, J13.17, J13.18, J13.19, J13.24, J14.1, J14.2, J14.3, J14.4, J17.1, R63.2, SW1.2, U1.1 (GND); also elsewhere on the board

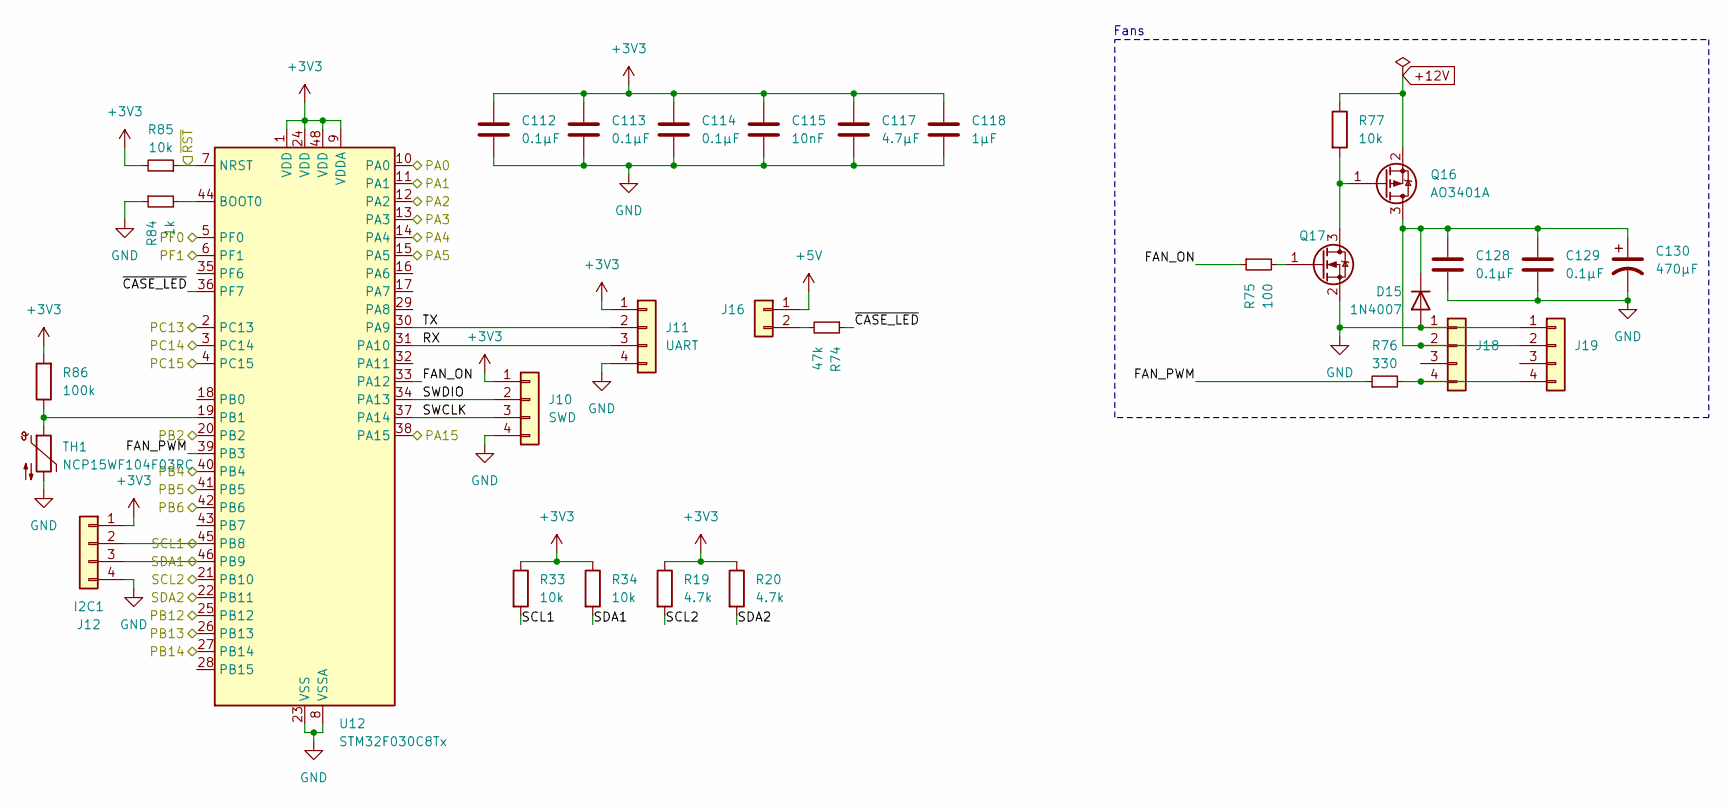
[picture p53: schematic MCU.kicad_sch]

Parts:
C112, C113, C114: 0.1µF; C_0402_1005Metric; Part_Number CL05B104KB54PNC; LCSC C307331
C115: 10nF; C_0402_1005Metric; Part_Number CL05B103KB5NNNC; LCSC C15195
C117: 4.7µF; C_0402_1005Metric; Part_Number CL05A475MP5NRNC; LCSC C23733
C118: 1µF; C_0402_1005Metric; Part_Number CL05A105KA5NQNC; LCSC C52923
C128, C129: 0.1µF; C_0603_1608Metric; Part_Number CC0603KRX7R9BB104; LCSC C14663
C130: 470µF; CP_Radial_D10.0mm_P5.00mm; Part_Number EGT477M1HG16RRS0P; LCSC C3015599
D15: 1N4007; D_SOD-123F; Part_Number 1N4007W; LCSC C18199088
J10: SWD; PinHeader_1x04_P2.54mm_Vertical; Part_Number 2.54-1*4; LCSC C5116483
J11: UART; PinHeader_1x04_P2.54mm_Vertical; Part_Number 2.54-1*4; LCSC C5116483
J12: I2C1; PinHeader_1x04_P2.54mm_Vertical; Part_Number 2.54-1*4; LCSC C5116483
J16: JST_PH_S2B-PH-K_1x02_P2.00mm_Horizontal; Part_Number S2B-PH-KL(LF)(SN); LCSC C160237
J18, J19: CONN_SD-47053-001_H10p00_MOL; Part_Number 470531000; LCSC C240840
Q16: AO3401A; SOT-23; Part_Number AO3401A; LCSC C15127
Q17: 2N7002W; SOT-323-3_L2.0-W1.3-P1.30-LS2.1-BR; Part_Number 2N7002W; LCSC C7420322
R19, R20: 4.7k; R_0402_1005Metric; Part_Number 0402WGF4701TCE; LCSC C25900
R33, R34, R77, R85: 10k; R_0402_1005Metric; Part_Number 0402WGF1002TCE; LCSC C25744
R74: 47k; R_0402_1005Metric; Part_Number 0402WGF4702TCE; LCSC C25792
R75: 100; R_0402_1005Metric; Part_Number 0402WGF1000TCE; LCSC C25076
R76: 330; R_0402_1005Metric; Part_Number 0402WGF3300TCE; LCSC C25104
R84: 1k; R_0402_1005Metric; Part_Number 0402WGF1001TCE; LCSC C11702
R86: 100k; R_0402_1005Metric; Part_Number 0402WGF1003TCE; LCSC C25741
TH1: NCP15WF104F03RC; R_0402_1005Metric; Part_Number NCP15WF104F03RC; LCSC C77130
U12: STM32F030C8Tx; LQFP-48_7x7mm_P0.5mm; Part_Number STM32F030C8T6; LCSC C23922

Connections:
+3V3: C112.1, C113.1, C114.1, C115.1, C117.1, C118.1, J10.1, J11.1, J12.1, R19.1, R20.1, R33.1, R34.1, R85.2, R86.2, U12.1 (VDD), U12.9 (VDDA), U12.24 (VDD), U12.48 (VDD); also elsewhere on the board
+5V: J16.1; also elsewhere on the board
+12V: Q16.2 (S), R77.1; also elsewhere on the board
/12V_EN: U12.38 (PA15)
/AC_LOSS: U12.14 (PA4); also elsewhere on the board
/CLKREQ#: U12.42 (PB6); also elsewhere on the board
/CON_DET: U12.10 (PA0); also elsewhere on the board
/HP_SHDN#: U12.20 (PB2); also elsewhere on the board
/LED_RED#: U12.4 (PC15); also elsewhere on the board
/LED_WHITE#: U12.3 (PC14); also elsewhere on the board
/LOCK_DET: U12.5 (PF0); also elsewhere on the board
/LOCK_SW: U12.2 (PC13); also elsewhere on the board
/MCU/FAN_ON: R75.1, U12.33 (PA12)
/MCU/FAN_PWM: R76.1, U12.39 (PB3)
/MCU/PB12: U12.25 (PB12)
/MCU/PB13: U12.26 (PB13)
/MCU/PB14: U12.27 (PB14)
/MCU/RX: J11.3, U12.31 (PA10)
/MCU/SCL2: R19.2, U12.21 (PB10)
/MCU/SDA2: R20.2, U12.22 (PB11)
/MCU/SWCLK: J10.3, U12.37 (PA14)
/MCU/SWDIO: J10.2, U12.34 (PA13)
/MCU/TX: J11.2, U12.30 (PA9)
/MCU/~CASE_LED: R74.1, U12.36 (PF7)
/MCU_IRQ#: U12.15 (PA5); also elsewhere on the board
/PERST#: U12.41 (PB5); also elsewhere on the board
/PWREN#: U12.11 (PA1); also elsewhere on the board
/PWROK: U12.13 (PA3); also elsewhere on the board
/RST#: U12.12 (PA2); also elsewhere on the board
/RST_SW: R85.1, U12.7 (NRST); also elsewhere on the board
/RSV0: U12.6 (PF1); also elsewhere on the board
/SCL: J12.2, R33.2, U12.45 (PB8); also elsewhere on the board
/SDA: J12.3, R34.2, U12.46 (PB9); also elsewhere on the board
/WAKE#: U12.40 (PB4); also elsewhere on the board
GND: C112.2, C113.2, C114.2, C115.2, C117.2, C118.2, C128.2, C129.2, C130.2, D15.2 (A), J10.4, J11.4, J12.4, J18.1, J19.1, Q17.2 (S), R84.1, TH1.2, U12.8 (VSSA), U12.23 (VSS), U12.47 (VSS); also elsewhere on the board
unnamed: C128.1, C129.1, C130.1, D15.1 (K), J18.2, J19.2, Q16.3 (D)
unnamed: J16.2, R74.2
unnamed: J18.4, J19.4, R76.2
unnamed: Q16.1 (G), Q17.3 (D), R77.2
unnamed: Q17.1 (G), R75.2
unnamed: R84.2, U12.44 (BOOT0)
unnamed: R86.1, TH1.1, U12.19 (PB1)

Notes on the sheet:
Fans

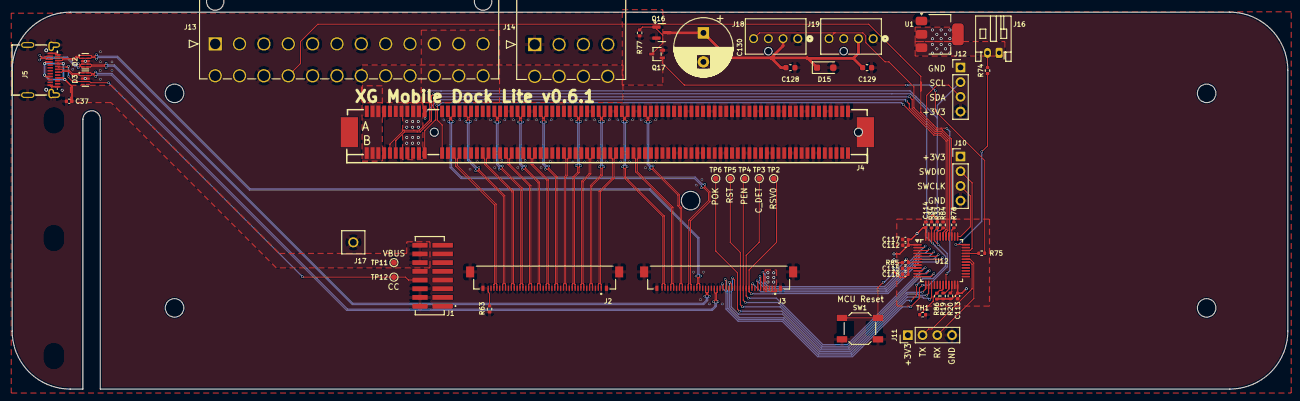
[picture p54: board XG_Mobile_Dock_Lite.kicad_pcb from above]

Board: 4 copper layers, 220.0 x 65.0 mm, 52 parts (0 on the bottom side), 82 nets.

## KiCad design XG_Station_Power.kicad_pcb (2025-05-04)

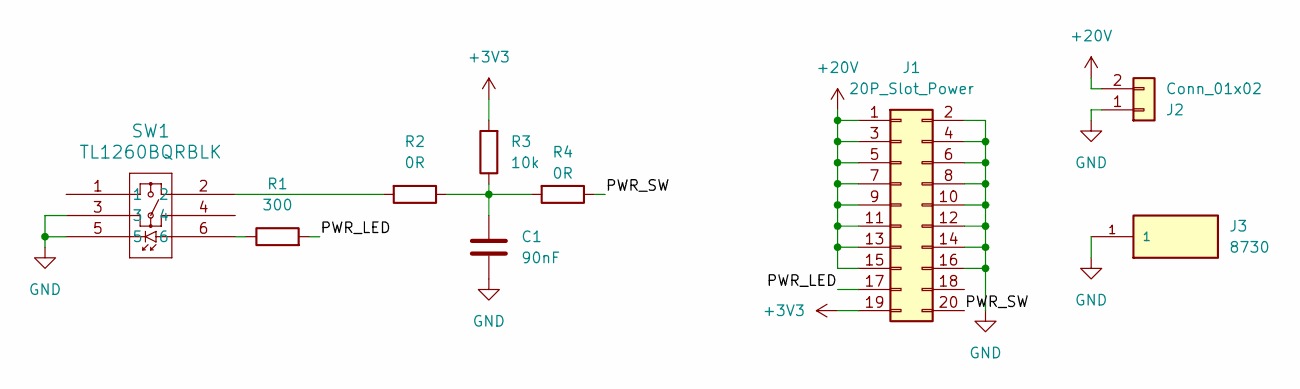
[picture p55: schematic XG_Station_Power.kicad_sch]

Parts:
C1: 90nF; C_0402_1005Metric
J1: 20P_Slot_Power
J2: Conn_01x02; 2351970-1
J3: 8730; KEYSTONE_8730; PARTREV C
R1: 300; R_0603_1608Metric
R2, R4: 0R; R_0402_1005Metric
R3: 10k; R_0402_1005Metric
SW1: TL1260BQRBLK; TL1260_EWI

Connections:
+3V3: J1.19, R3.2
+20V: J1.1, J1.3, J1.5, J1.7, J1.9, J1.11, J1.13, J1.15, J2.2
/PWR_LED: J1.17, R1.2
/PWR_SW: J1.20, R4.1
GND: C1.2, J1.2, J1.4, J1.6, J1.8, J1.10, J1.12, J1.14, J1.16, J2.1, J3.1, SW1.3, SW1.5
unnamed: C1.1, R2.1, R3.1, R4.2
unnamed: R1.1, SW1.6
unnamed: R2.2, SW1.2

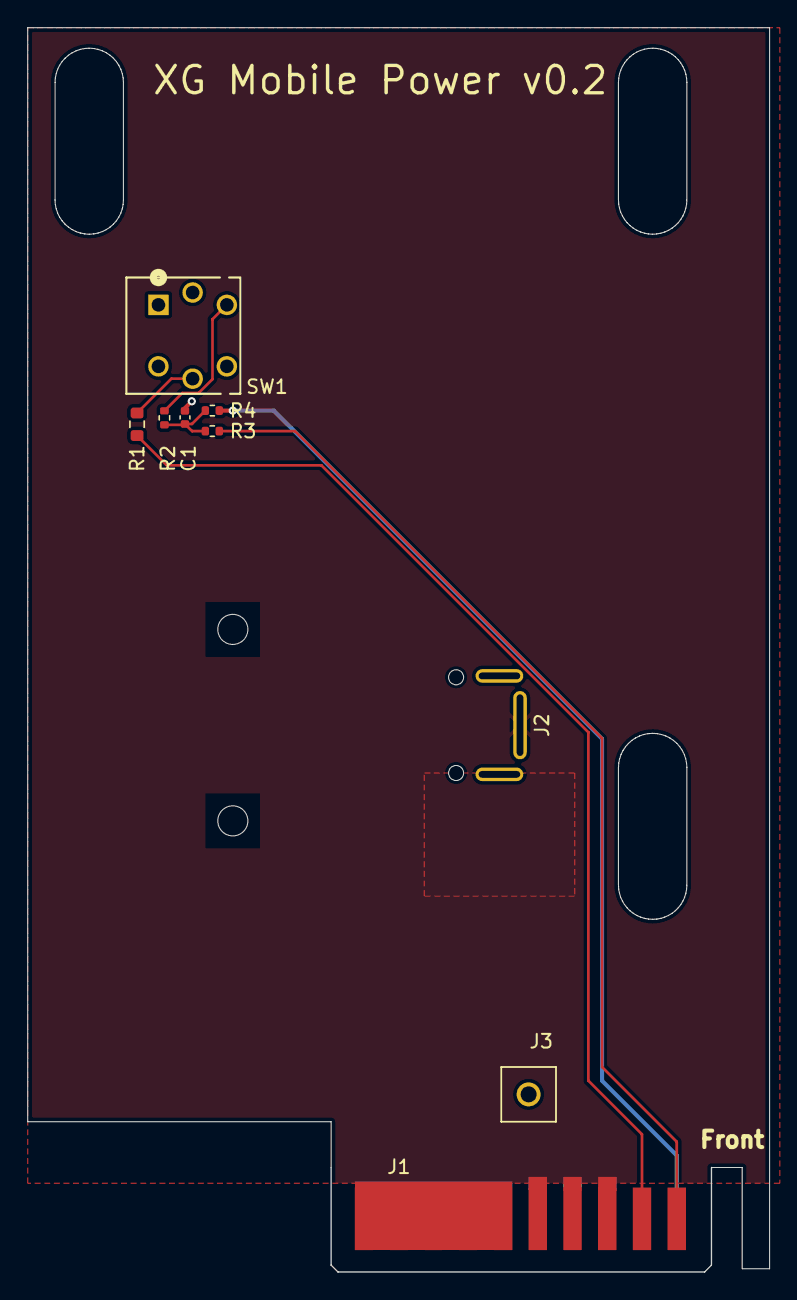
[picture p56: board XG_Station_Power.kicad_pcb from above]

Board: 2 copper layers, 54.2 x 91.0 mm, 11 parts (0 on the bottom side), 8 nets.

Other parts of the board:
Hole: MountingHole_2.2mm_M2
Hole#2: MountingHole_2.2mm_M2

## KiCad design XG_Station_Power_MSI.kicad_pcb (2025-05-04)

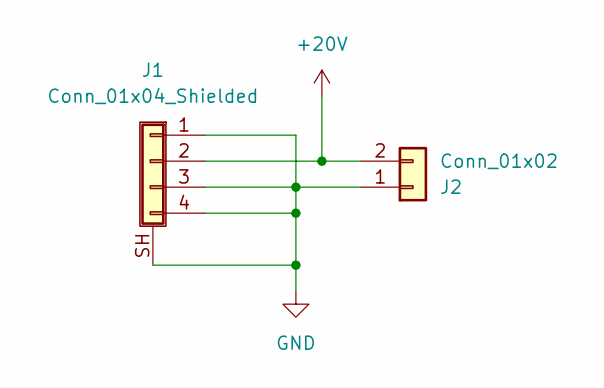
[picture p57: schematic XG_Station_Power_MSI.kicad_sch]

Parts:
J1: Conn_01x04_Shielded; MSI_Charger
J2: Conn_01x02; 2P_Slot_Power

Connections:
+20V: J1.2, J2.2
GND: J1.1, J1.3, J1.4, J1.SH (Shield), J2.1

Board: 2 copper layers, 4 parts (0 on the bottom side), 2 nets, no tracks yet.

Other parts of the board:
Hole: MountingHole_2.2mm_M2
Hole#2: MountingHole_2.2mm_M2

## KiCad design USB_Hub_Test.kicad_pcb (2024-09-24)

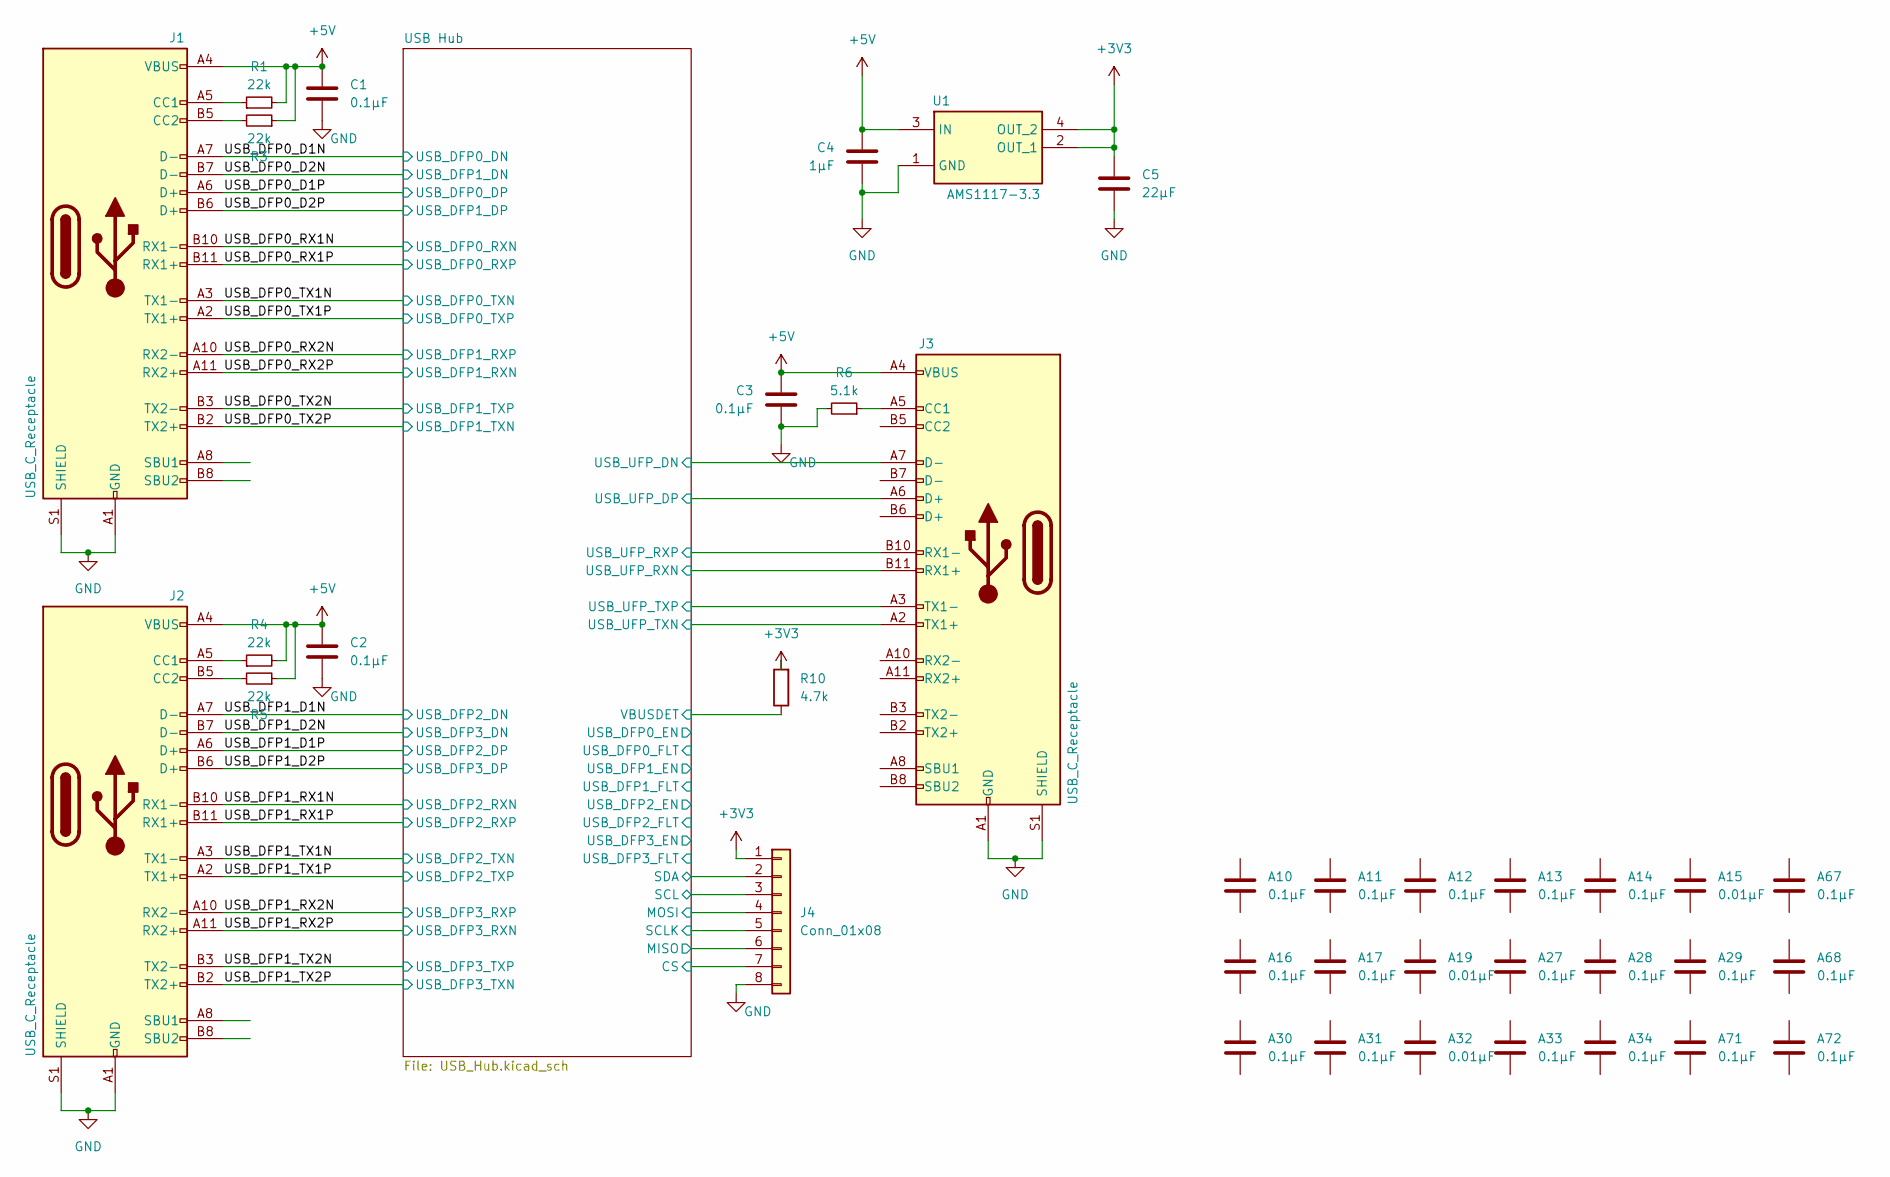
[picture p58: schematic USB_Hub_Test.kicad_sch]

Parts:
A10, A11, A12, A13, A14, A16, A17, A27, A28, A29, A30, A31, A33, A34, A67, A68, A71, A72: 0.1µF; C_0402_1005Metric; Part_Number CL05B104KB54PNC; LCSC C307331
A15, A19, A32: 0.01µF; C_0402_1005Metric; Part_Number CL05B103KB5NNNC; LCSC C15195
C1, C2, C3: 0.1μF; C_0402_1005Metric; Part_Number CL05B104KO5NNNC; LCSC C1525
C4: 1µF; C_0603_1608Metric; Part_Number CL10A105KB8NNNC; LCSC C15849
C5: 22μF; C_0603_1608Metric; Part_Number CL10A226MQ8NRNC; LCSC C59461
J1, J2, J3: USB_C_Receptacle; USB-C-SMD_TYPE-C-24P-QT; Part_Number TYPE-C 24P QT; LCSC C2681555
J4: Conn_01x08; PinHeader_1x08_P2.54mm_Vertical; Part_Number 2.54-1*8; LCSC C5156616
R1, R3, R4, R5: 22k; R_0402_1005Metric; Part_Number 0402WGF2202TCE; LCSC C25768
R6: 5.1k; R_0402_1005Metric; Part_Number 0402WGF5101TCE; LCSC C25905
R10: 4.7k; R_0402_1005Metric; Part_Number 0402WGF4701TCE; LCSC C25900
U1: AMS1117-3.3; SOT230P700X180-4N; Part_Number AMS1117-3.3; LCSC C6186

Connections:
+3V3: C5.1, J4.1, R10.2, U1.2 (OUT_1), U1.4 (OUT_2); also elsewhere on the board
+5V: C1.1, C2.1, C3.1, C4.1, J1.A4 (VBUS), J1.A9 (VBUS), J1.B4 (VBUS), J1.B9 (VBUS), J2.A4 (VBUS), J2.A9 (VBUS), J2.B4 (VBUS), J2.B9 (VBUS), J3.A4 (VBUS), J3.A9 (VBUS), J3.B4 (VBUS), J3.B9 (VBUS), R1.2, R3.1, R4.2, R5.1, U1.3 (IN)
/USB Hub/CS: J4.7; also elsewhere on the board
/USB Hub/MISO: J4.6; also elsewhere on the board
/USB Hub/MOSI: J4.4; also elsewhere on the board
/USB Hub/SCL: J4.3; also elsewhere on the board
/USB Hub/SCLK: J4.5; also elsewhere on the board
/USB Hub/SDA: J4.2; also elsewhere on the board
/USB Hub/USB_UFP_DN: J3.A7 (D-); also elsewhere on the board
/USB Hub/USB_UFP_DP: J3.A6 (D+); also elsewhere on the board
/USB Hub/USB_UFP_RXN: J3.B11 (RX1+); also elsewhere on the board
/USB Hub/USB_UFP_RXP: J3.B10 (RX1-); also elsewhere on the board
/USB Hub/USB_UFP_TXN: J3.A2 (TX1+); also elsewhere on the board
/USB Hub/USB_UFP_TXP: J3.A3 (TX1-); also elsewhere on the board
/USB Hub/VBUSDET: R10.1; also elsewhere on the board
/USB_DFP0_D1N: J1.A7 (D-); also elsewhere on the board
/USB_DFP0_D1P: J1.A6 (D+); also elsewhere on the board
/USB_DFP0_D2N: J1.B7 (D-); also elsewhere on the board
/USB_DFP0_D2P: J1.B6 (D+); also elsewhere on the board
/USB_DFP0_RX1N: J1.B10 (RX1-); also elsewhere on the board
/USB_DFP0_RX1P: J1.B11 (RX1+); also elsewhere on the board
/USB_DFP0_RX2N: J1.A10 (RX2-); also elsewhere on the board
/USB_DFP0_RX2P: J1.A11 (RX2+); also elsewhere on the board
/USB_DFP0_TX1N: J1.A3 (TX1-); also elsewhere on the board
/USB_DFP0_TX1P: J1.A2 (TX1+); also elsewhere on the board
/USB_DFP0_TX2N: J1.B3 (TX2-); also elsewhere on the board
/USB_DFP0_TX2P: J1.B2 (TX2+); also elsewhere on the board
/USB_DFP1_D1N: J2.A7 (D-); also elsewhere on the board
/USB_DFP1_D1P: J2.A6 (D+); also elsewhere on the board
/USB_DFP1_D2N: J2.B7 (D-); also elsewhere on the board
/USB_DFP1_D2P: J2.B6 (D+); also elsewhere on the board
/USB_DFP1_RX1N: J2.B10 (RX1-); also elsewhere on the board
/USB_DFP1_RX1P: J2.B11 (RX1+); also elsewhere on the board
/USB_DFP1_RX2N: J2.A10 (RX2-); also elsewhere on the board
/USB_DFP1_RX2P: J2.A11 (RX2+); also elsewhere on the board
/USB_DFP1_TX1N: J2.A3 (TX1-); also elsewhere on the board
/USB_DFP1_TX1P: J2.A2 (TX1+); also elsewhere on the board
/USB_DFP1_TX2N: J2.B3 (TX2-); also elsewhere on the board
/USB_DFP1_TX2P: J2.B2 (TX2+); also elsewhere on the board
GND: C1.2, C2.2, C3.2, C4.2, C5.2, J1.A1 (GND), J1.A12 (GND), J1.B1 (GND), J1.B12 (GND), J1.S1 (SHIELD), J2.A1 (GND), J2.A12 (GND), J2.B1 (GND), J2.B12 (GND), J2.S1 (SHIELD), J3.A1 (GND), J3.A12 (GND), J3.B1 (GND), J3.B12 (GND), J3.S1 (SHIELD), J4.8, R6.2, U1.1 (GND); also elsewhere on the board
unnamed: J1.A5 (CC1), R1.1
unnamed: J1.B5 (CC2), R3.2
unnamed: J2.A5 (CC1), R4.1
unnamed: J2.B5 (CC2), R5.2
unnamed: J3.A5 (CC1), R6.1

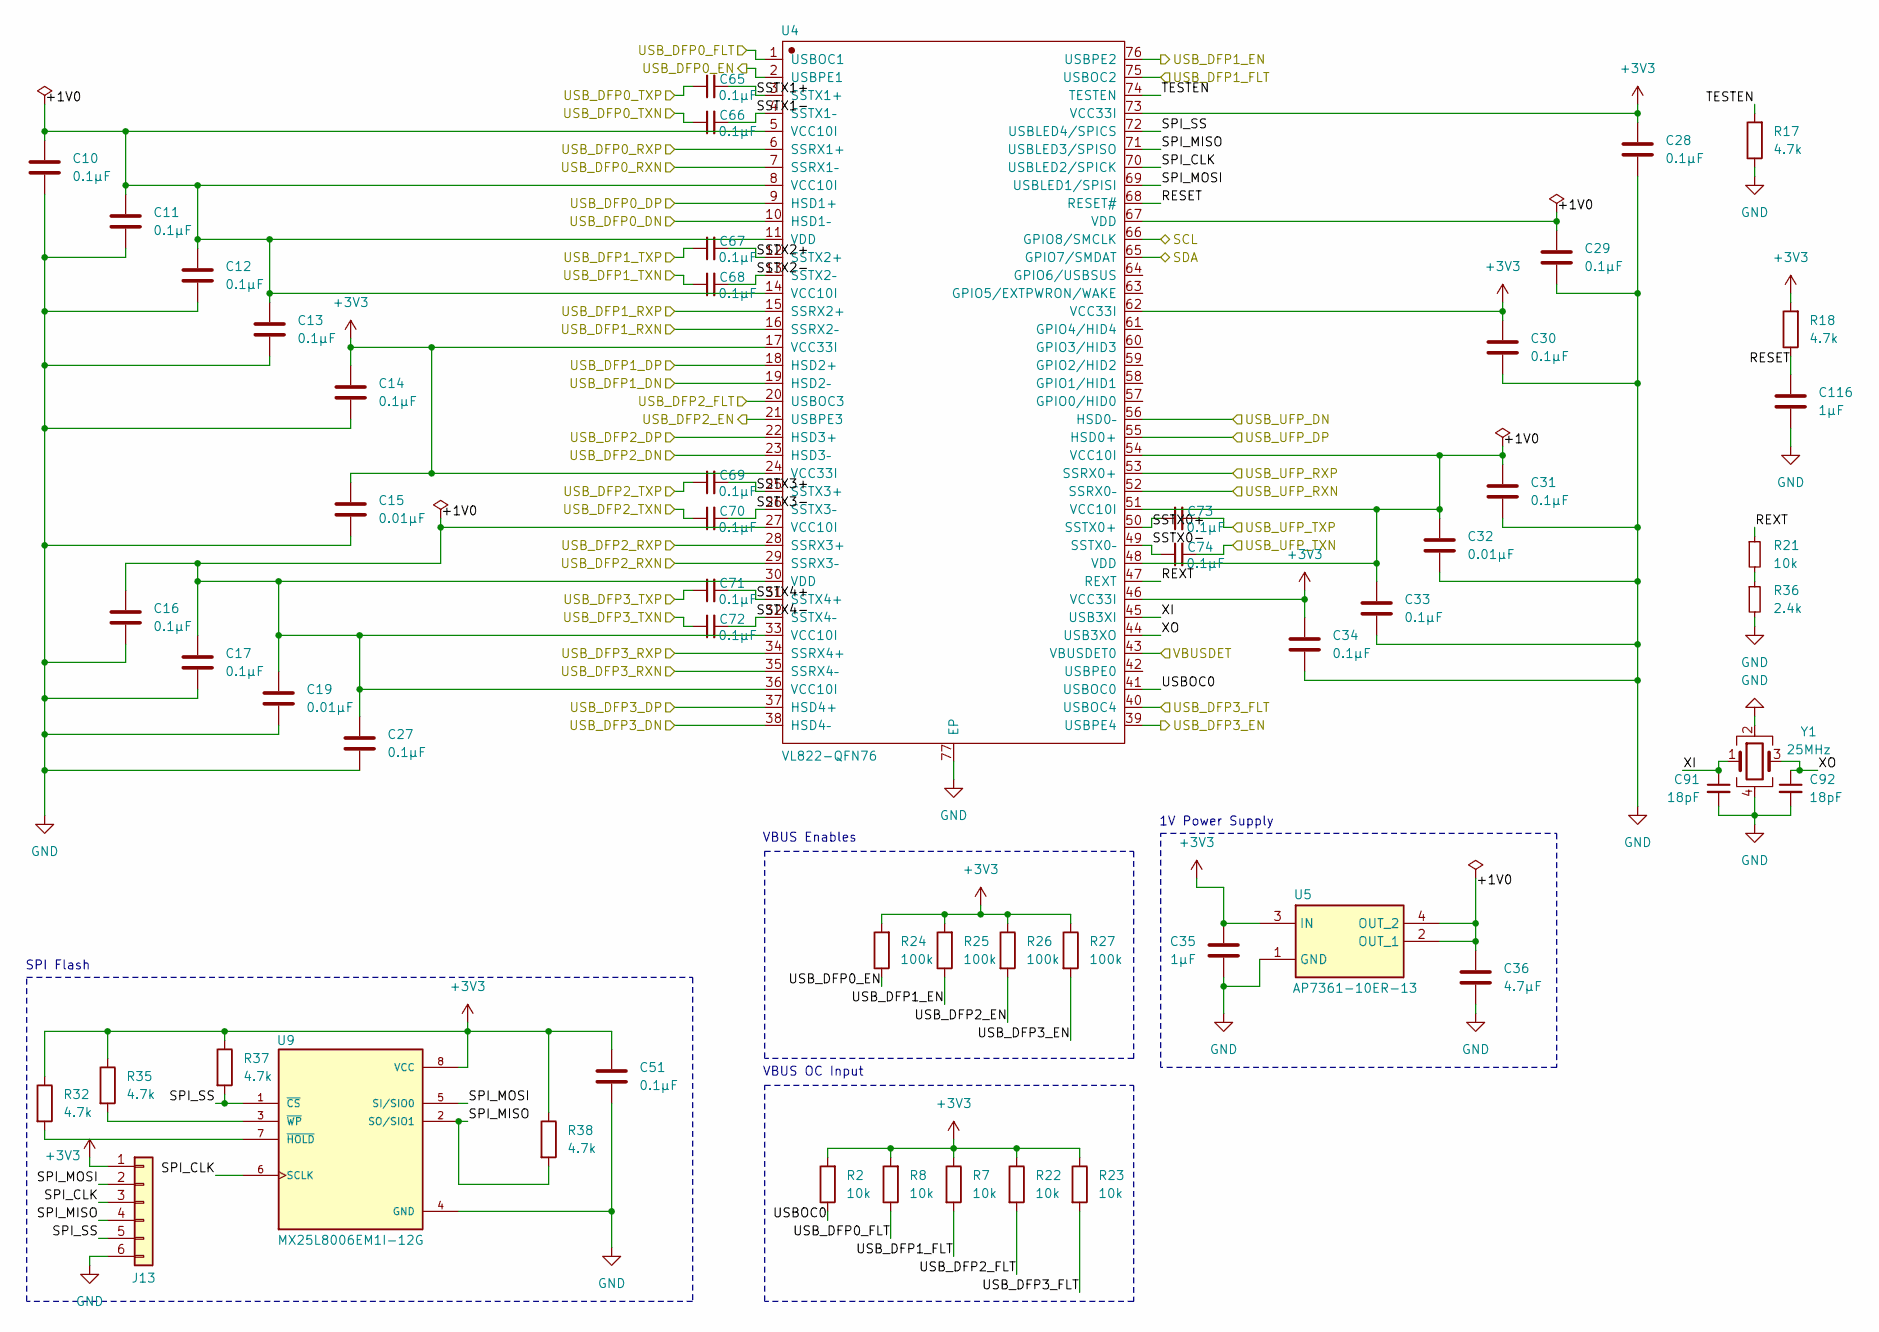
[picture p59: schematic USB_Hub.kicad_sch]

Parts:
C10, C11, C12, C13, C14, C16, C17, C27, C28, C29, C30, C31, C33, C34, C51, C65, C66, C67, C68, C69, C70, C71, C72, C73, C74: 0.1µF; C_0402_1005Metric; Part_Number CL05B104KB54PNC; LCSC C307331
C15, C19, C32: 0.01µF; C_0402_1005Metric; Part_Number CL05B103KB5NNNC; LCSC C15195
C35: 1µF; C_0603_1608Metric; Part_Number CL10A105KB8NNNC; LCSC C15849
C36: 4.7μF; C_0603_1608Metric; Part_Number CL10A475KO8NNNC; LCSC C19666
C91, C92: 18pF; C_0603_1608Metric; Part_Number CL10C180JB8NNNC; LCSC C1647
C116: 1µF; C_0402_1005Metric; Part_Number CL05A105KA5NQNC; LCSC C52923
J13: Conn_01x06; PinHeader_1x06_P2.54mm_Vertical; Part_Number 2.54-1*6; LCSC C5156615
R2, R7, R8, R21, R22, R23: 10k; R_0402_1005Metric; Part_Number 0402WGF1002TCE; LCSC C25744
R17, R18, R32, R35, R37, R38: 4.7k; R_0402_1005Metric; Part_Number 0402WGF4701TCE; LCSC C25900
R24, R25, R26, R27: 100k; R_0402_1005Metric; Part_Number 0402WGF1003TCE; LCSC C25741
R36: 2.4k; R_0402_1005Metric; Part_Number 0402WGF2401TCE; LCSC C25882
U4: VL822-QFN76; Part_Number VL822-QFN76; LCSC C2841047
U5: AP7361-10ER-13; SOT230P700X180-4N; Part_Number AP7361-10ER-13; LCSC C460389
U9: MX25L8006EM1I-12G; PARTREV 1.6; LCSC C106262
Y1: 25MHz; Crystal_SMD_3225-4Pin_3.2x2.5mm; Part_Number X322525MOB4SI; LCSC C9006

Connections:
+3V3: C14.1, C15.1, C28.1, C30.1, C34.1, C35.1, C51.1, J13.1, R2.2, R7.1, R8.2, R18.2, R22.1, R23.1, R24.2, R25.2, R26.1, R27.1, R32.1, R35.1, R37.1, R38.1, U4.17 (VCC33I), U4.24 (VCC33I), U4.46 (VCC33I), U4.62 (VCC33I), U4.73 (VCC33I), U5.3 (IN), U9.8 (VCC); also elsewhere on the board
/USB Hub/+1V0: C10.1, C11.1, C12.1, C13.1, C16.1, C17.1, C19.1, C27.1, C29.1, C31.1, C32.1, C33.1, C36.1, U4.5 (VCC10I), U4.8 (VCC10I), U4.11 (VDD), U4.14 (VCC10I), U4.27 (VCC10I), U4.30 (VDD), U4.33 (VCC10I), U4.36 (VCC10I), U4.48 (VDD), U4.51 (VCC10I), U4.54 (VCC10I), U4.67 (VDD), U5.2 (OUT_1), U5.4 (OUT_2)
/USB Hub/CS: J13.5, R37.2, U4.72 (USBLED4/SPICS), U9.1 (~CS); also elsewhere on the board
/USB Hub/MISO: J13.4, R38.2, U4.71 (USBLED3/SPISO), U9.2 (SO/SIO1); also elsewhere on the board
/USB Hub/MOSI: J13.2, U4.69 (USBLED1/SPISI), U9.5 (SI/SIO0); also elsewhere on the board
/USB Hub/RESET: C116.1, R18.1, U4.68 (RESET#)
/USB Hub/REXT: R21.1, U4.47 (REXT)
/USB Hub/SCL: U4.66 (GPIO8/SMCLK); also elsewhere on the board
/USB Hub/SCLK: J13.3, U4.70 (USBLED2/SPICK), U9.6 (SCLK); also elsewhere on the board
/USB Hub/SDA: U4.65 (GPIO7/SMDAT); also elsewhere on the board
/USB Hub/SSTX0+: C73.1, U4.50 (SSTX0+)
/USB Hub/SSTX0-: C74.1, U4.49 (SSTX0–)
/USB Hub/SSTX1+: C65.2, U4.3 (SSTX1+)
/USB Hub/SSTX1-: C66.2, U4.4 (SSTX1–)
/USB Hub/SSTX2+: C67.2, U4.12 (SSTX2+)
/USB Hub/SSTX2-: C68.2, U4.13 (SSTX2–)
/USB Hub/SSTX3+: C69.2, U4.25 (SSTX3+)
/USB Hub/SSTX3-: C70.2, U4.26 (SSTX3–)
/USB Hub/SSTX4+: C71.2, U4.31 (SSTX4+)
/USB Hub/SSTX4-: C72.2, U4.32 (SSTX4–)
/USB Hub/TESTEN: R17.2, U4.74 (TESTEN)
/USB Hub/USBOC0: R2.1, U4.41 (USBOC0)
/USB Hub/USB_DFP0_EN: R24.1, U4.2 (USBPE1)
/USB Hub/USB_DFP0_FLT: R8.1, U4.1 (USBOC1)
/USB Hub/USB_DFP1_EN: R25.1, U4.76 (USBPE2)
/USB Hub/USB_DFP1_FLT: R7.2, U4.75 (USBOC2)
/USB Hub/USB_DFP2_EN: R26.2, U4.21 (USBPE3)
/USB Hub/USB_DFP2_FLT: R22.2, U4.20 (USBOC3)
/USB Hub/USB_DFP3_EN: R27.2, U4.39 (USBPE4)
/USB Hub/USB_DFP3_FLT: R23.2, U4.40 (USBOC4)
/USB Hub/USB_UFP_DN: U4.56 (HSD0–); also elsewhere on the board
/USB Hub/USB_UFP_DP: U4.55 (HSD0+); also elsewhere on the board
/USB Hub/USB_UFP_RXN: U4.52 (SSRX0–); also elsewhere on the board
/USB Hub/USB_UFP_RXP: U4.53 (SSRX0+); also elsewhere on the board
/USB Hub/USB_UFP_TXN: C74.2; also elsewhere on the board
/USB Hub/USB_UFP_TXP: C73.2; also elsewhere on the board
/USB Hub/VBUSDET: U4.43 (VBUSDET0); also elsewhere on the board
/USB Hub/XI: C91.1, U4.45 (USB3XI), Y1.1
/USB Hub/XO: C92.1, U4.44 (USB3XO), Y1.3
/USB_DFP0_D1N: U4.10 (HSD1–); also elsewhere on the board
/USB_DFP0_D1P: U4.9 (HSD1+); also elsewhere on the board
/USB_DFP0_D2N: U4.19 (HSD2–); also elsewhere on the board
/USB_DFP0_D2P: U4.18 (HSD2+); also elsewhere on the board
/USB_DFP0_RX1N: U4.7 (SSRX1–); also elsewhere on the board
/USB_DFP0_RX1P: U4.6 (SSRX1+); also elsewhere on the board
/USB_DFP0_RX2N: U4.15 (SSRX2+); also elsewhere on the board
/USB_DFP0_RX2P: U4.16 (SSRX2–); also elsewhere on the board
/USB_DFP0_TX1N: C66.1; also elsewhere on the board
/USB_DFP0_TX1P: C65.1; also elsewhere on the board
/USB_DFP0_TX2N: C67.1; also elsewhere on the board
/USB_DFP0_TX2P: C68.1; also elsewhere on the board
/USB_DFP1_D1N: U4.23 (HSD3–); also elsewhere on the board
/USB_DFP1_D1P: U4.22 (HSD3+); also elsewhere on the board
/USB_DFP1_D2N: U4.38 (HSD4–); also elsewhere on the board
/USB_DFP1_D2P: U4.37 (HSD4+); also elsewhere on the board
/USB_DFP1_RX1N: U4.29 (SSRX3–); also elsewhere on the board
/USB_DFP1_RX1P: U4.28 (SSRX3+); also elsewhere on the board
/USB_DFP1_RX2N: U4.34 (SSRX4+); also elsewhere on the board
/USB_DFP1_RX2P: U4.35 (SSRX4–); also elsewhere on the board
/USB_DFP1_TX1N: C70.1; also elsewhere on the board
/USB_DFP1_TX1P: C69.1; also elsewhere on the board
/USB_DFP1_TX2N: C71.1; also elsewhere on the board
/USB_DFP1_TX2P: C72.1; also elsewhere on the board
GND: C10.2, C11.2, C12.2, C13.2, C14.2, C15.2, C16.2, C17.2, C19.2, C27.2, C28.2, C29.2, C30.2, C31.2, C32.2, C33.2, C34.2, C35.2, C36.2, C51.2, C91.2, C92.2, C116.2, J13.6, R17.1, R36.2, U4.77 (EP), U5.1 (GND), U9.4 (GND), Y1.2, Y1.4; also elsewhere on the board
unnamed: R21.2, R36.1
unnamed: R32.2, U9.7 (~HOLD)
unnamed: R35.2, U9.3 (~WP)

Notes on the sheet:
VBUS Enables
1V Power Supply
VBUS OC Input
SPI Flash

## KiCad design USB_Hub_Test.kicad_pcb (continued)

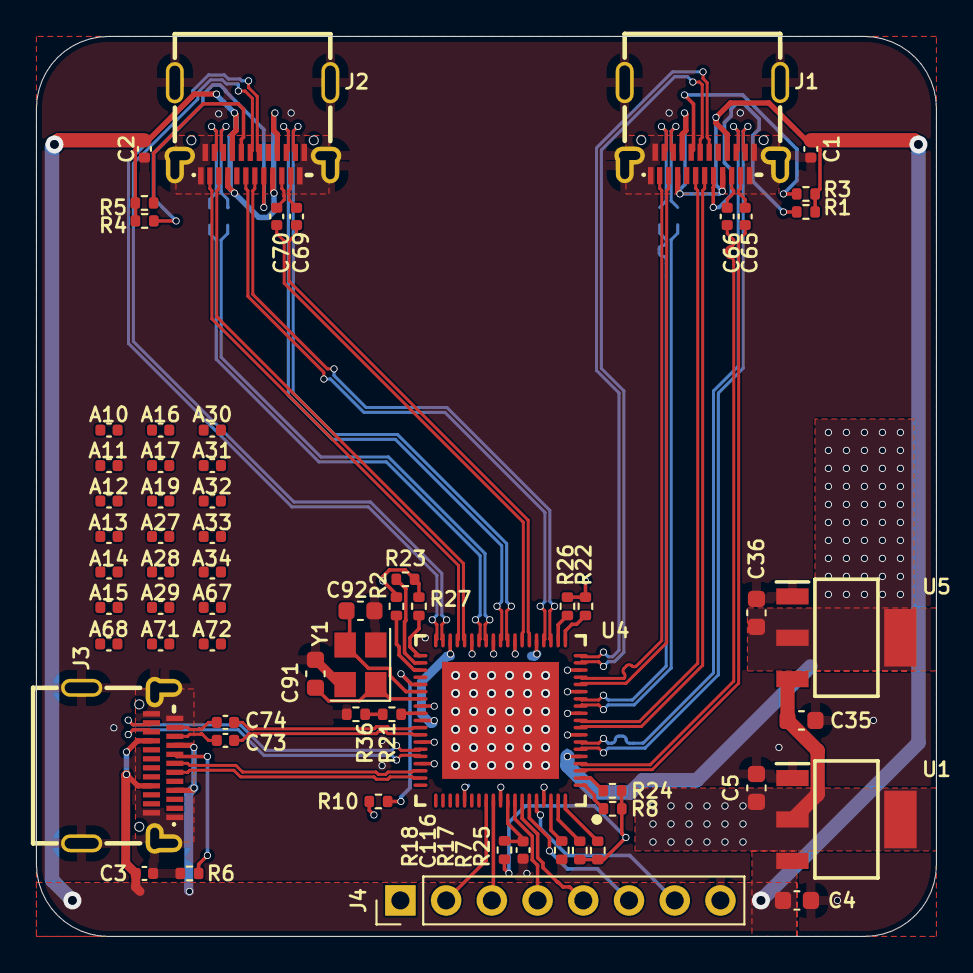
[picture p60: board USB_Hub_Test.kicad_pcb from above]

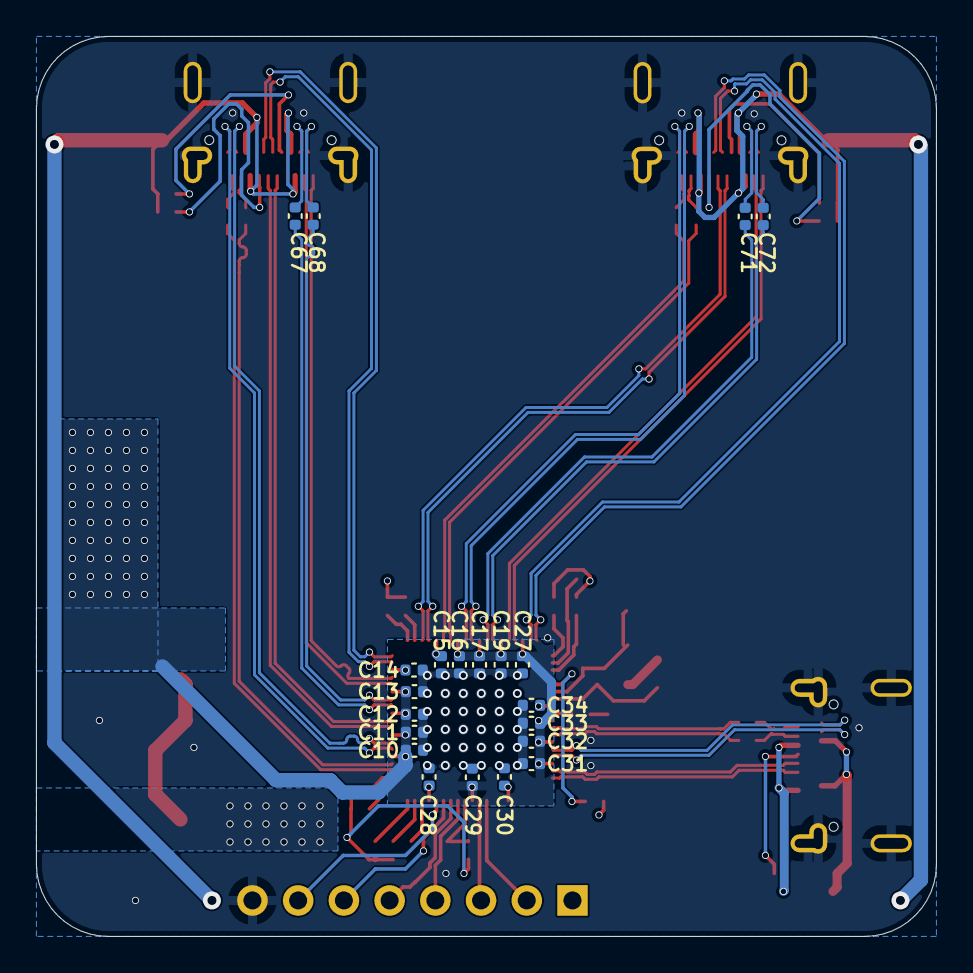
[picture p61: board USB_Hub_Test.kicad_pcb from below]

Board: 4 copper layers, 50.0 x 50.0 mm, 85 parts (21 on the bottom side), 71 nets.

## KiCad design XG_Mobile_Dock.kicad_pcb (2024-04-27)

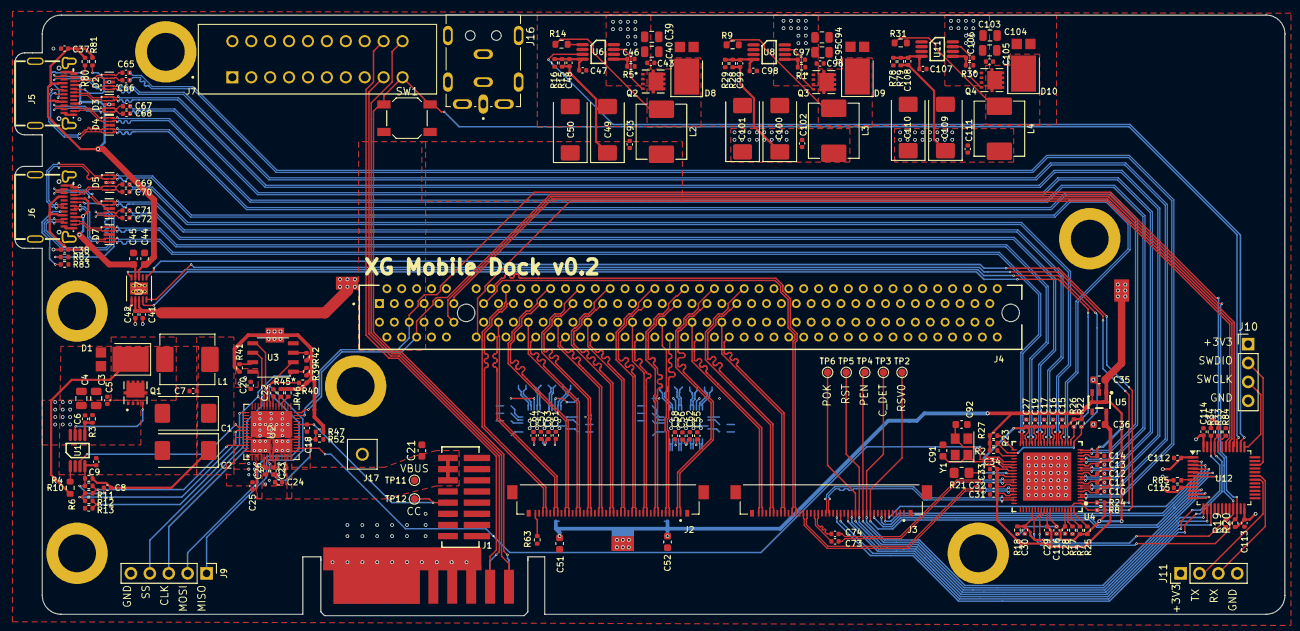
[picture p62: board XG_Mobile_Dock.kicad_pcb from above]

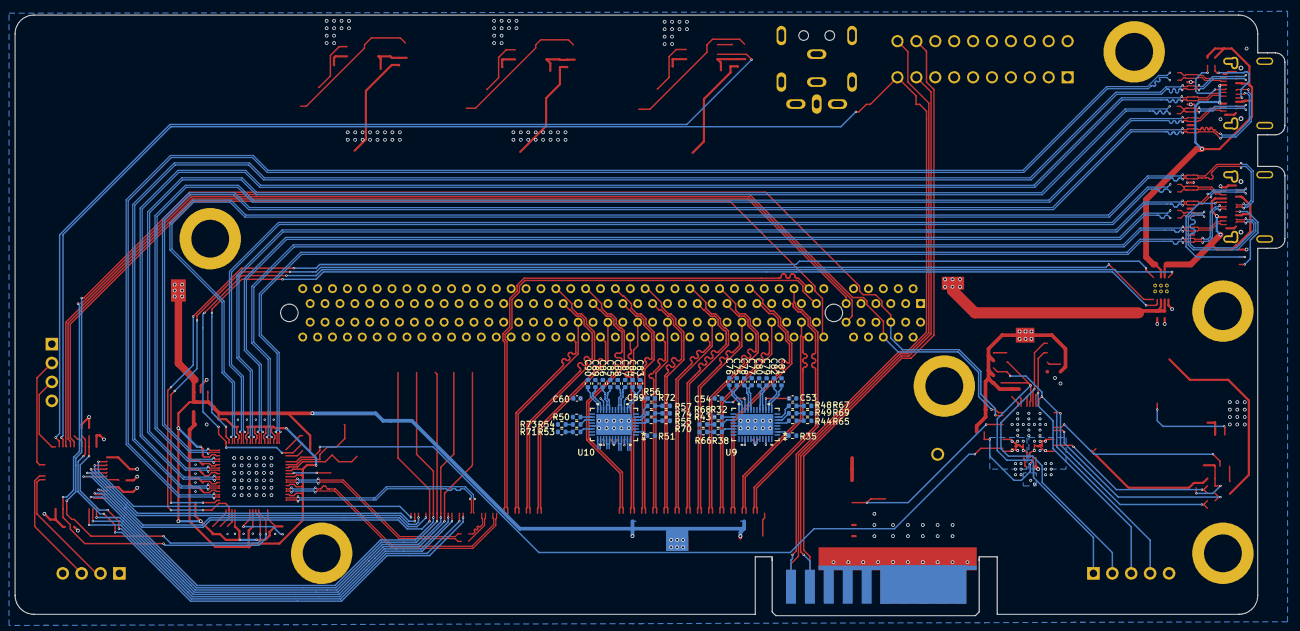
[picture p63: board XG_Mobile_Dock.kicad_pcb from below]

Board: 4 copper layers, 170.6 x 80.7 mm, 242 parts (46 on the bottom side), 215 nets.

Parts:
C1, C2, C49, C50, C100, C101, C109, C110: 47µF; CP_EIA-7343-43_Kemet-X
C3, C4, C39, C40, C94, C95, C103, C104: 22µF; C_0805_2012Metric
C5, C7, C10, C11, C12, C13, C14, C16, C17, C20, C27, C28, C29, C30, C31, C33, C34, C43, C65, C66, C67, C68, C69, C70, C71, C72, C73, C74, C93, C96, C102, C105, C111, C112, C113, C114: 0.1µF; C_0402_1005Metric
C6, C9, C46, C47, C97, C98, C106, C107: 1000pF; C_0402_1005Metric
C8, C48, C99, C108: 100pF; C_0402_1005Metric
C15, C19, C32: 0.01µF; C_0402_1005Metric
C18: 220pF; C_0402_1005Metric
C21, C35, C51, C52: 1µF; C_0603_1608Metric
C22, C23, C24, C25, C26, C115: 10µF; C_0402_1005Metric
C36: 4.7μF; C_0603_1608Metric
C37, C38, C41, C42, C53, C54, C55, C56, C57, C58, C59, C60, C61, C62, C63, C64: 0.1μF; C_0402_1005Metric
C44, C45: 22μF; C_0603_1608Metric
C75, C76, C77, C78, C79, C80, C81, C82, C83, C84, C85, C86, C87, C88, C89, C90: 220nF; C_0402_1005Metric
C91, C92: 22pF; C_0603_1608Metric
C116: 1µF; C_0402_1005Metric
D1, D8, D9, D10: PDS1040L-13; D_PowerDI-5
D2, D3, D4, D5, D6, D7: H5VU25U; AZ1045-04F
J1: 5-1775443-8
J2, J3: 20455-040E-76
J4: 3-2362375-4; SAMTEC_PCIE-164-02-F-D-TH-TR
J5, J6: USB_C_Receptacle; USB-C-SMD_TYPE-C-24P-QT
J7: Conn_02x10_Odd_Even; 5-5530843-0
J8: Conn_02x10_Odd_Even; 20P_Slot_Power
J9: Conn_01x05; PinHeader_1x05_P2.54mm_Vertical
J10: SWD; PinHeader_1x04_P2.54mm_Vertical
J11: UART; PinHeader_1x04_P2.54mm_Vertical
J16: 19V 5A DC; CUI_PJ-096H
J17: 8730; KEYSTONE_8730
L1, L2, L3, L4: 10µH; L_Abracon_ASPI-0630LR
Q1, Q2, Q3, Q4: AON7403; TRANS_AON7403
R1, R3, R30, R38, R43, R44, R48, R49, R53, R54, R55, R56, R57: 47k; R_0402_1005Metric
R2, R7, R8, R22, R23, R33, R34, R47, R63, R85: 10k; R_0402_1005Metric
R4: 49.9k; R_0402_1005Metric
R5: 68k; R_0402_1005Metric
R6, R9, R14, R31: 270; R_0603_1608Metric
R10, R12: 3.3k; R_0402_1005Metric
R11: 1.2k; R_0402_1005Metric
R13: 8.2k; R_0402_1005Metric
R15: 33k; R_0402_1005Metric
R16, R29: 3.9k; R_0402_1005Metric
R17, R18, R19, R20, R32, R39, R40, R41, R42, R45, R46, R50: 4.7k; R_0402_1005Metric
R21: 12.4k; R_0805_2012Metric_Pad1.20x1.40mm_HandSolder
R24, R25, R26, R27, R52: 100k; R_0402_1005Metric
R28, R65, R66, R67, R68, R69, R70, R71, R72, R73, R74, R79: 12k; R_0402_1005Metric
R35, R51, R84: 1k; R_0402_1005Metric
R78: 20k; R_0402_1005Metric
R80, R81, R82, R83: 22k; R_0402_1005Metric
SW1: SW_Push; SW_SPST_SKQG_WithStem
TP2, TP3, TP4, TP5, TP6, TP11, TP12: TestPoint_Small; TestPoint_Pad_D1.0mm
U1, U6, U8, U11: LM3489QMM/NOPB; LM3489QMM-NOPB
U2: TPS65987DDHRSHR
U3: MX25L8006EM1I-12G
U4: VL822-QFN76
U5: AP7331-10WG-7
U7: TPS2003CDRCR; DRC10_1P65X2P40_TEX
U9, U10: SN75LVPE4410RNQR
U12: STM32F030C8Tx; LQFP-48_7x7mm_P0.5mm
Y1: 25MHz; Crystal_SMD_3225-4Pin_3.2x2.5mm

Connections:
+3V3: C14.1, C15.1, C20.1, C26.1, C28.1, C30.1, C35.1, C51.1, C52.1, C55.1, C56.1, C57.1, C58.1, C61.1, C62.1, C63.1, C64.1, C108.1, C109.1, C110.1, C111.1, C112.1, C113.1, C114.1, C115.1, J3.1 (+3.3V), J3.2 (+3.3V), J3.3 (+3.3V), J3.4 (+3.3V), J4.A9, J4.A10, J4.B8, J4.B10, J10.1, J11.1, L4.2, R2.2, R7.1, R8.2, R18.2, R19.1, R20.1, R22.1, R23.1, R24.2, R25.2, R26.1, R27.1, R32.1, R33.1, R34.1, R39.1, R40.1, R41.1, R42.1, R45.2, R46.2, R47.1, R50.1, R78.1, R85.2, U2.5 (VIN_3V3), U3.8 (VCC), U4.17 (VCC33I), U4.24 (VCC33I), U4.62 (VCC33I), U4.73 (VCC33I), U5.1 (IN), U5.3 (EN), U9.31 (VDD), U9.34 (VDD), U9.35 (VDD), U9.38 (VDD), U10.31 (VDD), U10.34 (VDD), U10.35 (VDD), U10.38 (VDD), U12.1 (VDD), U12.9 (VDDA), U12.24 (VDD), U12.48 (VDD)
+5V: C41.1, C42.1, C99.1, C100.1, C101.1, C102.1, L3.2, R28.1, U7.2 (IN), U7.3 (IN)
+12V: C48.1, C49.1, C50.1, C93.1, J4.A2, J4.A3, J4.B1, J4.B2, J4.B3, L2.2, R15.1
+20V: C3.1, C4.1, C5.1, C6.1, C39.1, C40.1, C43.1, C46.1, C94.1, C95.1, C96.1, C97.1, C103.1, C104.1, C105.1, C106.1, J7.2, J7.4, J7.6, J7.8, J7.10, J7.12, J7.14, J7.16, J8.2, J8.4, J8.6, J8.8, J8.10, J8.12, J8.14, J8.16, J16.3, J16.4, Q1.1, Q2.1, Q3.1, Q4.1, R1.1, R3.1, R5.1, R30.1, U1.8 (VIN), U6.8 (VIN), U8.8 (VIN), U11.8 (VIN)
/12V_EN: U6.3 (EN), U12.38 (PA15)
/AC_LOSS: J3.15 (P_AC_LOSS), U12.14 (PA4)
/CLKN: J3.30 (PCIE_CLKN), J4.A14
/CLKP: J3.31 (PCIE_CLKP), J4.A13
/CLKREQ#: J4.B12, U12.42 (PB6)
/CON_DET: J3.11 (CON_DET), TP3.1, U12.10 (PA0)
/C_DN: J3.21 (USB_DM), U4.56 (HSD0–)
/C_DP: J3.22 (USB_DP), U4.55 (HSD0+)
/C_RXN: J3.27 (USB_TXN), U4.52 (SSRX0–)
/C_RXP: J3.28 (USB_TXP), U4.53 (SSRX0+)
/C_TXN: C74.2, J3.24 (USB_RXN)
/C_TXP: C73.2, J3.25 (USB_RXP)
/DET: J2.40 (CON_DET_TOWER#), R63.1
/LED_RED#: J3.7 (LED_R), U12.4 (PC15)
/LED_WHITE#: J3.6 (LED_W), U12.3 (PC14)
/LOCK_DET: J3.9 (CON_SW1_DET), U12.5 (PF0)
/LOCK_SW: J3.5 (LOCK_SW), U12.2 (PC13)
/MCU/RX: J11.3, U12.31 (PA10)
/MCU/SWCLK: J10.3, U12.37 (PA14)
/MCU/SWDIO: J10.2, U12.34 (PA13)
/MCU/TX: J11.2, U12.30 (PA9)
/MCU_IRQ#: J3.16 (MCU_IRQ#), U12.15 (PA5)
/PCIe Redriver/EN_SMB_0: R35.2, U9.2 (EN_SMB)
/PCIe Redriver/EN_SMB_1: R51.2, U10.2 (EN_SMB)
/PCIe Redriver/EQ0_ADDR0_0: R48.1, U9.7 (EQ0_ADDR0)
/PCIe Redriver/EQ0_ADDR0_1: R56.1, U10.7 (EQ0_ADDR0)
/PCIe Redriver/EQ1_ADDR1_0: R49.1, U9.6 (EQ1_ADDR1)
/PCIe Redriver/EQ1_ADDR1_1: R57.1, U10.6 (EQ1_ADDR1)
/PCIe Redriver/GAIN_0: R44.1, U9.5 (GAIN)
/PCIe Redriver/GAIN_1: R55.1, U10.5 (GAIN)
/PCIe Redriver/RX_DET_0: R38.1, U9.26 (RX_DET)
/PCIe Redriver/RX_DET_1: R53.1, U10.26 (RX_DET)
/PCIe Redriver/SCL: U9.3 (SCL), U10.3 (SCL)
/PCIe Redriver/SDA: U9.4 (SDA), U10.4 (SDA)
/PCIe Redriver/TX0CN: C89.2, U10.19 (TX0N)
/PCIe Redriver/TX0CP: C90.2, U10.20 (TX0P)
/PCIe Redriver/TX1CN: C85.2, U10.16 (TX1N)
/PCIe Redriver/TX1CP: C86.2, U10.17 (TX1P)
/PCIe Redriver/TX2CN: C87.2, U10.12 (TX2N)
/PCIe Redriver/TX2CP: C88.2, U10.13 (TX2P)
/PCIe Redriver/TX3CN: C83.2, U10.9 (TX3N)
/PCIe Redriver/TX3CP: C84.2, U10.10 (TX3P)
/PCIe Redriver/TX4CN: C75.2, U9.19 (TX0N)
/PCIe Redriver/TX4CP: C76.2, U9.20 (TX0P)
/PCIe Redriver/TX5CN: C77.2, U9.16 (TX1N)
/PCIe Redriver/TX5CP: C78.2, U9.17 (TX1P)
/PCIe Redriver/TX6CN: C79.2, U9.12 (TX2N)
/PCIe Redriver/TX6CP: C80.2, U9.13 (TX2P)
/PCIe Redriver/TX7CN: C81.2, U9.9 (TX3N)
/PCIe Redriver/TX7CP: C82.2, U9.10 (TX3P)
/PCIe Redriver/VOD_0: R43.1, U9.23 (VOD)
/PCIe Redriver/VOD_1: R54.1, U10.23 (VOD)
/PERST#: J4.A11, U12.41 (PB5)
/PWREN#: J3.12 (PWR_EN#), TP4.1, U12.11 (PA1)
/PWROK: J3.14 (PWROK), TP6.1, U12.13 (PA3)
/PWR_SW: J7.19, J8.19, SW1.1, U12.39 (PB3)
/RST#: J3.13 (RST#), TP5.1, U12.12 (PA2)
/RSV0: J3.10, TP2.1, U12.6 (PF1)
/RX0N: J2.37 (PCIE_TXN0), J4.A17
/RX0P: J2.38 (PCIE_TXP0), J4.A16
/RX1N: J2.31 (PCIE_TXN1), J4.A21
/RX1P: J2.32 (PCIE_TXP1), J4.A22
/RX2N: J2.25 (PCIE_TXN2), J4.A25
/RX2P: J2.26 (PCIE_TXP2), J4.A26
/RX3N: J2.19 (PCIE_TXN3), J4.A29
/RX3P: J2.20 (PCIE_TXP3), J4.A30
/RX4N: J2.13 (PCIE_TXN4), J4.A35
/RX4P: J2.14 (PCIE_TXP4), J4.A36
/RX5N: J2.7 (PCIE_TXN5), J4.A39
/RX5P: J2.8 (PCIE_TXP5), J4.A40
/RX6N: J2.1 (PCIE_TXN6), J4.A43
/RX6P: J2.2 (PCIE_TXP6), J4.A44
/RX7N: J3.36 (PCIE_TXN7), J4.A47
/RX7P: J3.37 (PCIE_TXP7), J4.A48
/SCL1: J3.19 (SMB1_CLK), R33.2, U12.45 (PB8)
/SCL2: J4.B5, R19.2, U2.27 (I2C1_SCL), U4.66 (GPIO8/SMCLK), U12.21 (PB10)
/SDA1: J3.18 (SMB1_DAT), R34.2, U12.46 (PB9)
/SDA2: J4.B6, R20.2, U2.28 (I2C1_SDA), U4.65 (GPIO7/SMDAT), U12.22 (PB11)
/TX0N: J2.34 (PCIE_RXN0), J4.B15
/TX0P: J2.35 (PCIE_RXP0), J4.B14
/TX1N: J2.28 (PCIE_RXN1), J4.B20
/TX1P: J2.29 (PCIE_RXP1), J4.B19
/TX2N: J2.22 (PCIE_RXN2), J4.B24
/TX2P: J2.23 (PCIE_RXP2), J4.B23
/TX3N: J2.16 (PCIE_RXN3), J4.B28
/TX3P: J2.17 (PCIE_RXP3), J4.B27
/TX4N: J2.10 (PCIE_RXN4), J4.B34
/TX4P: J2.11 (PCIE_RXP4), J4.B33
/TX5N: J2.4 (PCIE_RXN5), J4.B38
/TX5P: J2.5 (PCIE_RXP5), J4.B37
/TX6N: J3.39 (PCIE_RXN6), J4.B42
/TX6P: J3.40 (PCIE_RXP6), J4.B41
/TX7N: J3.33 (PCIE_RXN7), J4.B46
/TX7P: J3.34 (PCIE_RXP7), J4.B45
/USB C DFPs/USB_DFP0_D1N: D3.2 (I/O_2), D3.9 (NC), J5.A7 (D-), U4.10 (HSD1–)
/USB C DFPs/USB_DFP0_D1P: D3.1 (I/O_1), D3.10 (NC), J5.A6 (D+), U4.9 (HSD1+)
/USB C DFPs/USB_DFP0_D2N: D4.5 (I/O_4), D4.6 (NC), J5.B7 (D-), U4.19 (HSD2–)
/USB C DFPs/USB_DFP0_D2P: D4.4 (I/O_3), D4.7 (NC), J5.B6 (D+), U4.18 (HSD2+)
/USB C DFPs/USB_DFP0_RX1N: D2.5 (I/O_4), D2.6 (NC), J5.B10 (RX1-), U4.7 (SSRX1–)
/USB C DFPs/USB_DFP0_RX1P: D2.4 (I/O_3), D2.7 (NC), J5.B11 (RX1+), U4.6 (SSRX1+)
/USB C DFPs/USB_DFP0_RX2N: D4.1 (I/O_1), D4.10 (NC), J5.A10 (RX2-), U4.15 (SSRX2+)
/USB C DFPs/USB_DFP0_RX2P: D4.2 (I/O_2), D4.9 (NC), J5.A11 (RX2+), U4.16 (SSRX2–)
/USB C DFPs/USB_DFP0_TX1N: C66.1, D2.2 (I/O_2), D2.9 (NC), J5.A3 (TX1-)
/USB C DFPs/USB_DFP0_TX1P: C65.1, D2.1 (I/O_1), D2.10 (NC), J5.A2 (TX1+)
/USB C DFPs/USB_DFP0_TX2N: C67.1, D3.4 (I/O_3), D3.7 (NC), J5.B3 (TX2-)
/USB C DFPs/USB_DFP0_TX2P: C68.1, D3.5 (I/O_4), D3.6 (NC), J5.B2 (TX2+)
/USB C DFPs/USB_DFP0_VBUS: C37.1, C44.1, J5.A4 (VBUS), J5.A9 (VBUS), J5.B4 (VBUS), J5.B9 (VBUS), R80.2, R81.1, U7.8 (OUT2)
/USB C DFPs/USB_DFP1_D1N: D7.5 (I/O_4), D7.6 (NC), J6.A7 (D-), U4.38 (HSD4–)
/USB C DFPs/USB_DFP1_D1P: D7.4 (I/O_3), D7.7 (NC), J6.A6 (D+), U4.37 (HSD4+)
/USB C DFPs/USB_DFP1_D2N: D5.2 (I/O_2), D5.9 (NC), J6.B7 (D-), U4.23 (HSD3–)
/USB C DFPs/USB_DFP1_D2P: D5.1 (I/O_1), D5.10 (NC), J6.B6 (D+), U4.22 (HSD3+)
/USB C DFPs/USB_DFP1_RX1N: D6.2 (I/O_2), D6.9 (NC), J6.B10 (RX1-), U4.29 (SSRX3–)
/USB C DFPs/USB_DFP1_RX1P: D6.1 (I/O_1), D6.10 (NC), J6.B11 (RX1+), U4.28 (SSRX3+)
/USB C DFPs/USB_DFP1_RX2N: D7.1 (I/O_1), D7.10 (NC), J6.A10 (RX2-), U4.34 (SSRX4+)
/USB C DFPs/USB_DFP1_RX2P: D7.2 (I/O_2), D7.9 (NC), J6.A11 (RX2+), U4.35 (SSRX4–)
/USB C DFPs/USB_DFP1_TX1N: C70.1, D5.5 (I/O_4), D5.6 (NC), J6.A3 (TX1-)
/USB C DFPs/USB_DFP1_TX1P: C69.1, D5.4 (I/O_3), D5.7 (NC), J6.A2 (TX1+)
/USB C DFPs/USB_DFP1_TX2N: C71.1, D6.4 (I/O_3), D6.7 (NC), J6.B3 (TX2-)
/USB C DFPs/USB_DFP1_TX2P: C72.1, D6.5 (I/O_4), D6.6 (NC), J6.B2 (TX2+)
/USB C DFPs/USB_DFP1_VBUS: C38.1, C45.1, J6.A4 (VBUS), J6.A9 (VBUS), J6.B4 (VBUS), J6.B9 (VBUS), R82.2, R83.1, U7.9 (OUT1)
/USB Hub/+1V0: C10.1, C11.1, C12.1, C13.1, C16.1, C17.1, C19.1, C27.1, C29.1, C31.1, C32.1, C33.1, C34.1, C36.1, U4.5 (VCC10I), U4.8 (VCC10I), U4.11 (VDD), U4.14 (VCC10I), U4.27 (VCC10I), U4.30 (VDD), U4.33 (VCC10I), U4.36 (VCC10I), U4.46 (VCC33I), U4.48 (VDD), U4.51 (VCC10I), U4.54 (VCC10I), U4.67 (VDD), U5.5 (OUT)
/USB Hub/RESET: C116.1, R18.1, U4.68 (RESET#)
/USB Hub/REXT: R21.1, U4.47 (REXT)
/USB Hub/SSTX0+: C73.1, U4.50 (SSTX0+)
/USB Hub/SSTX0-: C74.1, U4.49 (SSTX0–)
/USB Hub/SSTX1+: C65.2, U4.3 (SSTX1+)
/USB Hub/SSTX1-: C66.2, U4.4 (SSTX1–)
/USB Hub/SSTX2+: C67.2, U4.12 (SSTX2+)
/USB Hub/SSTX2-: C68.2, U4.13 (SSTX2–)
/USB Hub/SSTX3+: C69.2, U4.25 (SSTX3+)
/USB Hub/SSTX3-: C70.2, U4.26 (SSTX3–)
/USB Hub/SSTX4+: C71.2, U4.31 (SSTX4+)
/USB Hub/SSTX4-: C72.2, U4.32 (SSTX4–)
/USB Hub/TESTEN: R17.2, U4.74 (TESTEN)
/USB Hub/USBOC0: R2.1, U4.41 (USBOC0)
/USB Hub/USB_DFP0_EN: R24.1, U4.2 (USBPE1), U7.5 (EN2)
/USB Hub/USB_DFP0_FLT: R7.2, R8.1, U4.1 (USBOC1), U4.75 (USBOC2), U7.6 (*FLT2)
/USB Hub/USB_DFP1_EN: R25.1, U4.76 (USBPE2)
/USB Hub/USB_DFP2_EN: R26.2, U4.21 (USBPE3), U7.4 (EN1)
/USB Hub/USB_DFP2_FLT: R22.2, R23.2, U4.20 (USBOC3), U4.40 (USBOC4), U7.10 (*FLT1)
/USB Hub/USB_DFP3_EN: R27.2, U4.39 (USBPE4)
/USB Hub/VBUSDET: U2.16 (GPIO0), U4.43 (VBUSDET0)
/USB Hub/XI: C91.1, U4.45 (USB3XI), Y1.1
/USB Hub/XO: C92.1, U4.44 (USB3XO), Y1.3
/USB PD Charger/BOOT: R47.2, R52.1, U2.6 (ADCIN1)
/USB PD Charger/CC: C18.1, J1.13 (CC), TP12.1, U2.24 (C_CC1)
/USB PD Charger/DRAIN1: U2.8 (DRAIN1), U2.15 (DRAIN1), U2.19 (DRAIN1), U2.58 (DRAIN1)
/USB PD Charger/DRAIN2: U2.7 (DRAIN2), U2.52 (DRAIN2), U2.56 (DRAIN2), U2.57 (DRAIN2)
/USB PD Charger/LDO_3V3: C23.1, U2.9 (LDO_3V3)
/USB PD Charger/PDO_1: R12.2, R13.1, U2.43 (GPIO15)
/USB PD Charger/PDO_2: R11.2, R12.1, U2.49 (GPIO17)
/USB PD Charger/PDO_3: R10.2, R11.1, U2.54 (GPIO20)
/USB PD Charger/POWER_EN: U1.3 (EN), U2.48 (GPIO16)
/USB PD Charger/SPI_CLK: J9.3, U2.38 (SPI_CLK), U3.6 (SCLK)
/USB PD Charger/SPI_MISO: J9.1, R40.2, U2.36 (SPI_MISO), U3.2 (SO/SIO1)
/USB PD Charger/SPI_MOSI: J9.2, U2.37 (SPI_MOSI), U3.5 (SI/SIO0)
/USB PD Charger/SPI_SS: J9.4, R39.2, U2.39 (SPI_SS), U3.1 (~CS)
/USB PD Charger/VBUS: C21.1, J1.9 (VBUS), J1.10 (VBUS), J1.11 (VBUS), TP11.1, U2.3 (VBUS2), U2.4 (VBUS2), U2.13 (VBUS1), U2.14 (VBUS1)
/WAKE#: J4.B11, U12.40 (PB4)
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

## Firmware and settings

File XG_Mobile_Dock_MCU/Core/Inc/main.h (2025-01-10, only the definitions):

#define LOCK_SW_Pin GPIO_PIN_13
#define LOCK_SW_GPIO_Port GPIOC
#define LOCK_SW_EXTI_IRQn EXTI4_15_IRQn
#define LED_WHITE_Pin GPIO_PIN_14
#define LED_WHITE_GPIO_Port GPIOC
#define LED_RED_Pin GPIO_PIN_15
#define LED_RED_GPIO_Port GPIOC
#define LOCK_DET_Pin GPIO_PIN_0
#define LOCK_DET_GPIO_Port GPIOF
#define RSV0_Pin GPIO_PIN_1
#define RSV0_GPIO_Port GPIOF
#define CON_DET_Pin GPIO_PIN_0
#define CON_DET_GPIO_Port GPIOA
#define CON_DET_EXTI_IRQn EXTI0_1_IRQn
#define PWREN_Pin GPIO_PIN_1
#define PWREN_GPIO_Port GPIOA
#define PWREN_EXTI_IRQn EXTI0_1_IRQn
#define RST_Pin GPIO_PIN_2
#define RST_GPIO_Port GPIOA
#define RST_EXTI_IRQn EXTI2_3_IRQn
#define PWROK_Pin GPIO_PIN_3
#define PWROK_GPIO_Port GPIOA
#define AC_LOSS_Pin GPIO_PIN_4
#define AC_LOSS_GPIO_Port GPIOA
#define MCU_IRQ_Pin GPIO_PIN_5
#define MCU_IRQ_GPIO_Port GPIOA
#define HP_SHDN_Pin GPIO_PIN_2
#define HP_SHDN_GPIO_Port GPIOB
#define PWR_SW_Pin GPIO_PIN_12
#define PWR_SW_GPIO_Port GPIOB
#define SYS_ON_Pin GPIO_PIN_13
#define SYS_ON_GPIO_Port GPIOB
#define SYS_DET_Pin GPIO_PIN_14
#define SYS_DET_GPIO_Port GPIOB
#define FAN_ON_Pin GPIO_PIN_12
#define FAN_ON_GPIO_Port GPIOA
#define CASE_LED_Pin GPIO_PIN_7
#define CASE_LED_GPIO_Port GPIOF
#define PCI_12V_EN_Pin GPIO_PIN_15
#define PCI_12V_EN_GPIO_Port GPIOA
#define FAN_PWM_Pin GPIO_PIN_3
#define FAN_PWM_GPIO_Port GPIOB
#define WAKE_Pin GPIO_PIN_4
#define WAKE_GPIO_Port GPIOB
#define PERST_Pin GPIO_PIN_5
#define PERST_GPIO_Port GPIOB
#define CLKREQ_Pin GPIO_PIN_6
#define CLKREQ_GPIO_Port GPIOB

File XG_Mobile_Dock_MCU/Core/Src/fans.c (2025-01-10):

#include "main.h"
#include <stdio.h>
#include "stm32f0xx_ll_adc.h"

// built from https://aterlux.ru/article/ntcresistor-en

// Value when sum of ADC values is more than first value in table
#define TEMPERATURE_UNDER 0
// Value when sum of ADC values is less than last value in table 
#define TEMPERATURE_OVER 800
// Value corresponds to first entry in table
#define TEMPERATURE_TABLE_START 0
// Table step
#define TEMPERATURE_TABLE_STEP 10

// Type of each table item. If sum fits into 16 bits - uint16_t, else - uint32_t
typedef uint16_t temperature_table_entry_type;
// Type of table index. If table has more than 255 items, then uint16_t, else - uint8_t
typedef uint8_t temperature_table_index_type;
// Access method to table entry. Should correspond to temperature_table_entry_type
#define TEMPERATURE_TABLE_READ(i) termo_table[i]

/* Table of ADC sum value, corresponding to temperature. Starting from higher value to lower.
   Next parameters had been used to build table:
     R1(T1): 100kOhm(25°С)
     B25/50: 4250
     Scheme: A
     Ra: 100kOhm
     U0/Uref: 3.3V/3.3V
*/
static const temperature_table_entry_type termo_table[] = {
    3222, 3182, 3142, 3100, 3058, 3014, 2970, 2925,
    2880, 2833, 2787, 2739, 2691, 2643, 2594, 2544,
    2495, 2445, 2396, 2346, 2296, 2246, 2196, 2147,
    2097, 2048, 1999, 1951, 1903, 1855, 1808, 1762,
    1716, 1671, 1626, 1583, 1539, 1497, 1456, 1415,
    1375, 1336, 1297, 1260, 1223, 1187, 1152, 1118,
    1085, 1052, 1021, 990, 960, 931, 903, 875,
    848, 822, 797, 772, 749, 726, 703, 682,
    661, 640, 620, 601, 583, 565, 547, 530,
    514, 498, 483, 468, 454, 440, 427, 414,
    401
};

// This function is calculating temperature in tenth of degree of Celsius
// depending on ADC sum value as input parameter.
static int16_t calc_temperature(temperature_table_entry_type adcsum) {
    temperature_table_index_type l = 0;
    temperature_table_index_type r = (sizeof(termo_table) / sizeof(termo_table[0])) - 1;
    temperature_table_entry_type thigh = TEMPERATURE_TABLE_READ(r);
    
    // Checking for bound values
    if (adcsum <= thigh) {
        #ifdef TEMPERATURE_UNDER
            if (adcsum < thigh) 
                return TEMPERATURE_UNDER;
        #endif
        return TEMPERATURE_TABLE_STEP * r + TEMPERATURE_TABLE_START;
    }
    temperature_table_entry_type tlow = TEMPERATURE_TABLE_READ(0);
    if (adcsum >= tlow) {
        #ifdef TEMPERATURE_OVER
            if (adcsum > tlow)
                return TEMPERATURE_OVER;
        #endif
        return TEMPERATURE_TABLE_START;
    }

    // Table lookup using binary search 
    while ((r - l) > 1) {
        temperature_table_index_type m = (l + r) >> 1;
        temperature_table_entry_type mid = TEMPERATURE_TABLE_READ(m);
        if (adcsum > mid) {
            r = m;
        } else {
            l = m;
        }
    }
    temperature_table_entry_type vl = TEMPERATURE_TABLE_READ(l);
    if (adcsum >= vl) {
        return l * TEMPERATURE_TABLE_STEP + TEMPERATURE_TABLE_START;
    }
    temperature_table_entry_type vr = TEMPERATURE_TABLE_READ(r);
    temperature_table_entry_type vd = vl - vr;
    int16_t res = TEMPERATURE_TABLE_START + r * TEMPERATURE_TABLE_STEP; 
    if (vd) {
        // Linear interpolation
        res -= ((TEMPERATURE_TABLE_STEP * (int32_t)(adcsum - vr) + (vd >> 1)) / vd);
    }
    return res;
}

// PWM generation

static const int fan_curve[][2] = {
    {0, 0},
    {200, 20},
    {800, 80},
    {850, 100},
};

static uint16_t adc_res[2];

#define NUM_SAMPLES (5)
static uint16_t adc_samples[NUM_SAMPLES];
static int adc_sample_index = 0;
static volatile int needs_temp_processing = 0, needs_temp_update = 0;

extern ADC_HandleTypeDef hadc;
extern TIM_HandleTypeDef htim1;
extern TIM_HandleTypeDef htim6;

static int fans_get_speed(int temp) {
    int num_rows = sizeof(fan_curve) / sizeof(fan_curve[0]);
    int i;

    for (i = 0; i < num_rows; i++) {
        if (temp < fan_curve[i][0]) {
            break;
        }
    }

    // return speed at both ends of the table
    if (i == num_rows || i == 1) {
        return fan_curve[i-1][1];
    }

    // linearly extrapolate from the table
    int t1 = fan_curve[i-1][0], s1 = fan_curve[i-1][1];
    int t2 = fan_curve[i][0], s2 = fan_curve[i][1];
    return s1 + (s2 - s1) * (temp - t1) / (t2 - t1);
}

static void fans_configure(uint32_t duty_cycle) {
    TIM_OC_InitTypeDef sConfigOC = {0};

    sConfigOC.OCMode = TIM_OCMODE_PWM1;
    sConfigOC.Pulse = duty_cycle;
    sConfigOC.OCPolarity = TIM_OCPOLARITY_HIGH;
    sConfigOC.OCNPolarity = TIM_OCNPOLARITY_HIGH;
    sConfigOC.OCFastMode = TIM_OCFAST_DISABLE;
    sConfigOC.OCIdleState = TIM_OCIDLESTATE_RESET;
    sConfigOC.OCNIdleState = TIM_OCNIDLESTATE_RESET;
    HAL_TIM_PWM_ConfigChannel(&htim1, &sConfigOC, TIM_CHANNEL_1);
}

static void fans_reconfigure(int off) {
    static int is_pwm_running = 0;
    static int last_speed = 0;
    uint16_t adc_value;
    uint32_t adc_average;
    int16_t temp;
    int fan_speed;

    // adjust for any difference in VREF
    adc_value = adc_res[0] + adc_res[1] - *VREFINT_CAL_ADDR;

    // create rolling average
    do {
        adc_samples[adc_sample_index] = adc_value;
        adc_sample_index = (adc_sample_index + 1) % NUM_SAMPLES;
    } while (adc_samples[adc_sample_index] == 0);
    adc_average = 0;
    for (int i = 0; i < NUM_SAMPLES; i++) {
        adc_average += adc_samples[i];
    }
    adc_average /= NUM_SAMPLES;
    temp = calc_temperature(adc_average);
    fan_speed = fans_get_speed(temp);

    if (last_speed != fan_speed) {
        last_speed = fan_speed;
        fans_configure(fan_speed);
        printf("Fans: ADC = %d, Avg = %ld, T = %d, S = %d\n", adc_value, adc_average, temp, fan_speed);
    }

    if (fan_speed == 0 || fan_speed == 100 || off) {
        if (is_pwm_running) {
            HAL_TIM_PWM_Stop_IT(&htim1, TIM_CHANNEL_1);
            HAL_TIM_Base_Stop_IT(&htim1);
            is_pwm_running = 0;
        }
    }

    if (fan_speed == 0 || off) {
        HAL_GPIO_WritePin(FAN_PWM_GPIO_Port, FAN_PWM_Pin, GPIO_PIN_RESET);
        HAL_GPIO_WritePin(FAN_ON_GPIO_Port, FAN_ON_Pin, GPIO_PIN_RESET);
    } else if (fan_speed == 100) {
        HAL_GPIO_WritePin(FAN_PWM_GPIO_Port, FAN_PWM_Pin, GPIO_PIN_SET);
        HAL_GPIO_WritePin(FAN_ON_GPIO_Port, FAN_ON_Pin, GPIO_PIN_SET);
    } else {
        if (!is_pwm_running) {
            HAL_TIM_Base_Start_IT(&htim1);
            HAL_TIM_PWM_Start_IT(&htim1, TIM_CHANNEL_1);
            HAL_GPIO_WritePin(FAN_ON_GPIO_Port, FAN_ON_Pin, GPIO_PIN_SET);
            is_pwm_running = 1;
        }
    }
}

void fans_start(void) {
    HAL_ADCEx_Calibration_Start(&hadc);
    HAL_TIM_Base_Start_IT(&htim6);
}

void fans_stop(void) {
    HAL_TIM_Base_Stop_IT(&htim6);
    fans_reconfigure(1);
}
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

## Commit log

2024-03-23 Updated schematics
    [1-1775099-3.step, PCIe_Redriver.kicad_sch, TPS2003CDRCR.stp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]
2024-03-23 Continue working on board layout
    [USB_C_DFPs.kicad_sch, USB_Hub.kicad_sch, XG_Mobile_Dock.kicad_pcb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]
2024-03-24 Lay out more components
    [PCIe_Redriver.kicad_sch, USB_C_DFPs.kicad_sch, USB_Hub.kicad_sch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]
2024-03-24 Updated board layout
    [AP7331-10WG-7.STEP, KEYSTONE_8730.step, TS-1187A-B-A-B.STEP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]
2024-03-25 Fix unconnected GND
2024-03-25 Misplaced one track on 20P connector
2024-04-21 Add power components
    [PCIE_Leech.kicad_pcb, PCIE_Leech.kicad_sch, Power.kicad_sch]
2024-04-24 Add TPS65987D charger circuit
    [USB_Hub.kicad_sch, USB_PD_Charger.kicad_sch, XG_Mobile_Dock.kicad_sch]
2024-04-24 Replace AOSP21321 with AON7403 and update 3D models
    [ASPI-0630LR-100M-T15.STEP, USB_PD_Charger.kicad_sch]
2024-04-25 new power blocks
    [1-1775099-3.step, POWERDI5_DIO.step, Power.kicad_sch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]
2024-04-25 Laid out components for power circuits
    [Power.kicad_sch, USB_PD_Charger.kicad_sch]
2024-04-26 Rewired PCIe without redriver
    [PCIe_Redriver.kicad_sch, Power.kicad_sch, XG_Mobile_Dock.kicad_sch]
2024-04-26 Add CC values to DFP ports
    [USB_C_DFPs.kicad_sch]
2024-04-26 Renamed some connector pins
    [XG_Mobile_Dock.kicad_sch]
2024-04-27 Added MCU
    [PCIe_Redriver.kicad_sch, Power.kicad_sch, USB_Hub.kicad_sch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]
2024-04-27 Fixed all DRC errors
    [PCIe_Redriver.kicad_sch, Power.kicad_sch, USB_C_DFPs.kicad_sch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]
2024-04-27 Replaced 12.4k resistor with two basic parts
    [Power.kicad_sch, USB_Hub.kicad_sch, USB_PD_Charger.kicad_sch]
2024-04-28 Increased inductor size
    [PCIe_Redriver.kicad_sch, Power.kicad_sch, USB_C_DFPs.kicad_sch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]
2024-05-04 Fixed USB Hub wrong net 1V0 -> 3V3
    [USB_Hub.kicad_sch, USB_PD_Charger.kicad_sch]
2024-05-11 Improvements to board
    * Break up power switch into input and output signals
    * Removed POWER_EN from USB PD charger (GPIO does not work due to one event per pin)
    * Added MOSFET to buffer GPIO output from PD IC
    [USB_PD_Charger.kicad_sch, XG_Mobile_Dock.kicad_sch]
2024-05-18 Fixed power connector, PCIe direction, and MCU changes
    [XG_Mobile_Dock.kicad_sch]
2024-05-18 Add MCU schematics
    [MCU.kicad_sch]
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2024-05-18 Remove PCIe leech project
    [PCIE_Leech.kicad_pcb, PCIE_Leech.kicad_sch]
2024-07-01 Update firmware for rev 3 board
2024-07-03 Fix flipped MOSFETs for PDO signals
    [USB_PD_Charger.kicad_sch]
2024-07-03 Mislabeled I2C pin GND and 3V3
2024-07-05 Fix external board power toggle
    [XG_Mobile_Dock_MCU.ioc, xg_mobile_dock.c]
2024-07-14 Replace TH PCI-E slot with SMD
    [XG_Mobile_Dock.kicad_sch]
2024-07-14 Add external board detect pin to MCU
    [MCU.kicad_sch, XG_Mobile_Dock.kicad_sch]
2024-07-14 Fix missing GND connection & update name
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2024-07-18 Add external board detect to MCU
2024-07-19 Added 3D model of new PCI-E slot
    [10061913-103TLF--3DModel-STEP-56544.STEP]
2024-07-21 Fix I2C issue when 0xE6 is spammed
    [xg_mobile_dock.c]
2024-07-28 Increase thermal mass under 1V0 LDO
    [USB_Hub.kicad_sch]
2024-07-28 Ensure SPI flash is powered on even when board loses power
    [USB_PD_Charger.kicad_sch]
2024-07-31 Replace AP7331-10WG-7 with AP7361-10ER-13 to handle power draw
    [AP7331-10WG-7.STEP, AP7361-10ER-13.stp, USB_Hub.kicad_sch]
2024-08-02 Increased heat sink area of 1V0 LDO
2024-08-06 Add power riser design
    [Riser_F.kicad_pcb, Riser_F.kicad_sch, Riser_M.kicad_pcb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]
2024-08-06 MCU: move external board toggle to cable connect time
2024-08-07 pcb: added lite variant
    [1-1775099-3.step, 3-1775099-2.stp, XG_Mobile_Dock_Lite.kicad_pcb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]
2024-08-08 pcb: redesign lite for the ADT-UT3G
    [039300240.stp, 469911008.stp, XG_Mobile_Dock_Lite.kicad_pcb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]
2024-08-08 pcb: add 12V pad for external fan connection
    [XG_Mobile_Dock_Lite.kicad_pcb, XG_Mobile_Dock_Lite.kicad_sch]
2024-08-23 pcb: use 0.3/0.4 vias for reduced cost on lite design
    [XG_Mobile_Dock_Lite.kicad_pcb]
2024-08-31 pcb: redid layout for USB hub
    [USB_C_DFPs.kicad_sch, USB_Hub.kicad_sch, XG_Mobile_Dock.kicad_sch]
2024-09-01 pcb: updated all via sizes to >= 0.4/0.3
    [XG_Mobile_Dock.kicad_sch]
2024-09-01 pcb: replaced 20P slot with mirrored connector
    [MCU.kicad_sch, Power.kicad_sch, XG_Mobile_Dock.kicad_sch]
2024-09-01 pcb: improve thermal reliefs for pth
    [XG_Mobile_Dock.kicad_sch]
2024-09-01 pcb: move 20P crossover to cable
    [XG_Mobile_Dock.kicad_sch]
2024-09-24 pcb: add USB hub test board
    [USB_Hub.kicad_sch, USB_Hub_Test.kicad_pcb, USB_Hub_Test.kicad_sch]
2024-09-24 pcb: add project file for lite board
2024-09-24 pcb: add EPS12V adapter
    [EPS12V_Adapter.kicad_pcb, EPS12V_Adapter.kicad_sch]
2024-09-24 pcb: connect SPI flash to VIA IC
    [USB_Hub.kicad_sch, XG_Mobile_Dock.kicad_sch]
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2024-10-24 xgmdriver: add empty project to inhibit ASUS driver popup
2024-11-03 ti: updated charger project to use 65W and ASUS VID
2024-11-10 mcu: turn on red light when power is on
2024-11-10 driver: fix incorrect model in setup
2024-12-10 pcb: add 12V PCIe power converters
    [0455860005.stp, IHLP6767GZ.step, LM5117PMH.stp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]
2024-12-12 pcb: added fans and thermistor to standard pcb
    [470531000.stp, MCU.kicad_sch, Power_12V.kicad_sch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]
2024-12-12 pcb: changed 1206 capacitors to 1210 since they are easier to source
    [Power_12V.kicad_sch]
2024-12-13 pcb: reduced gate resistor in schematic review
    Also updated some missing attributes.
    [MCU.kicad_sch, Power_12V.kicad_sch, XG_Mobile_Dock.kicad_sch]
2024-12-13 pcb: changed standard board to 6 layer because it is cheaper on JLCPCB
2024-12-25 pcb: reset size of alignment holes for PCIe slot
    [XG_Mobile_Dock_Lite.kicad_pcb]
2025-01-10 pcb: fixed fan capacitor and changed case led resistor value
    [MCU.kicad_sch]
2025-01-10 mcu: add PWM fan control
    Also changed clock to 32MHz in order to handle PWM GPIO.
2025-01-11 pcb: disable hiccup mode on psu
    [Power_12V.kicad_sch]
2025-01-14 pcb: restore gnd connection to mounting screw
    [XG_Mobile_Dock.kicad_sch]
2025-01-16 pcb: add pwm fans to lite board
    [XG_Mobile_Dock_Lite.kicad_pcb, XG_Mobile_Dock_Lite.kicad_sch]
2025-01-16 pcb: correct I2C labels on lite board
    [XG_Mobile_Dock_Lite.kicad_pcb]
2025-01-17 pcb: fixed wrong voltage decoupling capacitor for PP_HV
    [USB_PD_Charger.kicad_sch]
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2025-05-04 power: added power board
    [TL1250FxxxxxRCLR.stp, XG_Station_Power.kicad_pcb, XG_Station_Power.kicad_sch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]
2025-05-04 project: remove unused files
    [EPS12V_Adapter.kicad_pcb, EPS12V_Adapter.kicad_sch, Riser_F.kicad_pcb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]
2026-01-15 pcb: add PWON# and power LED to lite board
    [XG_Mobile_Dock_Lite.kicad_pcb, XG_Mobile_Dock_Lite.kicad_sch]
2026-01-15 pcb: fix track width for co-planar waveguide
    [XG_Mobile_Dock_Lite.kicad_pcb]
2026-01-16 pcb: fix +3.3V rail for cable LED
    [XG_Mobile_Dock_Lite.kicad_pcb, XG_Mobile_Dock_Lite.kicad_sch]
2026-11-02 setup: fix AMD model name (GC33L -> GC32L)
    The AMD option wrote "GC33L", which is not a model the driver knows. It
    only behaved as AMD because unknown models fall through to the GC32L
    branch in ParseModel.
    Assisted-by: Claude:claude-opus-5-5
2026-11-02 devinstall: add deletedriver command
    Add "devinstall deletedriver <inf>", which deletes every oem*.inf driver
    package whose original INF file name matches, using
    SetupQueryInfOriginalFileInformation and SetupUninstallOEMInf with
    SUOI_FORCEDELETE.
    The uninstaller currently runs "pnputil /delete-driver <path to
    XGMDriver.inf>", but pnputil expects the published name (oemNN.inf),
    so it fails and leaves the package in the driver store. Matching on the
    original name needs no output parsing and also removes packages left by
    earlier installs.
    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
2026-11-02 setup: remove stale devices and driver packages properly
    Use "devinstall removeall" instead of "remove" on install and uninstall.
    "remove" only matches devices that are currently present, so devices
    that were not present at the time were left behind with their old
    configuration.
    Replace "pnputil /delete-driver <path>", which fails because pnputil
    needs the published oemNN.inf name, with "devinstall deletedriver
    xgmdriver.inf". Install now also deletes packages left by earlier
    installs before installing the new one.
    Treat exit code 1 from removeall (reboot required) as a reboot request
    instead of a failure.
    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
2026-11-02 xgmdriver: select the spoofed model by hardware ID instead of the registry
    The installer wrote the model to
    HKLM\SOFTWARE\Microsoft\Windows NT\CurrentVersion\WUDF\Services\XGMDriver\Parameters,
    a key that Windows owns through the INF's UmdfService directive and
    rebuilds from the INF. On the 2025 feature update the device was
    migrated and its driver re-installed from the INF, the value was
    dropped, and the driver silently fell back to the AMD GC32L, which
    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
2026-11-02 setup: add optional XGM disconnect loop workaround
    ARMOURY CRATE SE Service 3.1.3 loads ThrottleMonitorPlugin\MonitorPlugin.dll
    into its user session helper. On any display adapter arrival or removal
    its GPUControlLibrary.dll calls ADLXTerminate and then releases ADLX
    objects, and the helper crashes in amdadlx64.dll. The helper also runs
    the GPU switch, so eGPU activation is cut off mid-switch, retried by the
    restarted helper, and the XGM connects and disconnects in an endless
    loop.
    Add an optional "XGM disconnect loop workaround" component that removes
    the MonitorPlugin.dll line from ThrottleMonitorPlugin\Load.conf and
    restarts ArmouryCrateSEService. The rest of the file is kept
    byte-for-b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
2026-11-02 setup: stop Armoury Crate around device removal; clean up failed installs
    Removing the old device was vetoed (PNP_VetoOutstandingOpen) because
    Armoury Crate keeps the virtual HID device open, so removal was deferred
    to a reboot. Stop ArmouryCrateSEService before removing the device on
    install and uninstall, and start it again afterwards if it was running.
    "devinstall install" creates the device before installing the driver on
    it, so a failed driver install (for example a catalog that does not
    chain to the installed root certificate) left a device with no driver.
    Remove that device in the failure path.
    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
2026-11-02 xgmdriver: build attestation submissions and package the installer separately
    Windows only installs Microsoft-signed driver packages where Code
    Integrity is enforced, which includes every ARM64 machine. An EV signature
    alone is rejected there with "Driver package signer is not trusted by
    system, and Code Integrity is enforced" (0xE0000243), even with the root
    and publisher trusted. On x64 it also needs the issuing root to be present
    already: driver installation never downloads a missing root, so a new
    root such as IdenTrust Commercial Root Code Signing RSA CA 2 fails with
    0x800B010A on machines that have not seen it yet. The EV certificate is
    instead used to submit the driver for Microsoft a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

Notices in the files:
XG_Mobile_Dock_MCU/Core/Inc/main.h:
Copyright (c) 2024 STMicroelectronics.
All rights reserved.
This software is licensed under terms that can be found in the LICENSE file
